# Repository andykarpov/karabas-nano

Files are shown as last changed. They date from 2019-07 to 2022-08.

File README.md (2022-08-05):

# Karabas-Nano

**Yet another ZX Spectrum clone ;)**

## Intro

ZX Spectrum compatible machine with real **Z80** CPU and all logic inside the CPLD Altera **EPM3256ATC144** (or EPM7512).

## The idea

The idea was to learn KiCAD and make a **cheapest** and **smallest** ZX Spectrum clone with minimum components and real CPU. 
Some parts of this schematics are grabbed from the **Karabas-128** and **ZX-UNO** projects (like RGB DAC, PAL coder, Tape-in logic).
The heart of this project is a real SMD Z80 CPU and ULA implementation on Altera CPLD EPM3256ATC144. 

## Firmwares

The board contains an SD card socket, so at least 2 different configurations are supported:

1) Z-Controller based configuration (Pentagon timings, GLUK reset service in the ROM bank 0, 1024kB of extended memory via port #DFFD (Profi))

2) DivMMC based configuration (Pentagon timings, ESXDOS 0.8.7 in the ROM bank 0, 128kB of memory)

## More info

**ERRATA for PCB rev.A:** [Russian](https://github.com/andykarpov/karabas-nano/blob/master/ERRATA_revA.md).

**ERRATA for PCB rev.B:** [Russian](https://github.com/andykarpov/karabas-nano/blob/master/ERRATA_revB.md).

**Latest revision:** rev.I.

License for this project is **WTFPL**. [More details here](https://github.com/andykarpov/karabas-nano/blob/master/LICENSE.md).

### Pre-production renders

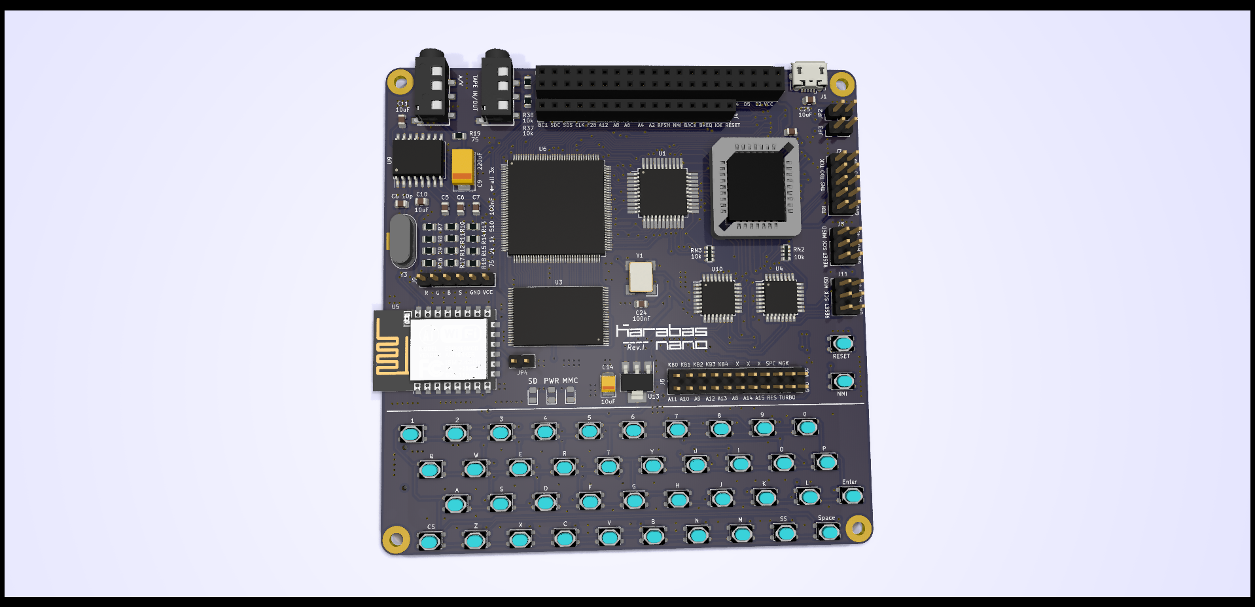
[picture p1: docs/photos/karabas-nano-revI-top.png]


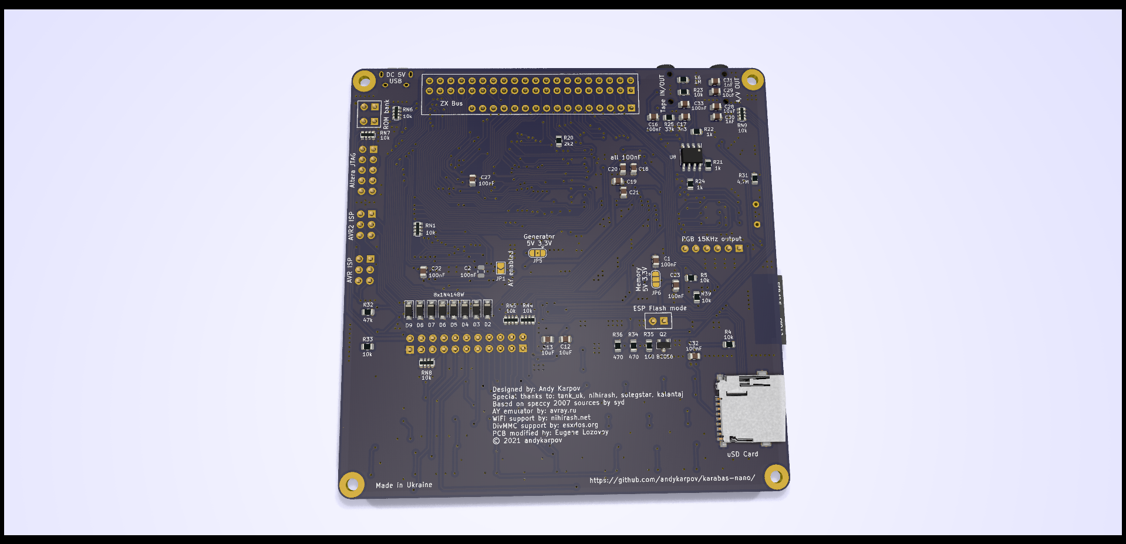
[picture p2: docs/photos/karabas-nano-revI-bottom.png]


### PCB Rev. H assembly example by [Xoomoh (Михайло Капітанов)](https://github.com/xoomoh/)

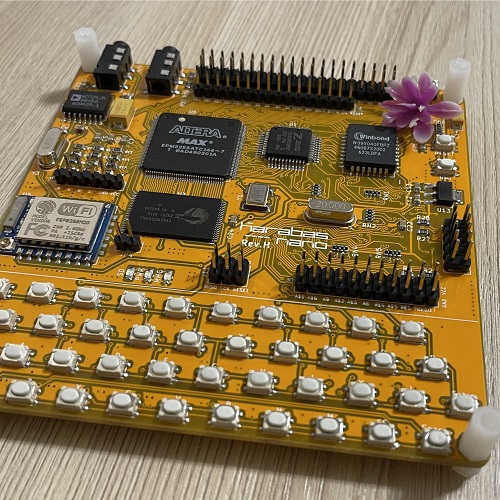
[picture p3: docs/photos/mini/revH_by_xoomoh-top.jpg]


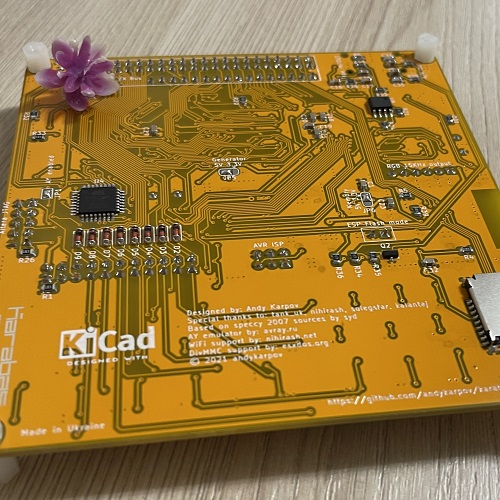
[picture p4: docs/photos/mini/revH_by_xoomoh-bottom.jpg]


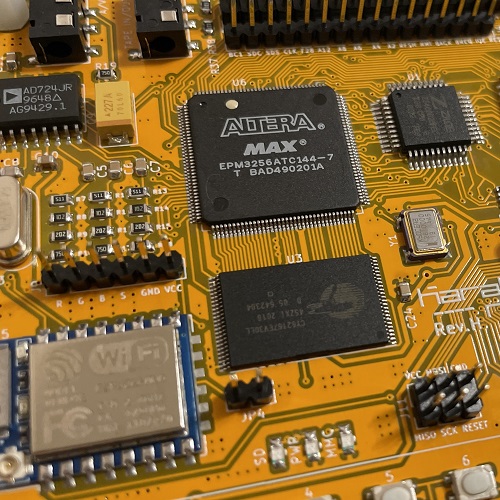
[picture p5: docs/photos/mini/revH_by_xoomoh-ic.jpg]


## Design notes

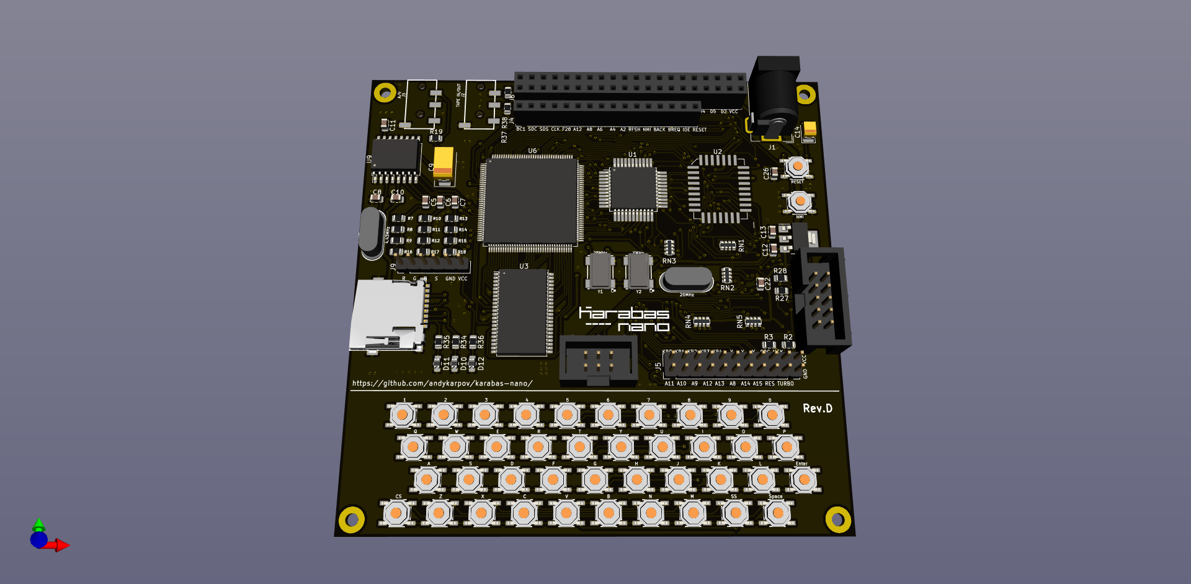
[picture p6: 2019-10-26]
docs/photos/revD-1.png

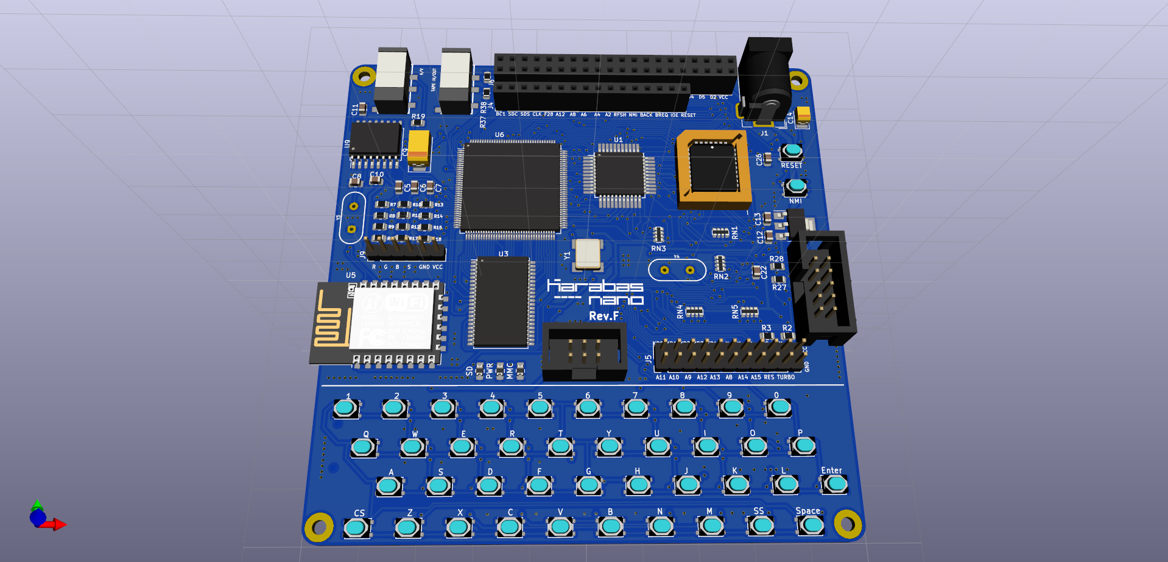
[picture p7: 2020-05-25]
docs/photos/revF-top.png

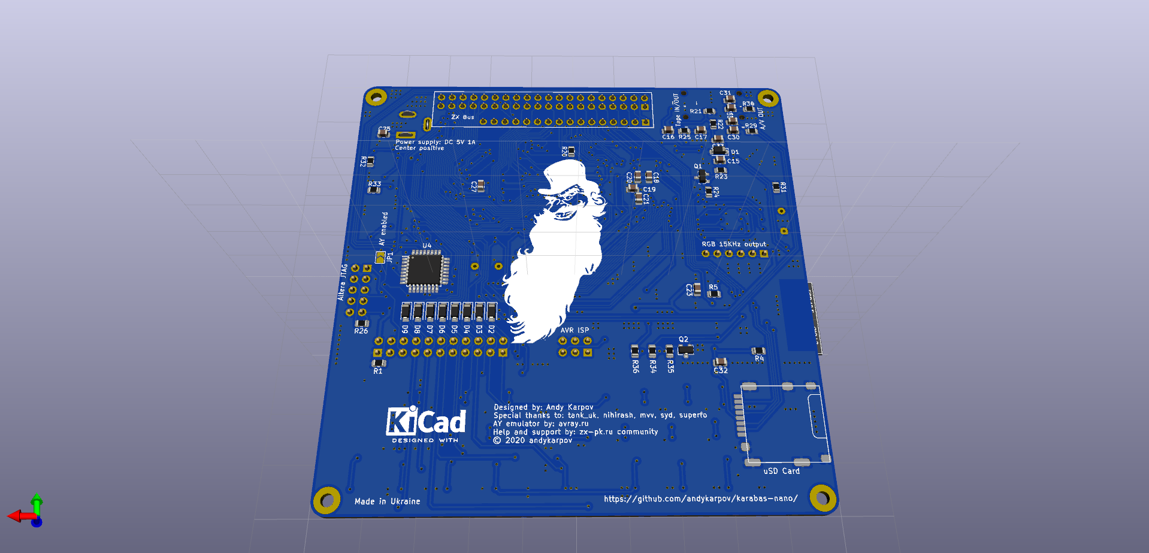
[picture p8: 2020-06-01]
docs/photos/karabas-nano-revG-bottom.png

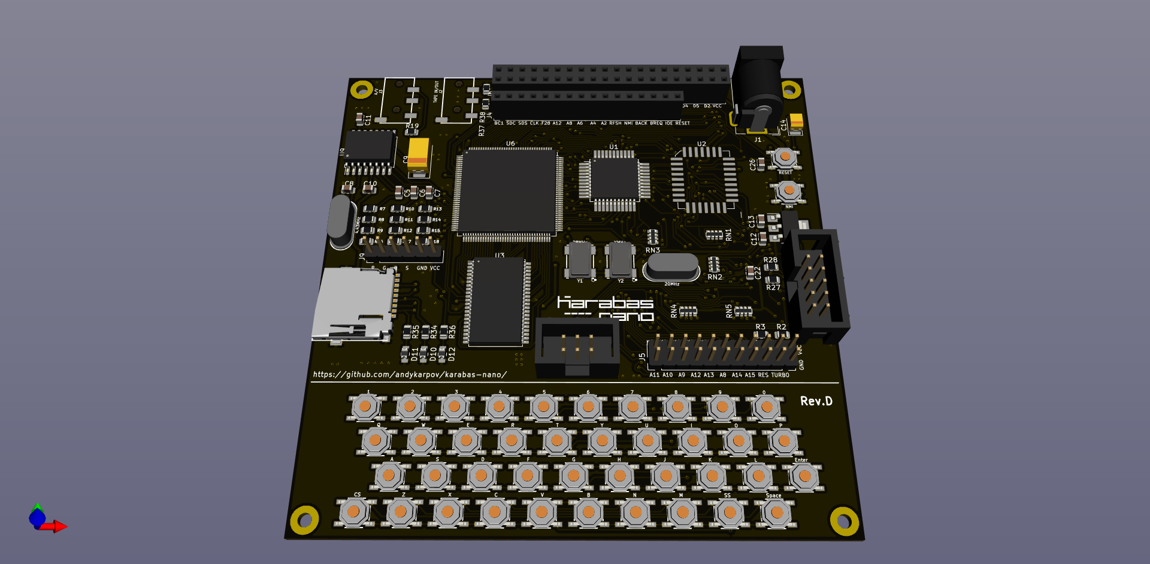
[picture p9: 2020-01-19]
docs/photos/revD.png

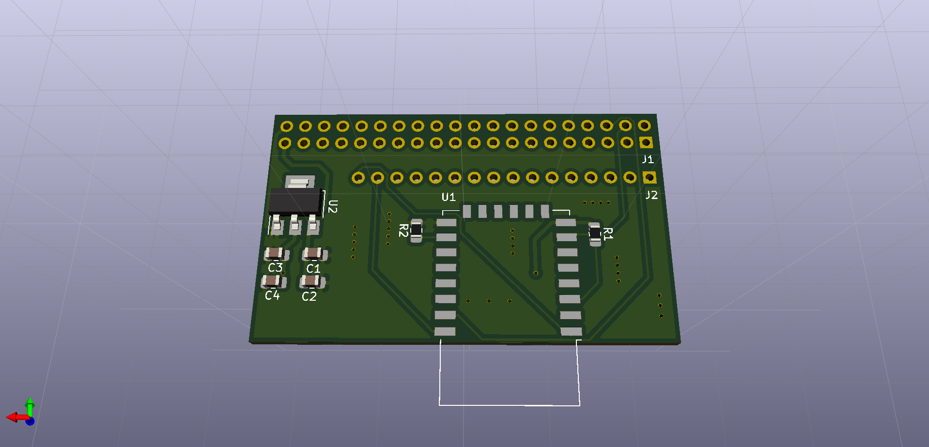
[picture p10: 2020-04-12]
docs/photos/wifi_revA-bottom.png

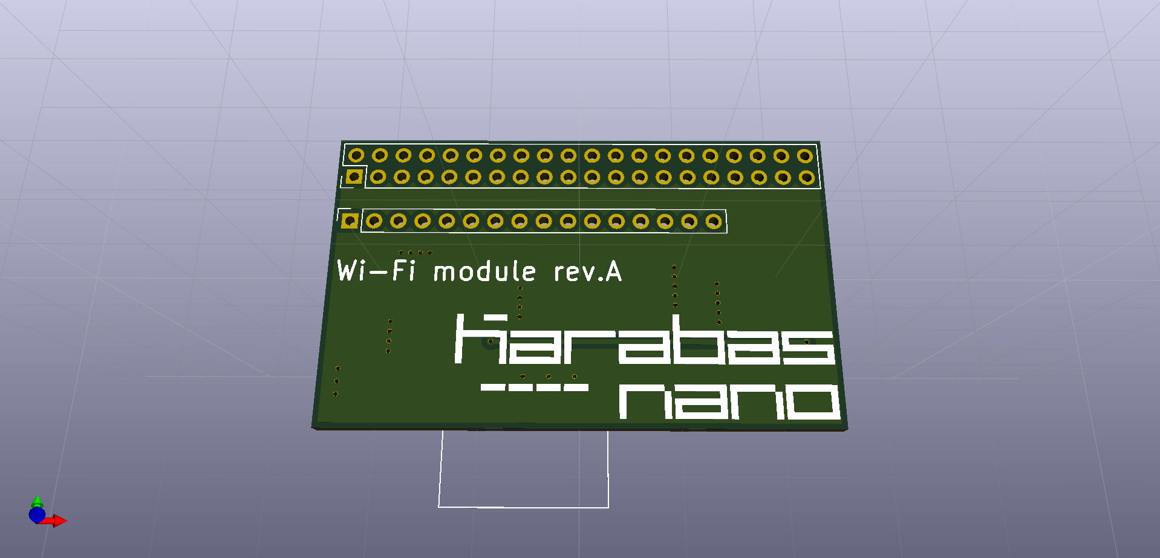
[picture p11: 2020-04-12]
docs/photos/wifi_revA.png

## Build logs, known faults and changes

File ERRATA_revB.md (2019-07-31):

1) BUS_N_ROMCS - нет pull-down 10к резистора в схеме и на плате
2) BUS_N_IORQGE - нет pull-down 10k резистора в схеме и на плате
3) TAPE_IN - нет конденсатона 10нФ последовательно с R22 в схеме и на плате
4) Footprint под Z80 имеет некоррентный размер QFP-10x10mm, а нужен QFP-12x12mm, приходится гнуть ноги у процессора
5) Разъем JTAG - если ставить shrouder header, налазит на рядом стоящие резисторы (подвинуть или одно, или другое)
6) SRAM - отсутствует подача питания на пины 11 - VCC, 12 - GND (как оказалось - не критично).
7) LED - необходим светодиод для индикации подачи питания на плату (предусмотреть)
8) Нет возможности зашить Atmega8 на плате, нужно вывести JTAG пины и возможность не питать всю схему при программировании AVR (solder jumper?)
9) Нет джампера для (возможного) одключения DivMMC в режиме DivMMC.
10) У разъема клавиатуры нет выхода +5,GND для питания внешнего контроллера, предусмотреть, согласовать с разводкой ps2_avr_cpld
11) Нет pull-up резистора на линии SD_NCS, не критично, но нужно предусмотреть
12) Генератор: на 28МГц на 74HTC04 заводится с трудом, выкинуть C1 и заменить перемычкой, заменить в схеме 74HC04 на ACT или F серию, пересчитать номиналы
13) Footprint у 27C512 имеет достаточно короткие пятаки, паять панель руками очень неудобно. Предусмотреть либо длинные PADы, либо другую панель (THT).
14) Кварц на 4.43 МГц нужно заземлить, как и остальные кварцы по возможности
15) Параллельно кварцу на 4.43 МГц предусмотреть резистор на 4.7 МОм
16) Держатель карты SD нужно заземлить
17) Для того, чтобы конденсатор C14 полностью разряжался, для нормального старта конфы DivMMC, необходимо параллельно ему предусмотреть резистор на 47к.
18) Кнопку NMI лучше заводить не на процессор N_MNI, а через модуль DivMMC, который устранит дребезг и включит NMI только при всех условиях, разрешающих его
19) Предусмотреть светодиоды активности DivMMC (mapcond, cs)
20) Добавить подписи контактов на ZX-BUS, KBD хедерах

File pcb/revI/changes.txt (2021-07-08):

Изменения относительно ревизии H:
1. Добавлена вторая ATmega для TurboSound;
2. ATmega тактируется от 28МГц вместо 20МГц. В связи с этим вместо ATmega8 рекомендуется ATmega88;
3. Изменена распиновка AV-выхода для совместимости с кабелями от Raspberry Pi;
4. Перемещены разъёмы программирования CPLD и AVR, а так же кнопки Reset и NMI;
5. Диаметр отверстий в углах платы изменён с 2.5 до 2.7мм.

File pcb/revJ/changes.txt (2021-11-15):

Изменения относительно ревизии I:
1. Изменен футпринт TRRS разъемов, можно ставить выводные вместо SMD
2. Добавлены джамперы переключения типа AV кабеля

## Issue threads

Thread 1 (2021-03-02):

Перепутаны левый и правый каналы аудио

UzixLS, 2021-03-02:
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
Вроде как должно быть наоборот. Но со стороны AVR-AY тоже может быть неправильный порядок, в их референсной схеме есть оба варианта :)

Cтандартная распиновка:
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

andykarpov, 2021-07-08:
хммм... спасибо за инфу, теперь даже хз, как проще сделать.

есть 3 варианта:
- забить и оставить как есть :)
- переделать схему и выпустить новую ревизию платы
- переключить программно в прошивке меги

склоняюсь больше к первому варианту :)))

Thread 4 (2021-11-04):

Revision I

awesome1possum, 2021-11-04:
Ревизия I в ручном режиме открывается в DipTrace.
Но не могу импортировать в онлайн PCB-делалку, только ревизия H (и более ранние). Скрипт пишет что не может определить границы платы, а так же пишет что почему-то нестандартное название файлов.

andykarpov, 2022-02-02:
начина с ревизии I проект делался в KiCAD 6.0, отсюда могут быть вопросы.
сервис pcbway.com нормально кушает эти герберы, у jlc были какие-то вопросы :)

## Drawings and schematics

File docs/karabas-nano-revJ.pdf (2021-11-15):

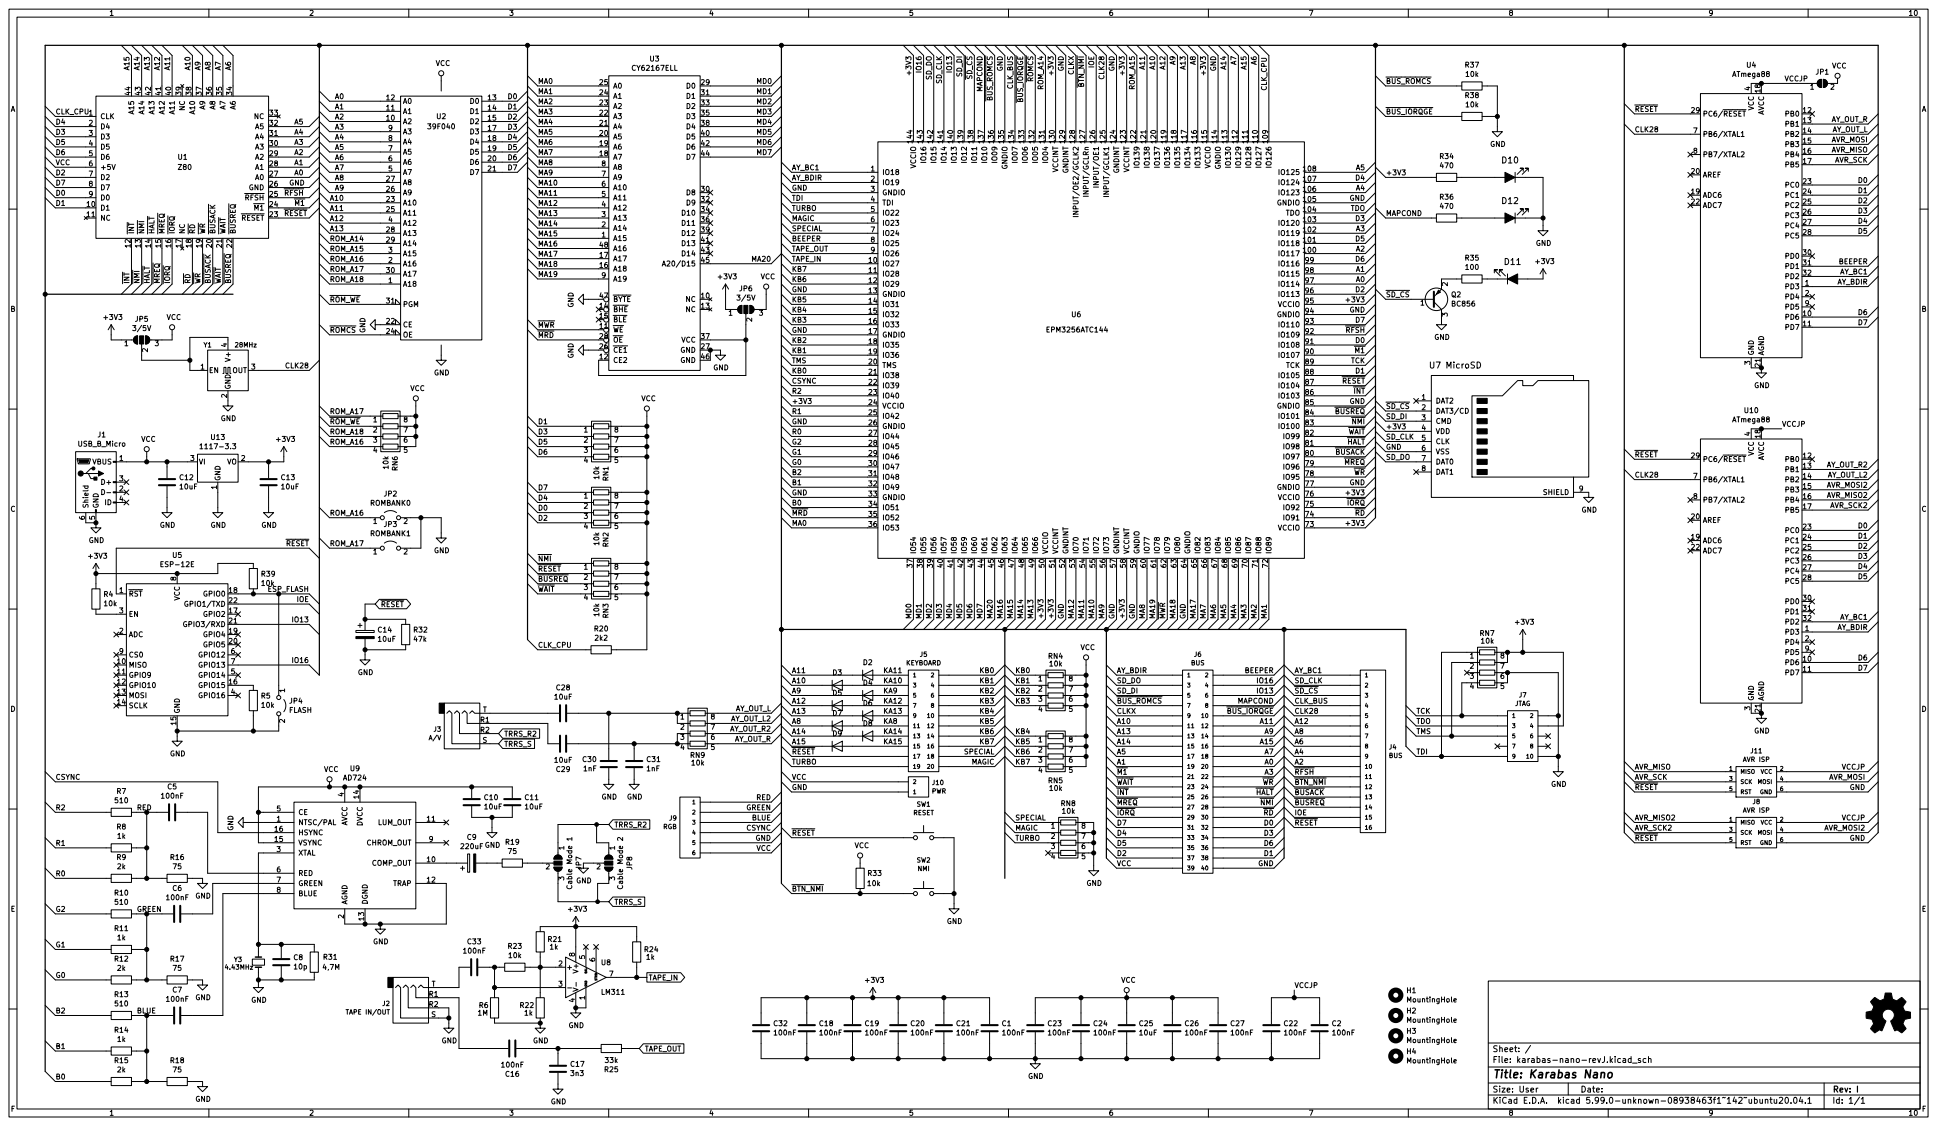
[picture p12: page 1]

4 CE 5 RED 6 GREEN 7 BLUE 8 CHROM_OUT 9 U9 AD724 GND
GND

J2 TAPE IN/OUT GND

File: karabas-nano-revJ.kicad_sch Sheet: /
Id: 1/1 Title: Karabas Nano

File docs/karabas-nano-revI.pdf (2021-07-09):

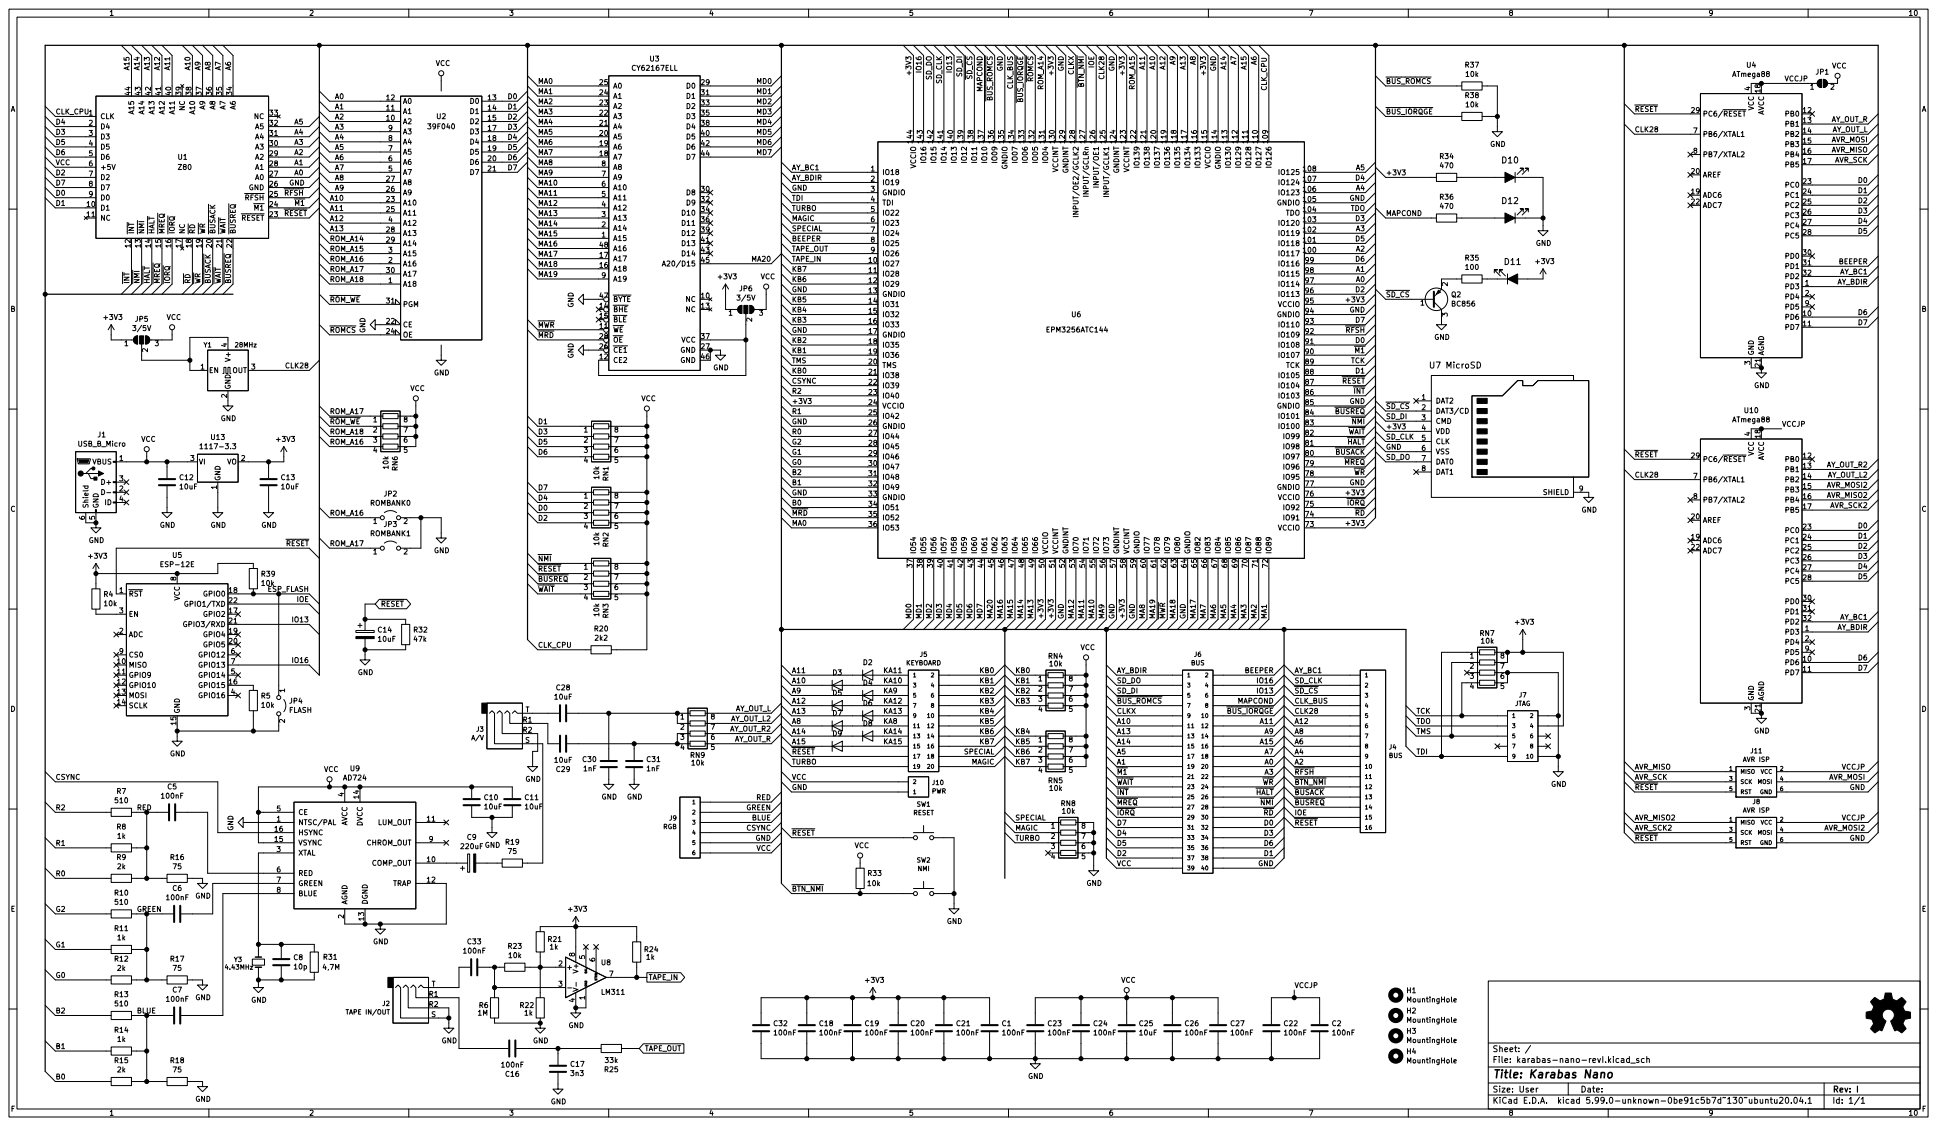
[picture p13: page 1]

4 CE 5 RED 6 GREEN 7 BLUE 8 CHROM_OUT 9 U9 AD724 GND

File: karabas-nano-revI.kicad_sch Sheet: / S

Id: 1/1 Title: Karabas Nano

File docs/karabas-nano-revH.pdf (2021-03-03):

10k R38

470R35

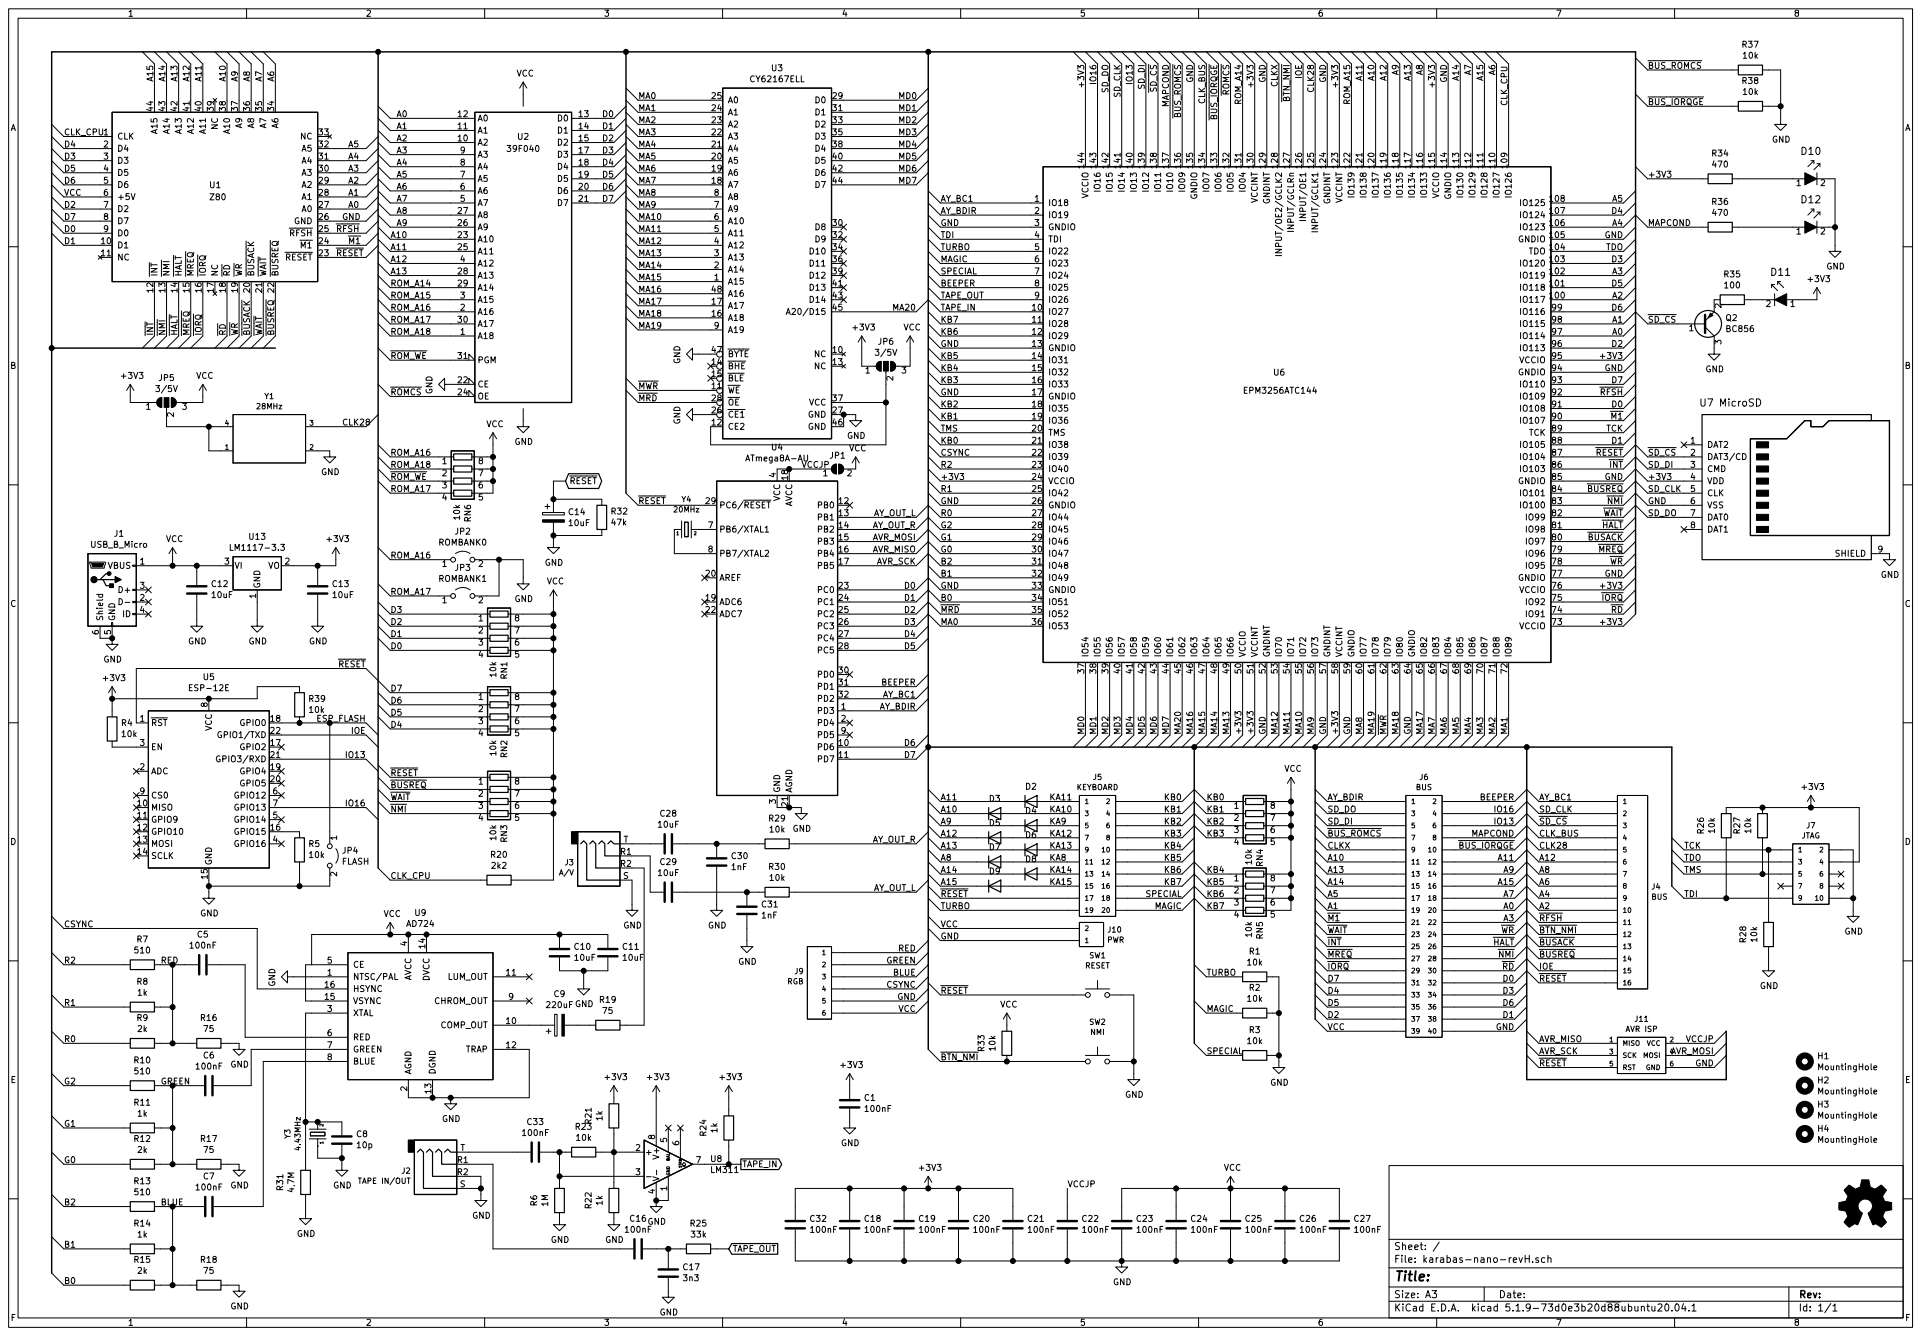
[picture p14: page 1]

4 CE 5 RED 6 GREEN 7 BLUE 8 CHROM_OUT 9 U9 AD724 GND

NMI WAIT HALT BUSACK

Id: 1/1 Title: File: karabas-nano-revH.sch Sheet: / R12

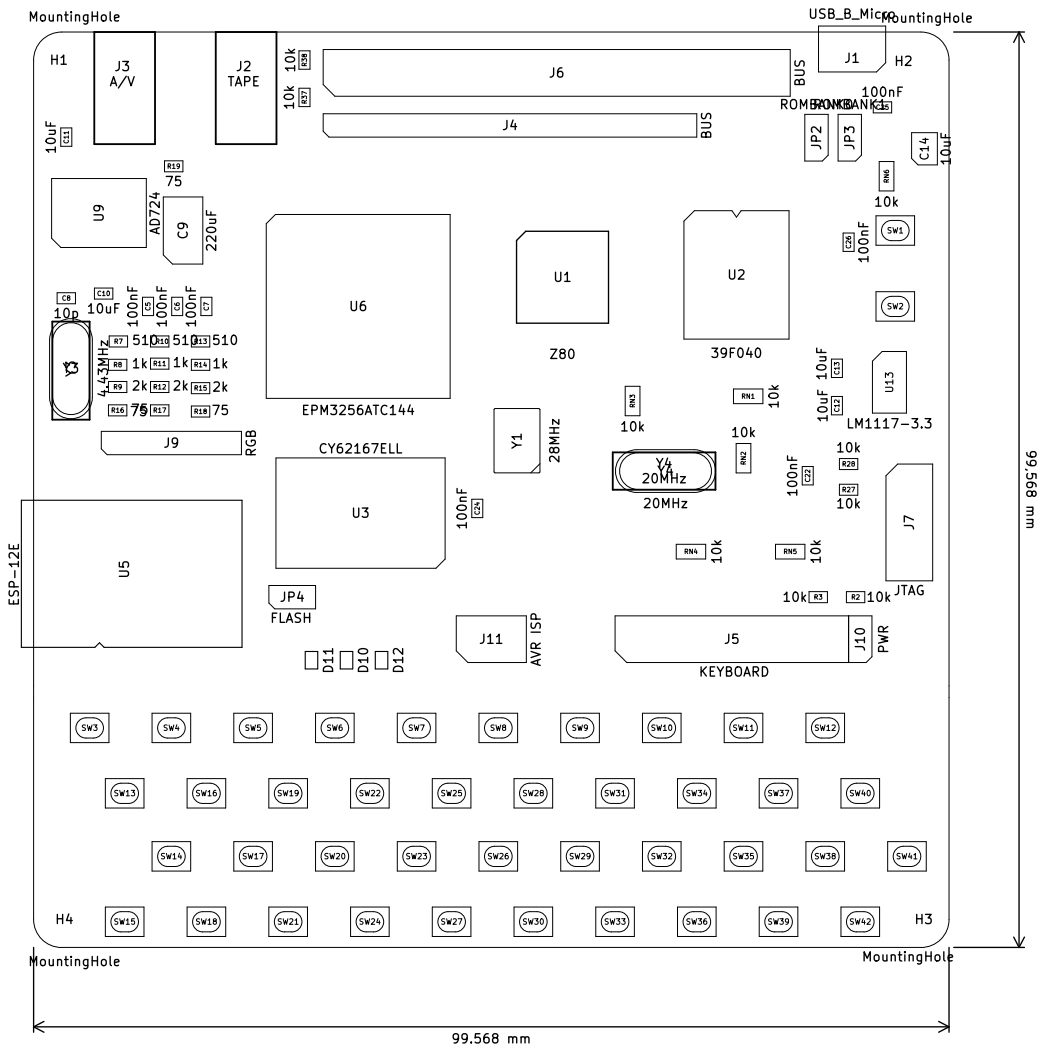
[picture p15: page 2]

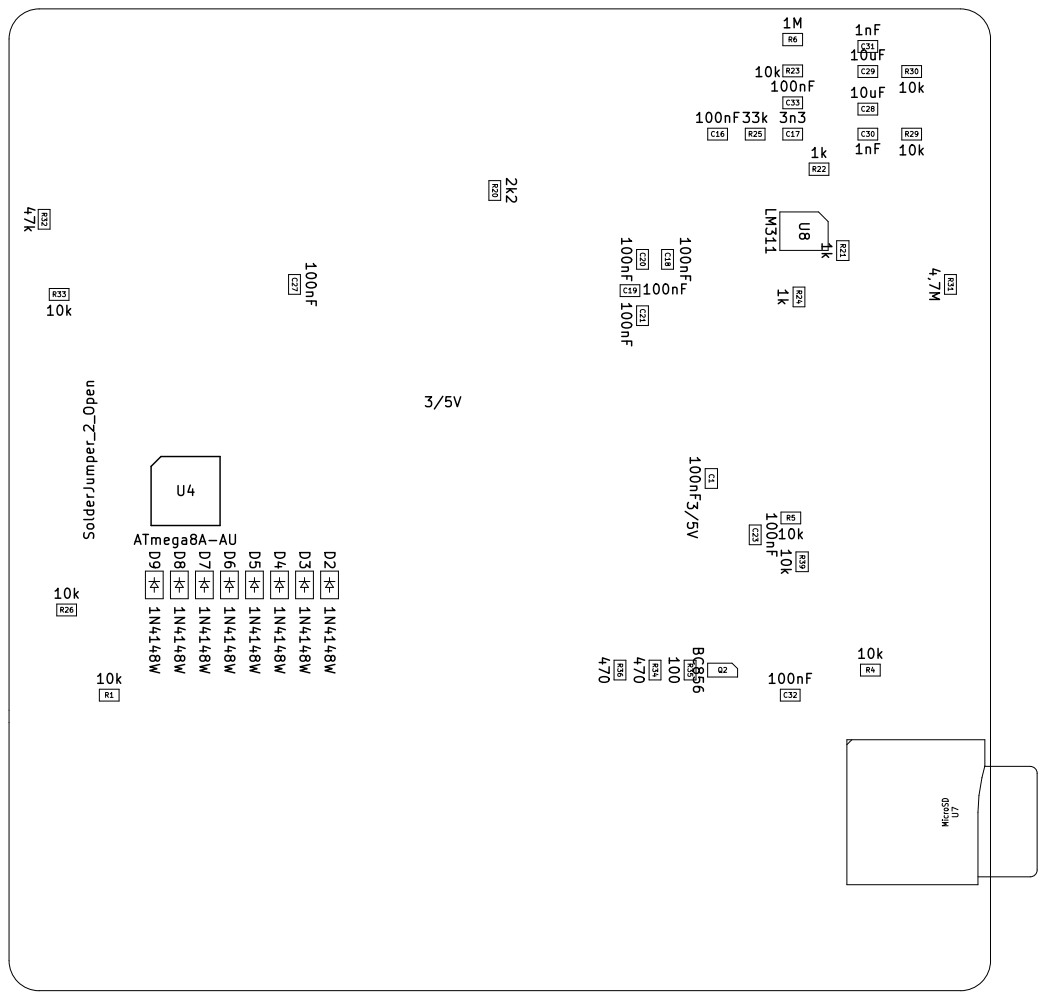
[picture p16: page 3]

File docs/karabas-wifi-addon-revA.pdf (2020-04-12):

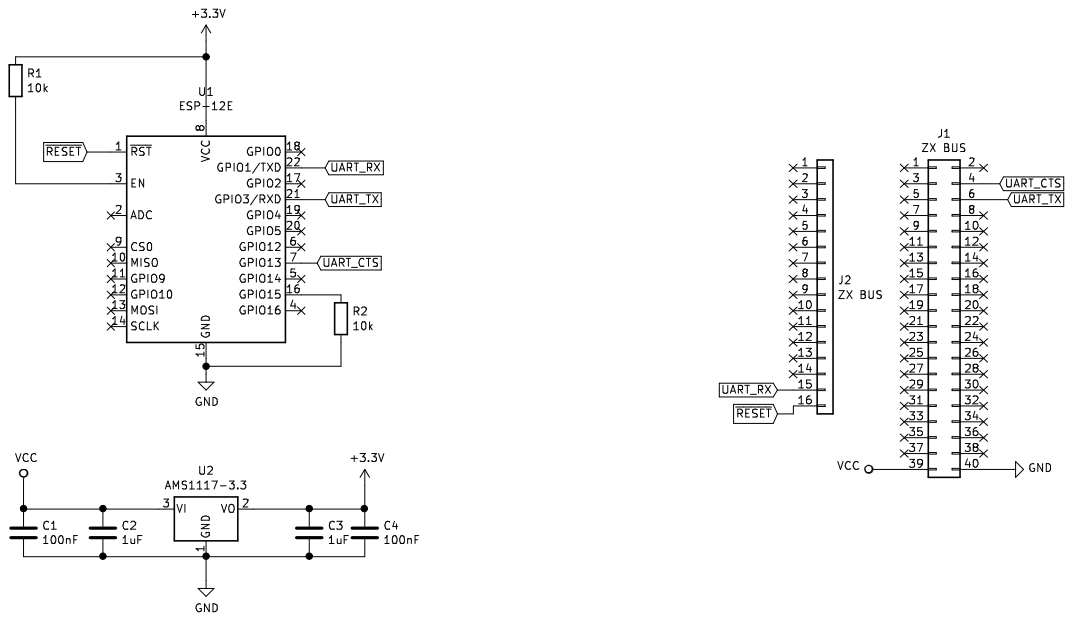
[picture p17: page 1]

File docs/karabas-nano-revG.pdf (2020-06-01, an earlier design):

# IO19 2 TMS 20

# IO46 29 GNDIO 3

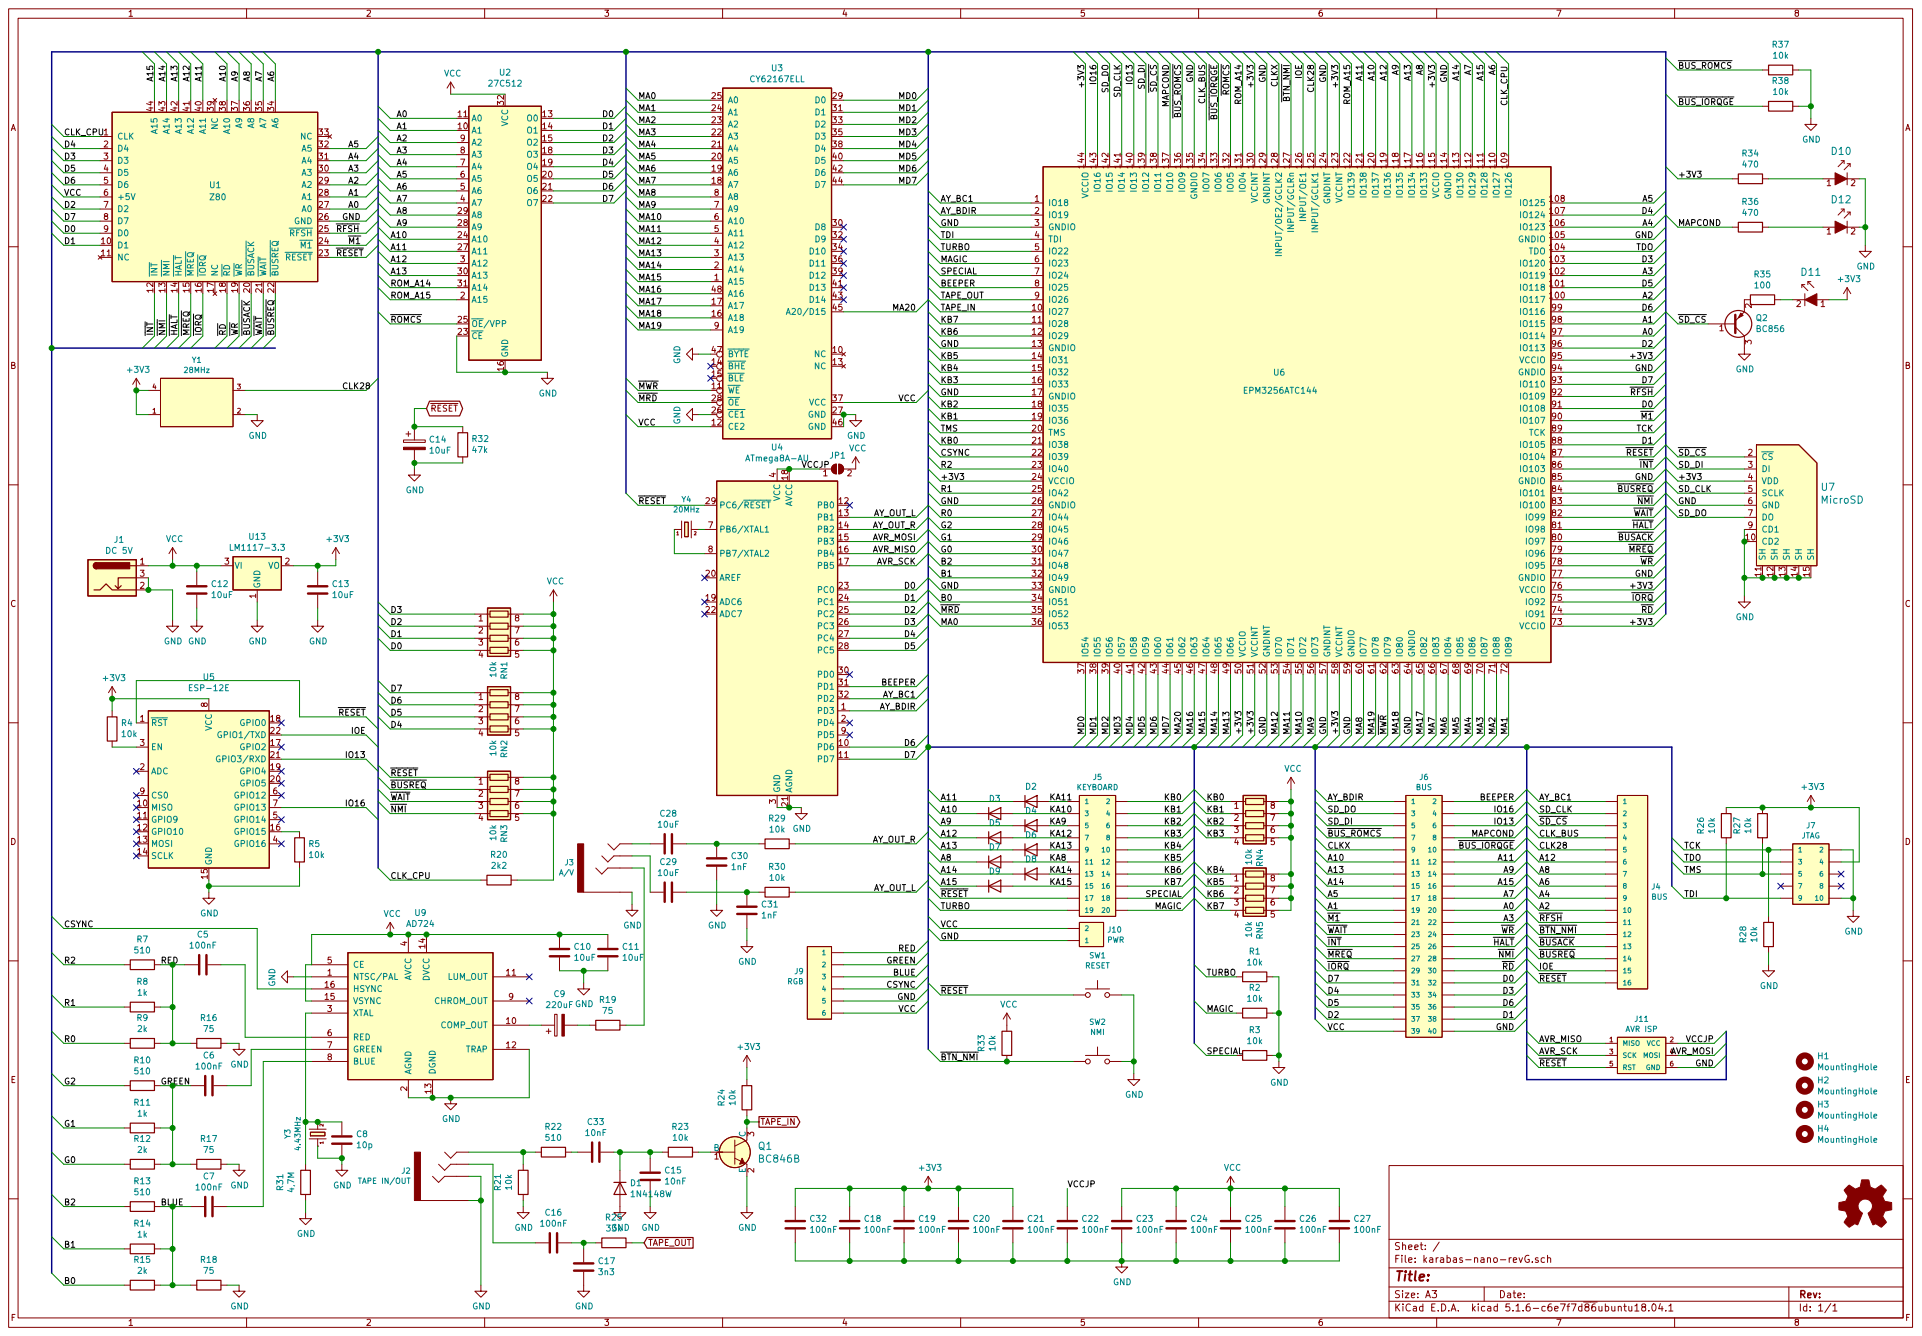
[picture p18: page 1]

RESET BUSREQ WAIT NMI

4 CE 5 RED 6 GREEN 7 BLUE 8 CHROM_OUT 9 U9 AD724

Id: 1/1 Title: File: karabas-nano-revG.sch Sheet: / GND

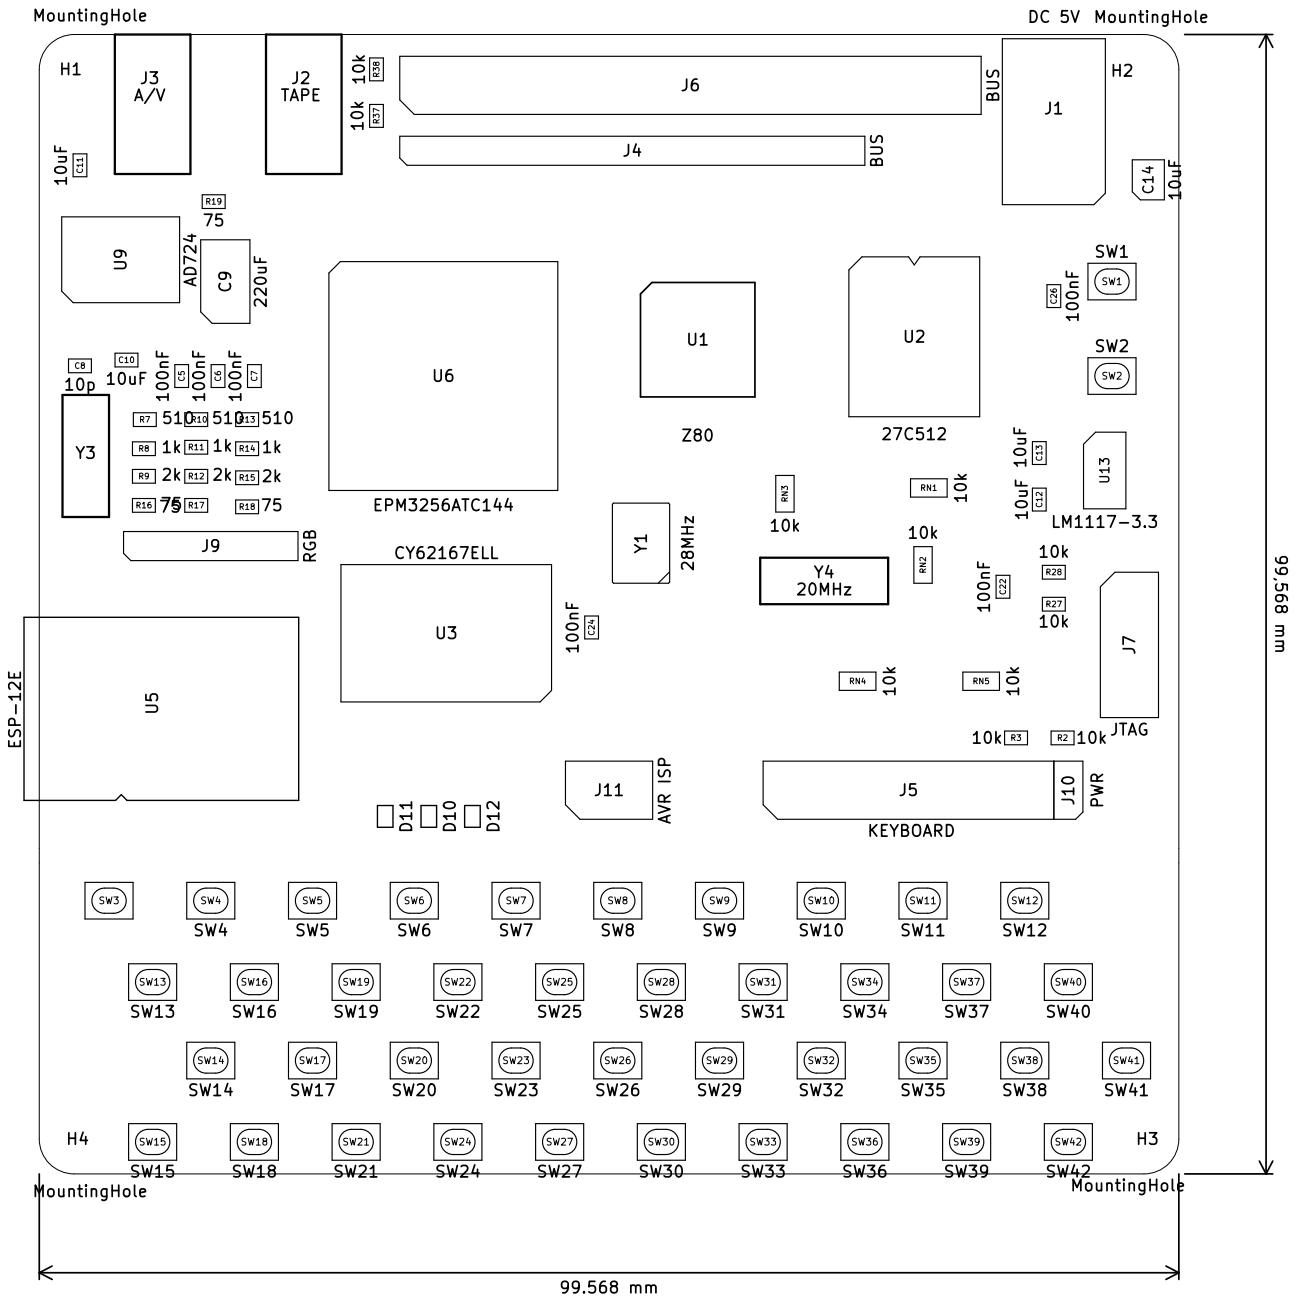
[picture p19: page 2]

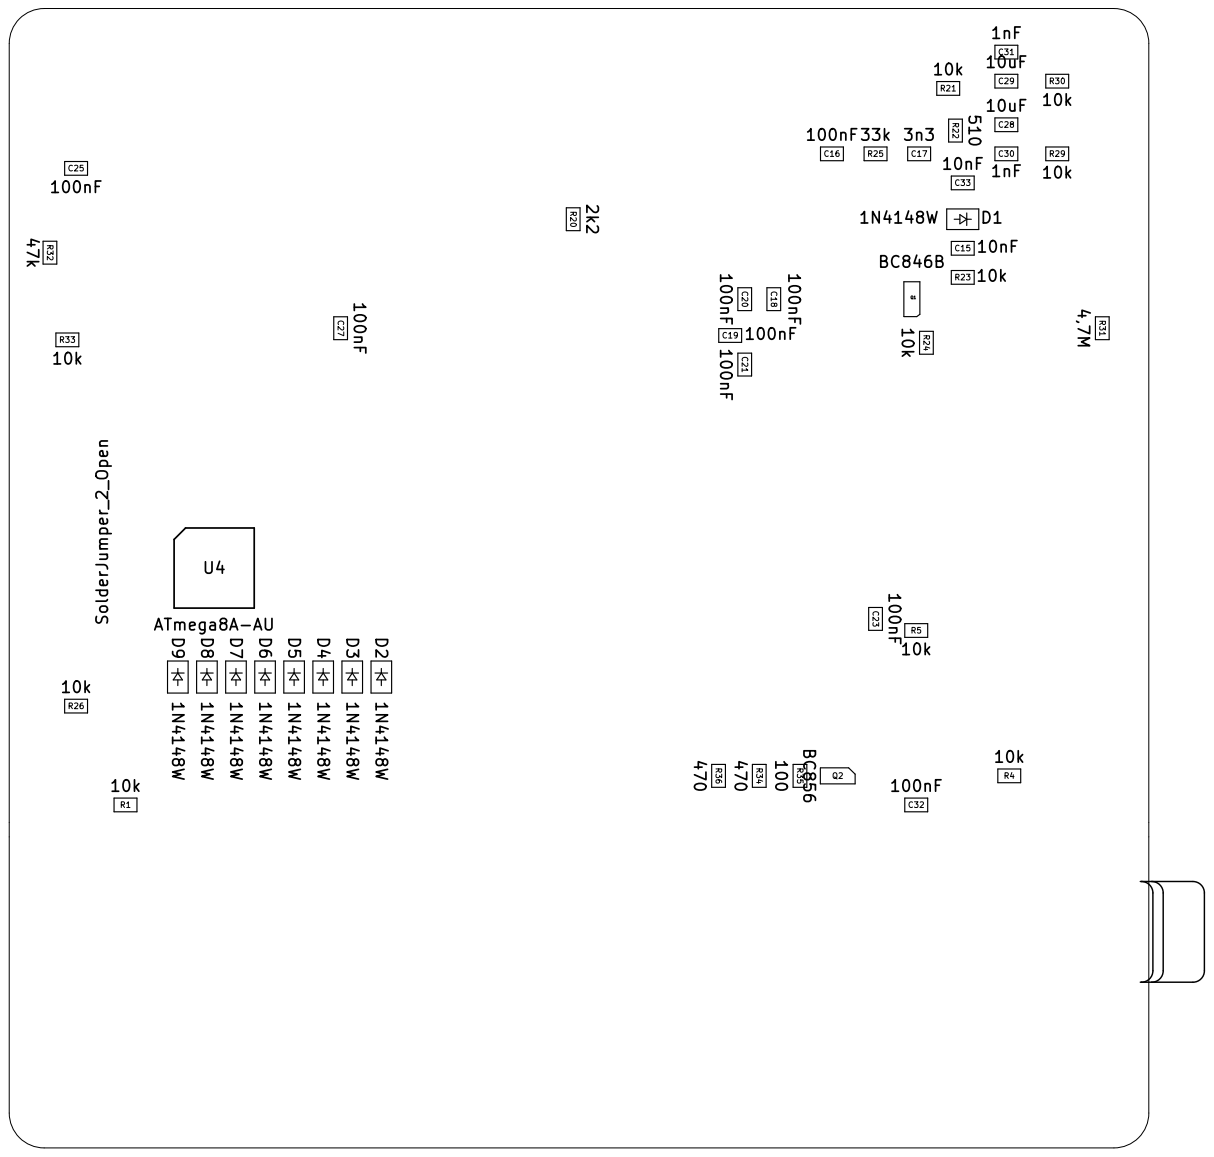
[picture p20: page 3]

# karabas-nano-revG

# Страница 1

Reference | Q-ty | Value | Footprint
C10 C11 C12 C13 C28 C29 | 6 | 10uF | 0805
C14 | 1 | 10uF | Tantalum B
C15 C33 | 2 | 10nF | 0805
C17 | 1 | 3n3 | 0805
C30 C31 | 2 | 1nF | 0805
C16 C18 C19 C20 C21 C22 C23 C24 C25 C26 C27 C32 C5 C6 C7 | 15 | 100nF | 0805
C8 | 1 | 10p | 0805
C9 | 1 | 220uF | Tantalum D
D1 D2 D3 D4 D5 D6 D7 D8 D9 | 9 | 1N4148W | SOD-123
D10 D11 D12 | 3 | RED/GREEN/YELLOW | 0805
J1 | 1 | DC 5V | 5x2.1mm jack
J10 | 1 | PWR | 1x02
J11 | 1 | AVR ISP | 2x03
J2 | 1 | TAPE IN/OUT | TRRS SMD
J3 | 1 | A/V | TRRS SMD
J4 | 1 | BUS | 1x16
J5 | 1 | KEYBOARD | 2x10
J6 | 1 | BUS | 2x20
J7 | 1 | JTAG | 2x05
J8 | 1 | KEYBOARD | 2x08
J9 | 1 | RGB | 1x06
Q1 | 1 | BC846B | SOT-23-3
Q2 | 1 | BC856 | SOT-23-3
R10 R13 R22 R7 | 4 | 510 | 0805
R16 R17 R18 R19 | 4 | 75 | 0805
R20 | 1 | 2k2 | 0805
R1 R2 R3 R4 R5 R21 R23 R24 R26 R27 R28 R29 R30 R33 R37 R38 | 16 | 10k | 0805
R25 | 1 | 33k | 0805
R31 | 1 | 4,7M | 0805
R32 | 1 | 47k | 0805
R34 R35 R36 | 3 | 470 | 0805
R11 R14 R8 | 3 | 1k | 0805
R12 R15 R9 | 3 | 2k | 0805
RN1 RN2 RN3 RN4 RN5 | 5 | 10k | 4x0612
SW1 — SW42 | 42 | SPST PTS810 | SPST PTS810
U1 | 1 | Z84C0010AEG | QFP-44
U13 | 1 | LM1117-3.3 | SOT-223
U2 | 1 | 27C512 | PLCC-32 SMD
U3 | 1 | CY62167ELL | TSOP-I-48
U4 | 1 | ATmega8A-AU | TQFP-32
U5 | 1 | ESP8266 | ESP-12F
U6 | 1 | EPM3256ATC144 | LQFP-144
U7 | 1 | MicroSD | Molex 49225-0821
U9 | 1 | AD724 | SOIC-16W
Y1 | 1 | 28MHz | 0705
Y3 | 1 | 4.43MHz | HC49US
Y4 | 1 | 20MHz or 24MHz | HC49US

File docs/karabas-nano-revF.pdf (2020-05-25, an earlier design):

A4 1 | D1 10 VCC 11 GND 12 D2 13 D3 14 NC 15 A20 16 WE 17 A19 18 A18 19 A3 2 A17 20 A16 21 A15 22 A14 23 A13 24 A12 25 A11 26 A10 27 A9 28 | NC 29 A2 3 | NC 30 D4 31 D5 32 VCC 33 GND 34 D6 35 D7 36 NC 37 NC 38 A8 39 A1 4 CE2 40 OE 41 A7 42 A6 43 A5 44 A0 5 CE1 6 | NC 7 NC 8 D0 9 U3 BS62LV1600

# IO19 2 TMS 20

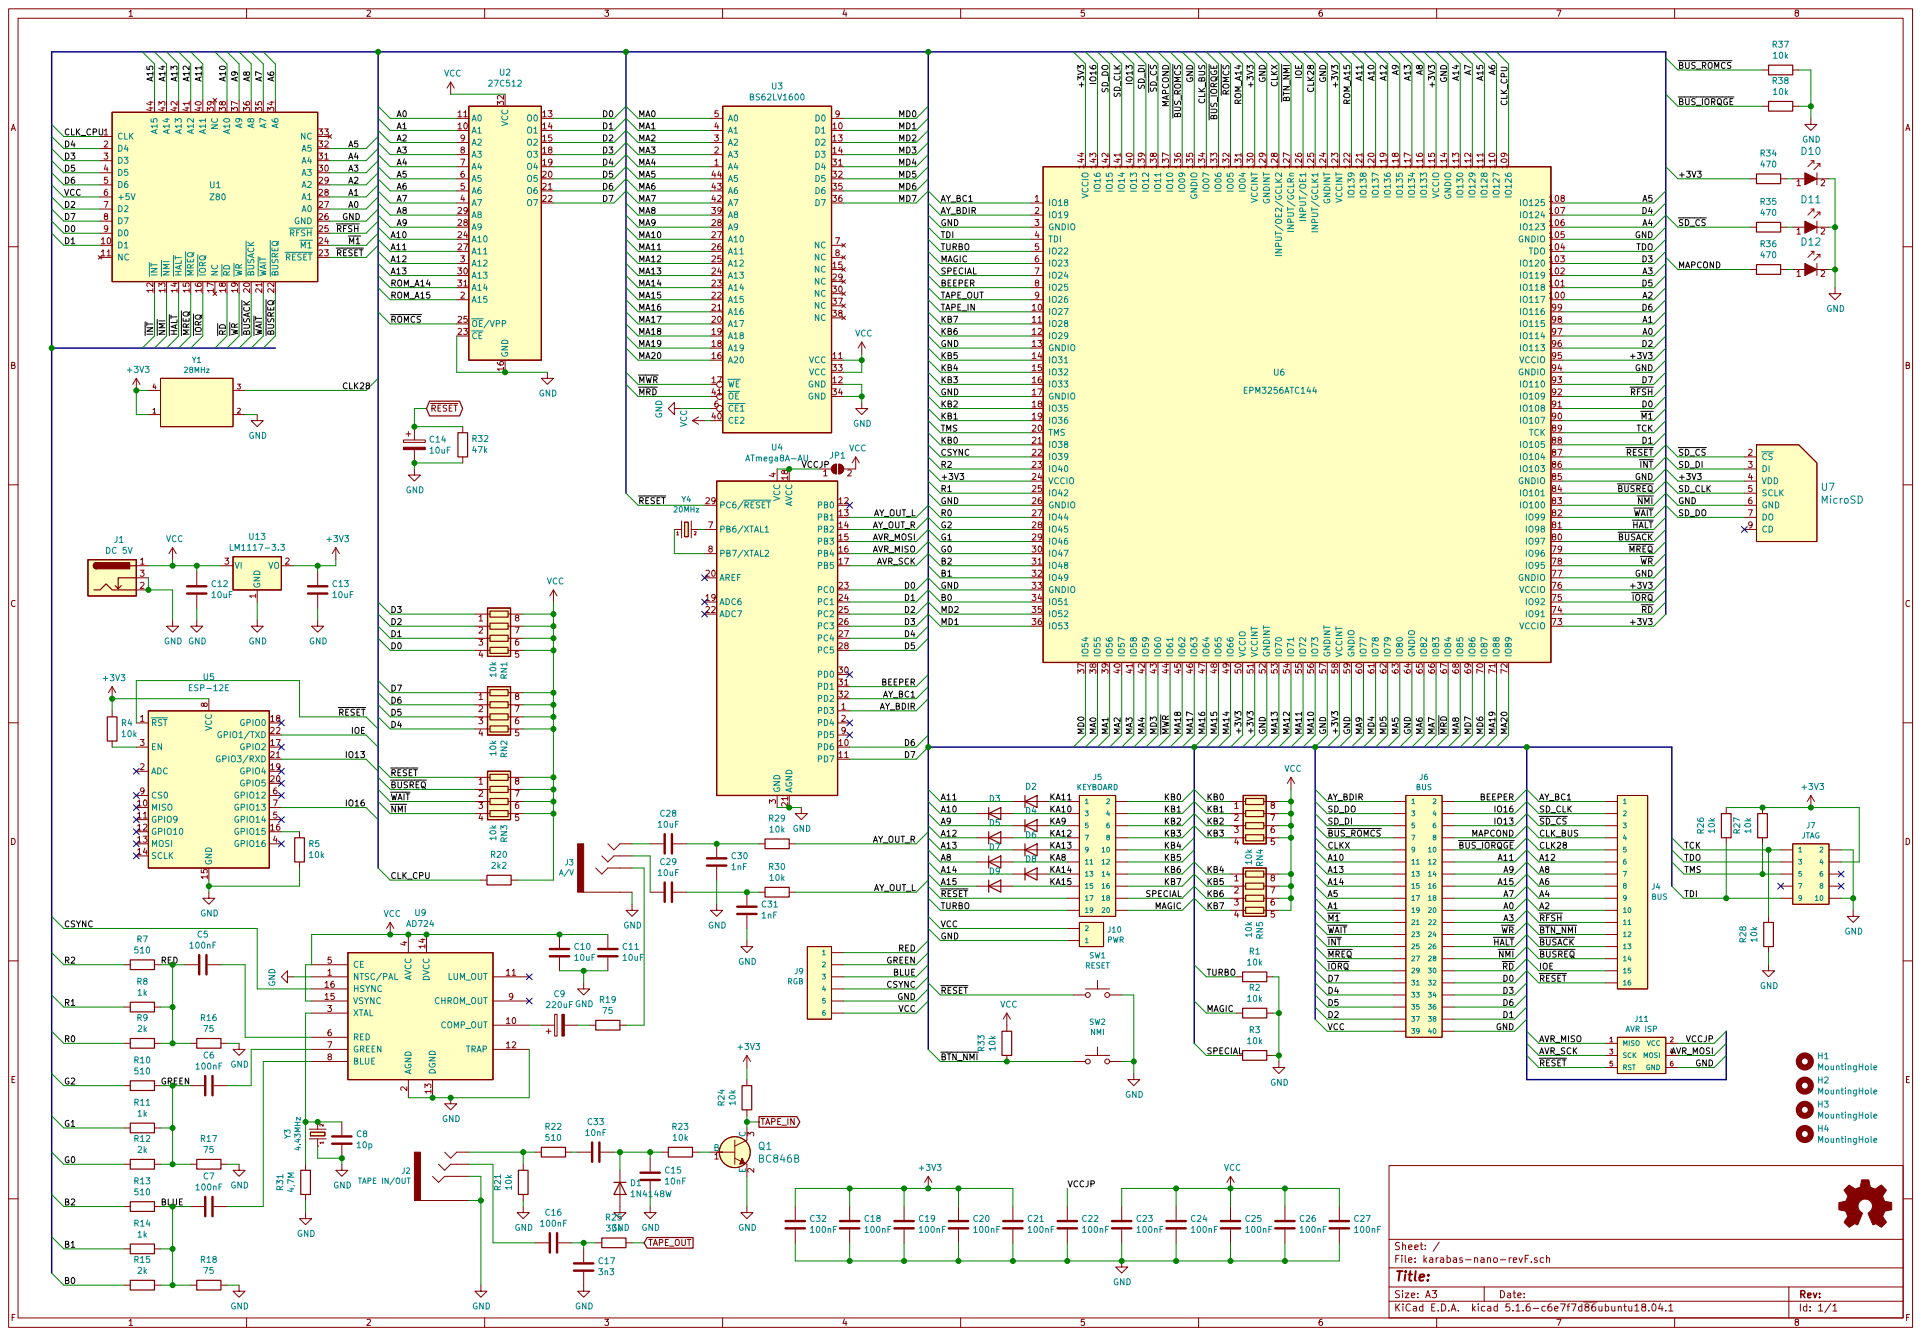
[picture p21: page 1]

NMI WAIT HALT BUSACK MREQWR

4 CE 5 RED 6 GREEN 7 BLUE 8 CHROM_OUT 9 U9 AD724

Id: 1/1 Title: File: karabas-nano-revF.sch Sheet: / R23

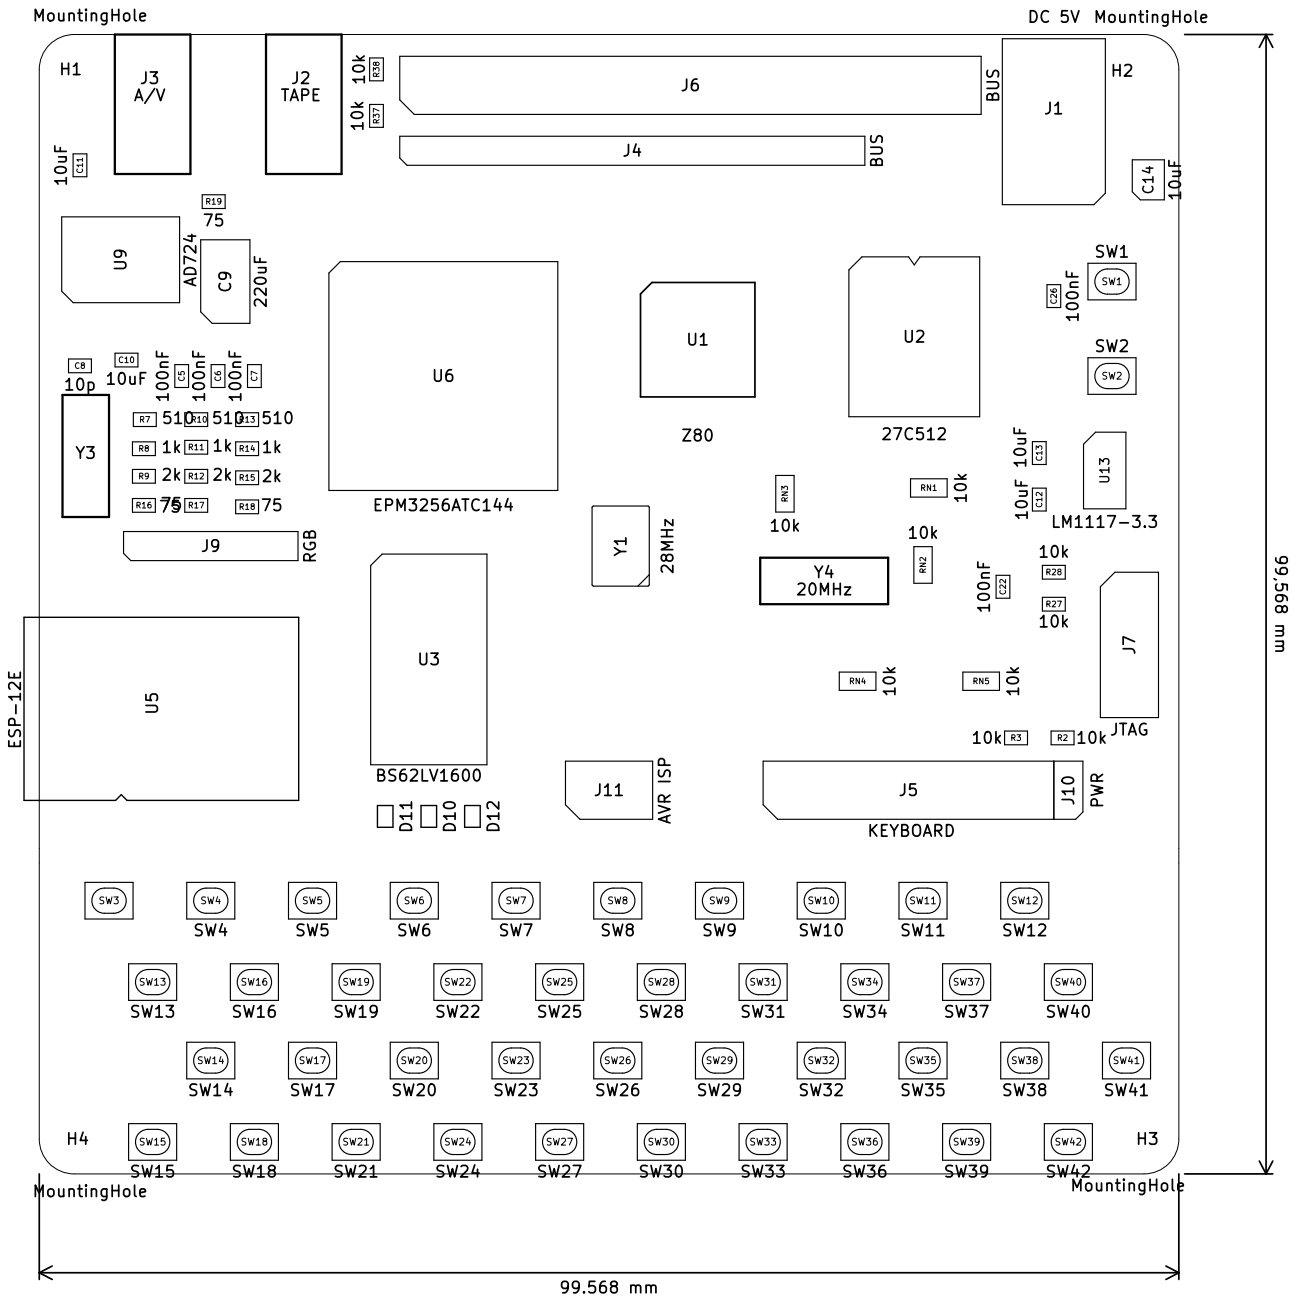
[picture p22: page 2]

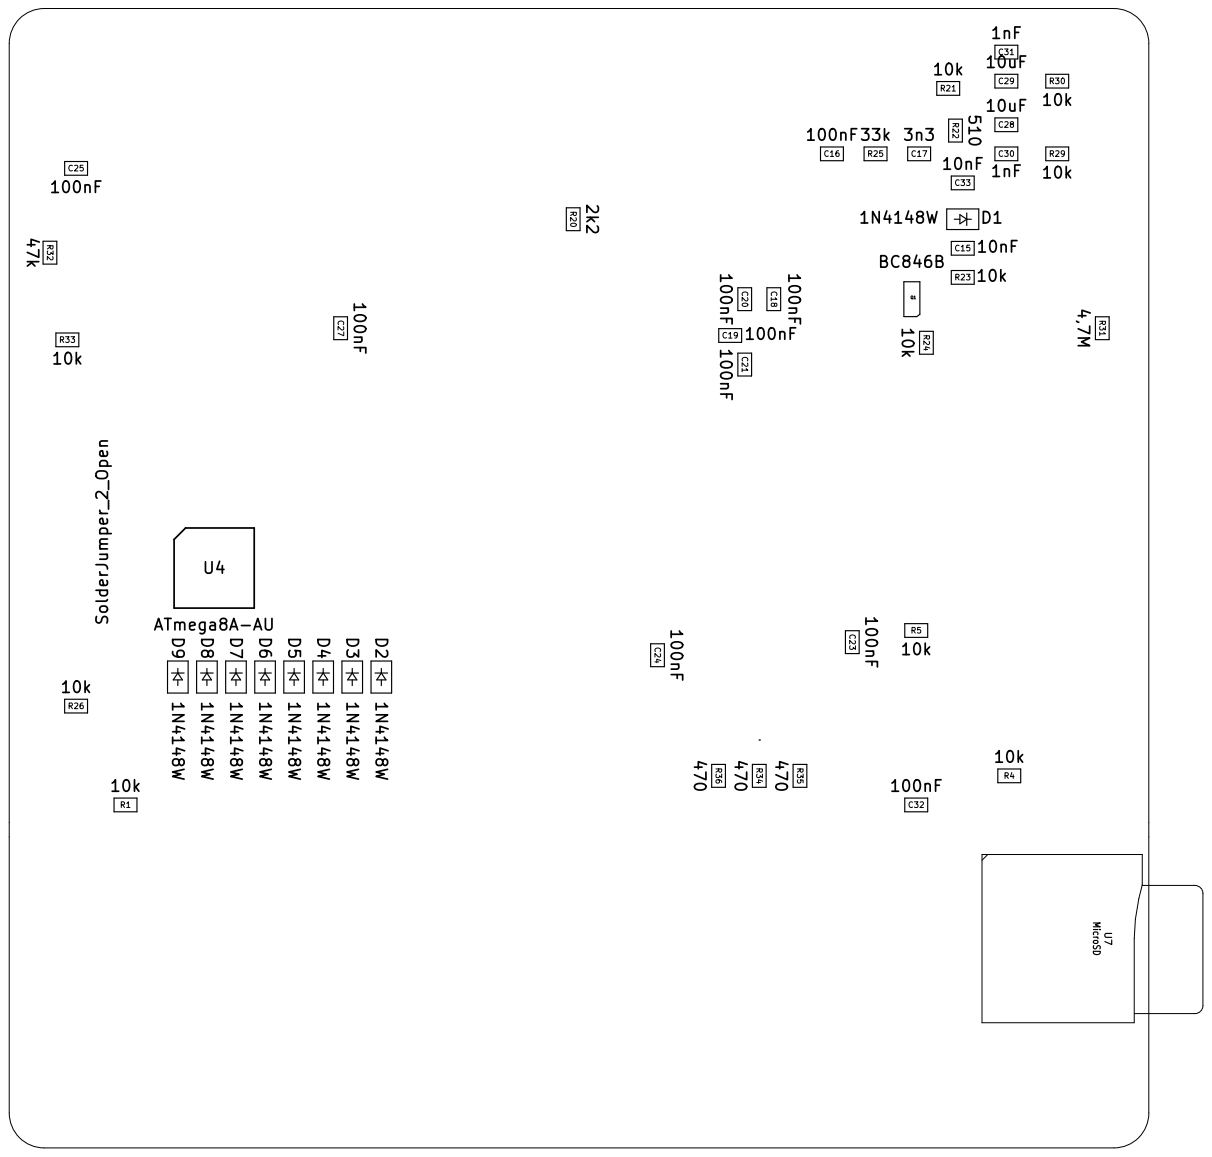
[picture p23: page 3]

# karabas-nano-revE

# Страница 1

Reference | Q-ty | Value | Footprint
C10 C11 C12 C13 C28 C29 | 6 | 10uF | 0805
C14 | 1 | 10uF | Tantalum B
C15 C33 | 2 | 10nF | 0805
C17 | 1 | 3n3 | 0805
C30 C31 | 2 | 1nF | 0805
C16 C18 C19 C20 C21 C22 C23 C24 C25 C26 C27 C32 C5 C6 C7 | 15 | 100nF | 0805
C8 | 1 | 10p | 0805
C9 | 1 | 220uF | Tantalum D
D1 D2 D3 D4 D5 D6 D7 D8 D9 | 9 | 1N4148W | SOD-123
D10 D11 D12 | 3 | RED/GREEN/YELLOW | 0805
J1 | 1 | DC 5V | 5x2.1mm jack
J10 | 1 | PWR | 1x02
J11 | 1 | AVR ISP | 2x03
J2 | 1 | TAPE IN/OUT | TRRS SMD
J3 | 1 | A/V | TRRS SMD
J4 | 1 | BUS | 1x16
J5 | 1 | KEYBOARD | 2x10
J6 | 1 | BUS | 2x20
J7 | 1 | JTAG | 2x05
J8 | 1 | KEYBOARD | 2x08
J9 | 1 | RGB | 1x06
Q1 | 1 | BC846B | SOT-23-3
R10 R13 R22 R7 | 4 | 510 | 0805
R16 R17 R18 R19 | 4 | 75 | 0805
R20 | 1 | 2k2 | 0805
R1 R2 R3 R4 R5 R21 R23 R24 R26 R27 R28 R29 R30 R33 R37 R38 | 16 | 10k | 0805
R25 | 1 | 33k | 0805
R31 | 1 | 4,7M | 0805
R32 | 1 | 47k | 0805
R34 R35 R36 | 3 | 470 | 0805
R11 R14 R8 | 3 | 1k | 0805
R12 R15 R9 | 3 | 2k | 0805
RN1 RN2 RN3 RN4 RN5 | 5 | 10k | 4x0612
SW1 — SW42 | 42 | SPST PTS810 | SPST PTS810
U1 | 1 | Z84C0010AEG | QFP-44
U13 | 1 | LM1117-3.3 | SOT-223
U2 | 1 | 27C512 | PLCC-32 SMD
U3 | 1 | BS62LV1600 | TSOP-II-44
U4 | 1 | ATmega8A-AU | TQFP-32
U5 | 1 | ESP8266 | ESP-12F
U6 | 1 | EPM3256ATC144 | LQFP-144
U7 | 1 | MicroSD | GCT-MEM2055-00-190-01-A
U9 | 1 | AD724 | SOIC-16W
Y1 | 1 | 28MHz | 0705
Y3 | 1 | 4.43MHz | HC49US
Y4 | 1 | 20MHz or 24MHz | HC49US

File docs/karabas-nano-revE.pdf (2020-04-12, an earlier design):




karabas-nano-revE

Страница 1

Reference | Q-ty | Value | Footprint
C10 C11 C12 C13 C28 C29 | 6 | 10uF | 0805
C14 | 1 | 10uF | Tantalum B
C15 C33 | 2 | 10nF | 0805
C17 | 1 | 3n3 | 0805
C30 C31 | 2 | 1nF | 0805
C16 C18 C19 C20 C21 C22 C23 C24 C25 C26 C27 C32 C5 C6 C7 | 15 | 100nF | 0805
C8 | 1 | 10p | 0805
C9 | 1 | 220uF | Tantalum D
D1 D2 D3 D4 D5 D6 D7 D8 D9 | 9 | 1N4148W | SOD-123
D10 D11 D12 | 3 | RED/GREEN/YELLOW | 0805
J1 | 1 | DC 5V | 5x2.1mm jack
J10 | 1 | PWR | 1x02
J11 | 1 | AVR ISP | 2x03
J2 | 1 | TAPE IN/OUT | TRRS SMD
J3 | 1 | A/V | TRRS SMD
J4 | 1 | BUS | 1x16
J5 | 1 | KEYBOARD | 2x10
J6 | 1 | BUS | 2x20
J7 | 1 | JTAG | 2x05
J8 | 1 | KEYBOARD | 2x08
J9 | 1 | RGB | 1x06
Q1 | 1 | BC846B | SOT-23-3
R10 R13 R22 R7 | 4 | 510 | 0805
R16 R17 R18 R19 | 4 | 75 | 0805
R20 | 1 | 2k2 | 0805
R1 R2 R3 R4 R5 R21 R23 R24 R26 R27 R28 R29 R30 R33 R37 R38 | 16 | 10k | 0805
R25 | 1 | 33k | 0805
R31 | 1 | 4,7M | 0805
R32 | 1 | 47k | 0805
R34 R35 R36 | 3 | 470 | 0805
R11 R14 R8 | 3 | 1k | 0805
R12 R15 R9 | 3 | 2k | 0805
RN1 RN2 RN3 RN4 RN5 | 5 | 10k | 4x0612
SW1 — SW42 | 42 | 5.2mm switch | SMD 5.2MM
U1 | 1 | Z84C0010AEG | QFP-44
U13 | 1 | LM1117-3.3 | SOT-223
U2 | 1 | 27C512 | PLCC-32 SMD
U3 | 1 | BS62LV1600 | TSOP-II-44
U4 | 1 | ATmega8A-AU | TQFP-32
U5 | 1 | ESP8266 | ESP-12F
U6 | 1 | EPM3256ATC144 | LQFP-144
U7 | 1 | MicroSD | GCT-MEM2055-00-190-01-A
U9 | 1 | AD724 | SOIC-16W
Y1 | 1 | 28MHz | 0705
Y3 | 1 | 4.43MHz | HC49US
Y4 | 1 | 20MHz or 24MHz | HC49US

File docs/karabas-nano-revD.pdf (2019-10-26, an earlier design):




karabas-nano-revC
Reference | Q-ty | Value | Footprint
C10 C11 C12 C13 C28 C29 | 6 | 10uF | 0805
C14 | 1 | 10uF | Tantalum B
C15 C33 | 2 | 10nF | 0805
C17 | 1 | 3n3 | 0805
C30 C31 | 2 | 1nF | 0805
C16 C18 C19 C20 C21 C22 C23 C24 C25 C26 C27 C32 C5 C6 C7 | 15 | 100nF | 0805
C8 | 1 | 10p | 0805
C9 | 1 | 220uF | Tantalum D
D1 D2 D3 D4 D5 D6 D7 D8 D9 | 9 | 1N4148W | SOD-123
D10 D11 D12 | 3 | RED/GREEN/YELLOW0805
J1 | 1 | DC 5V | 5x2.1mm jack
J10 | 1 | PWR | 1x02
J11 | 1 | AVR ISP | 2x03
J2 | 1 | TAPE IN/OUT | TRRS SMD
J3 | 1 | A/V | TRRS SMD
J4 | 1 | BUS | 1x16
J5 | 1 | KEYBOARD | 2x10
J6 | 1 | BUS | 2x20
J7 | 1 | JTAG | 2x05
J8 | 1 | KEYBOARD | 2x08
J9 | 1 | RGB | 1x06
Q1 | 1 | BC846B | SOT-23-3
R10 R13 R22 R7 | 4 | 510 | 0805
R16 R17 R18 R19 | 4 | 75 | 0805
R20 | 1 | 2k2 | 0805
R1 R2 R3 R21 R23 R24 R26 R27 R28 R29 R30 R33 R37 R38 | 14 | 10k | 0805
R25 | 1 | 33k | 0805
R31 | 1 | 4,7M | 0805
R32 | 1 | 47k | 0805
R34 R35 R36 | 3 | 470 | 0805
R11 R14 R8 | 3 | 1k | 0805
R12 R15 R9 | 3 | 2k | 0805
RN1 RN2 RN3 RN4 RN5 | 5 | 10k | 4x0612
SW1 — SW42 | 42 | 5.2mm switch | SMD 5.2MM
U1 | 1 | Z84C0010AEG | QFP-44
U13 | 1 | LM1117-3.3 | SOT-223
U2 | 1 | 27C512 | PLCC-32 SMD
U3 | 1 | BS62LV1600 | TSOP-II-44
U4 | 1 | ATmega8A-AU | TQFP-32
U6 | 1 | EPM3256ATC144 | LQFP-144
U7 | 1 | MicroSD | GCT-MEM2055-00-190-01-A
U9 | 1 | AD724 | SOIC-16W
Y1 | 1 | 28MHz | 0705
Y2 | 1 | XMHz | 0705
Y3 | 1 | 4.43MHz | HC49US
Y4 | 1 | 20MHz | HC49US

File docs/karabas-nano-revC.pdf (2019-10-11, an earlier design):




karabas-nano-revC

Страница 1

Reference | Q-ty | Value | Footprint
C10 C11 C12 C13 C28 C29 | 6 | 10uF | 0805
C14 | 1 | 10uF | Tantalum B
C15 C33 | 2 | 10nF | 0805
C17 | 1 | 3n3 | 0805
C30 C31 | 2 | 1nF | 0805
C16 C18 C19 C20 C21 C22 C23 C24 C25 C26 C27 C32 C5 | 15 | 100nF | 0805
C8 | 1 | 10p | 0805
C9 | 1 | 220uF | Tantalum D
D1 D2 D3 D4 D5 D6 D7 D8 D9 | 9 | 1N4148W | SOD-123
D10 D11 D12 | 3 | RED/GREEN/YELLOW0805
J1 | 1 | DC 5V | 5x2.1mm jack
J10 | 1 | PWR | 1x02
J11 | 1 | AVR ISP | 2x03
J2 | 1 | TAPE IN/OUT | TRRS SMD
J3 | 1 | A/V | TRRS SMD
J4 | 1 | BUS | 1x16
J5 | 1 | KEYBOARD | 2x10
J6 | 1 | BUS | 2x20
J7 | 1 | JTAG | 2x05
J8 | 1 | KEYBOARD | 2x08
J9 | 1 | RGB | 1x06
Q1 | 1 | BC846B | SOT-23-3
R10 R13 R22 R7 | 4 | 510 | 0805
R16 R17 R18 R19 | 4 | 75 | 0805
R20 | 1 | 2k2 | 0805
R1 R2 R3 R21 R23 R24 R26 R27 R28 R29 R30 R33 R37 R38 | 14 | 10k | 0805
R25 | 1 | 33k | 0805
R31 | 1 | 4,7M | 0805
R32 | 1 | 47k | 0805
R34 R35 R36 | 3 | 470 | 0805
R11 R14 R8 | 3 | 1k | 0805
R12 R15 R9 | 3 | 2k | 0805
RN1 RN2 RN3 RN4 RN5 | 5 | 10k | 4x0612
SW1 — SW42 | 42 | 5.2mm switch | SMD 5.2MM
U1 | 1 | Z84C0010AEG | QFP-44
U13 | 1 | LM1117-3.3 | SOT-223
U2 | 1 | 27C512 | PLCC-32 SMD
U3 | 1 | BS62LV1600 | TSOP-II-44
U4 | 1 | ATmega8A-AU | TQFP-32
U6 | 1 | EPM3256ATC144 | LQFP-144
U7 | 1 | MicroSD | GCT-MEM2055-00-190-01-A
U9 | 1 | AD724 | SOIC-16W
Y1 | 1 | 28MHz | 0705
Y2 | 1 | XMHz | 0705
Y3 | 1 | 4.43MHz | HC49US
Y4 | 1 | 20MHz | HC49US

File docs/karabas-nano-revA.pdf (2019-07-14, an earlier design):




karabas-nano

Страница 1

Reference | Q-ty | Value | Package
C1, C3, | 2 | 100p | 0805
C2, C4, | 2 | 22p | 0805
C5, C6, C7, C16, C19, C20, C21, C22, C23, C24, C25, C26, C27, C18, | 14 | 100nF | 0805
C8, | 1 | 10p | 0805
C9, | 1 | 220uF
C10, C11, C12, C13, | 4 | 10uF | 0805
C14, | 1 | 10uF
C15, | 1 | 10nF | 0805
C17, | 1 | 3n3 | 0805
D1, D9, D8, D7, D6, D5, D4, D3, D2, | 9 | 1N4148W
J1, | 1 | DC 5V
J2, | 1 | TAPE IN/OUT
J3, | 1 | RCA
J4, | 1 | BUS
J5, | 1 | KEYBOARD
J6, | 1 | BUS
J7, | 1 | JTAG
J8, | 1 | KEYBOARD
K1-Kspace,SW1,SW2 | 42 | Switch buttons | 5,2mm
Q1, | 1 | BC846B
R1, R2, R4, R5, | 4 | 470 | 0805
R3, R6, | 2 | 4k7 | 0805
R8, R11, R14, | 3 | 1k | 0805
R9, R12, R15, | 3 | 2k | 0805
R10, R13, R7, R22, | 4 | 510 | 0805
R16, R17, R18, R19, | 4 | 75 | 0805
R20, | 1 | 2k2 | 0805
R21, R23, R24, R26, R27, R28, | 6 | 10k | 0805
R25, | 1 | 33k | 0805
RN1, RN2, RN3, RN4, RN5, | 5 | 10k
U1, | 1 | Z80 | QFP-44
U2, | 1 | 27C512 | PLCC32
U3, U4, | 2 | BS62LV4006
U5, | 1 | 74HC04
U6, | 1 | EPM3256ATC144 | TQFP-144
U9, | 1 | AD724
U13, | 1 | LM1117-3.3
Y1, | 1 | 28MHz
Y2, | 1 | 6MHz
Y3, | 1 | 4.43MHz


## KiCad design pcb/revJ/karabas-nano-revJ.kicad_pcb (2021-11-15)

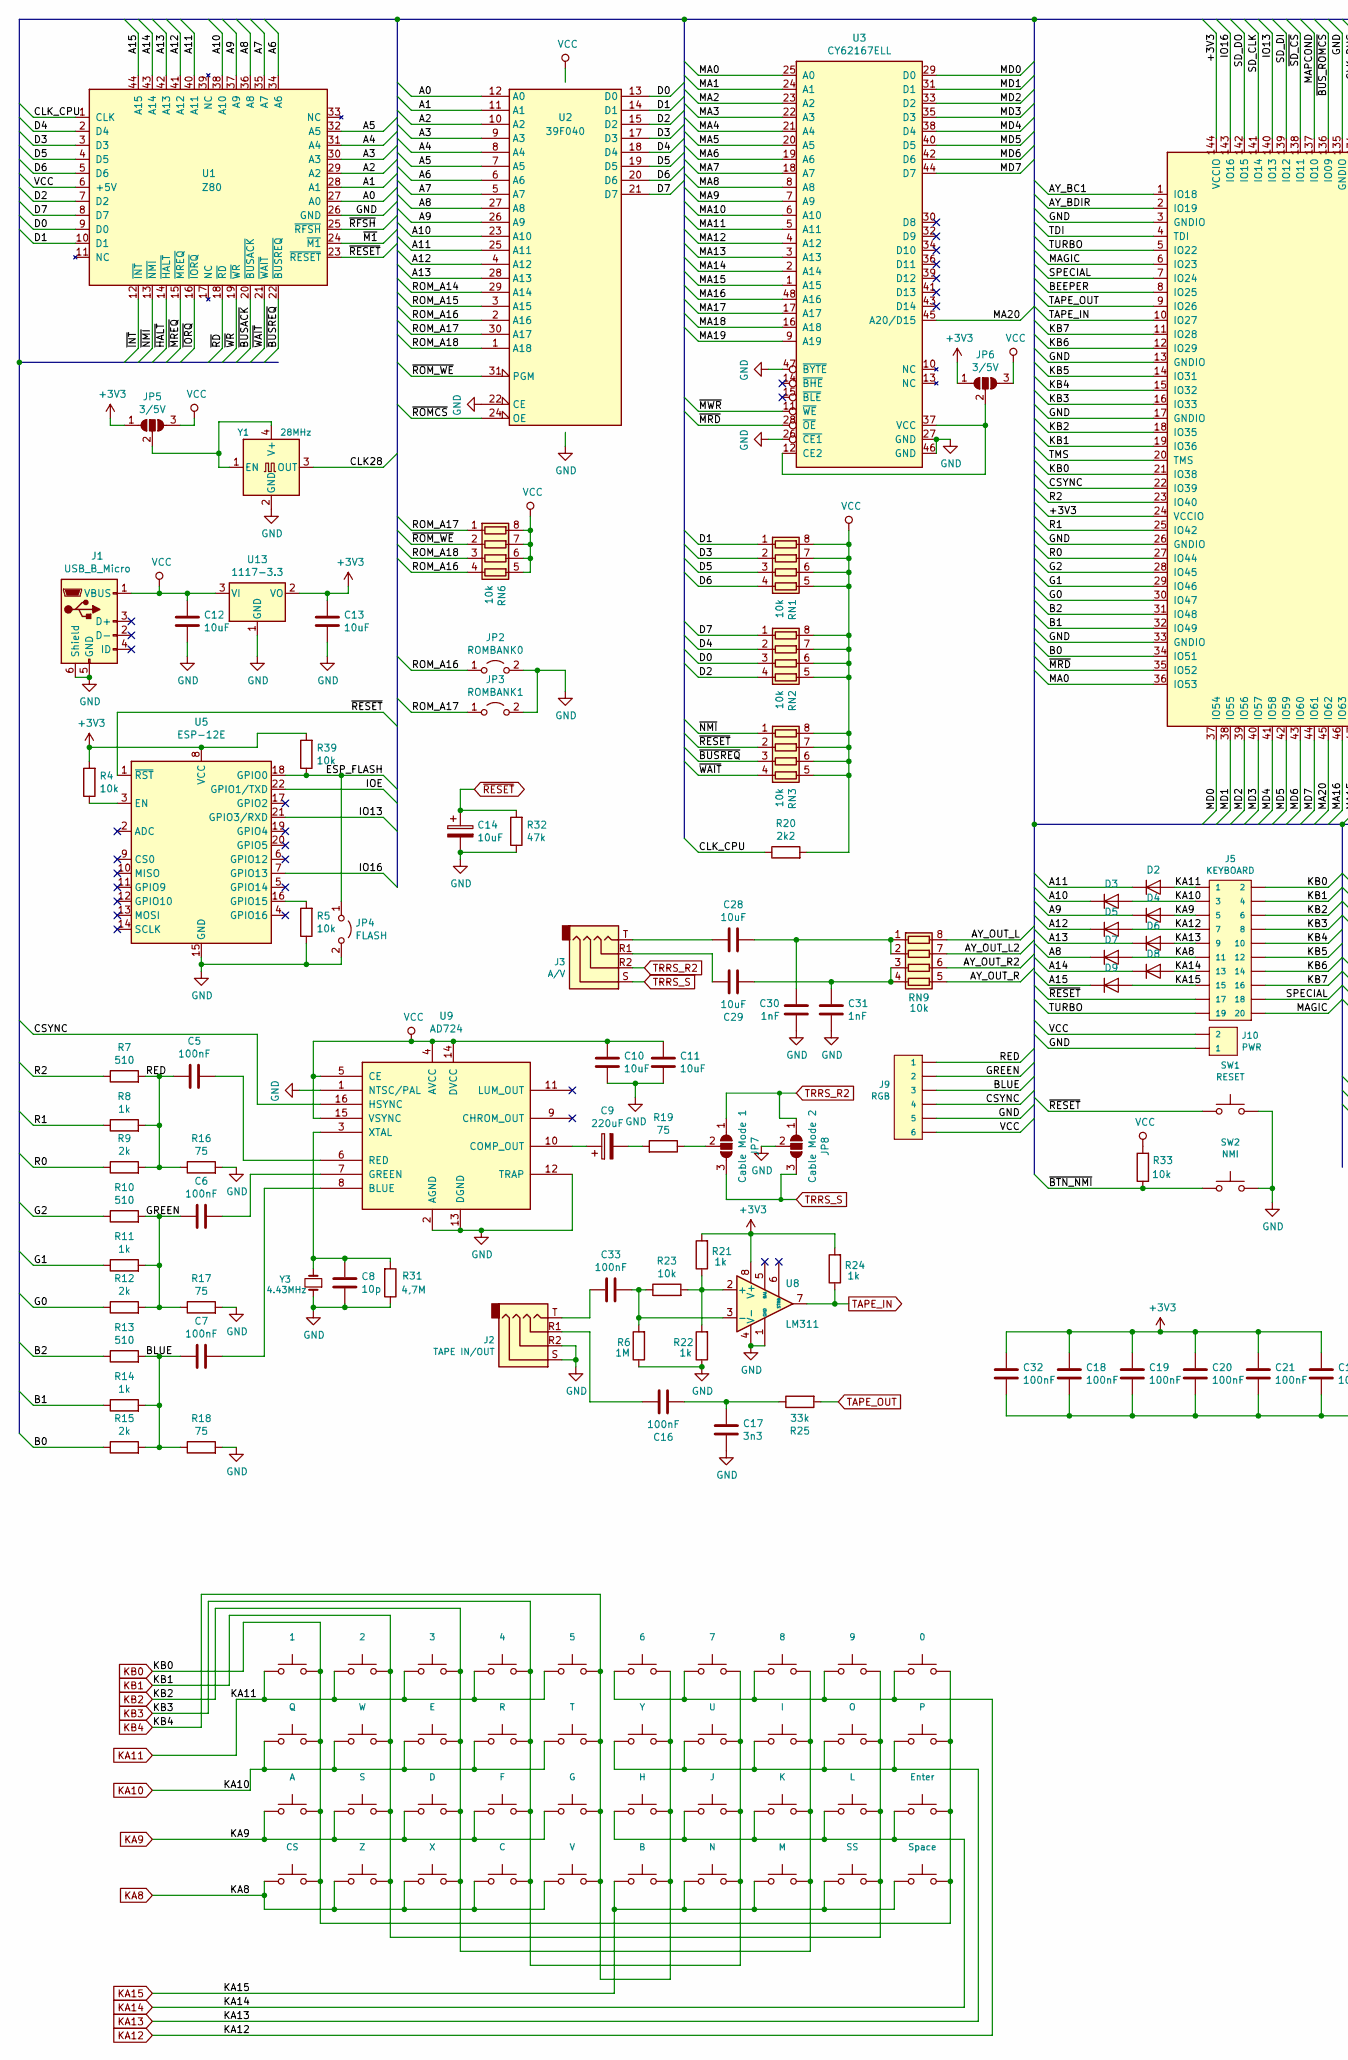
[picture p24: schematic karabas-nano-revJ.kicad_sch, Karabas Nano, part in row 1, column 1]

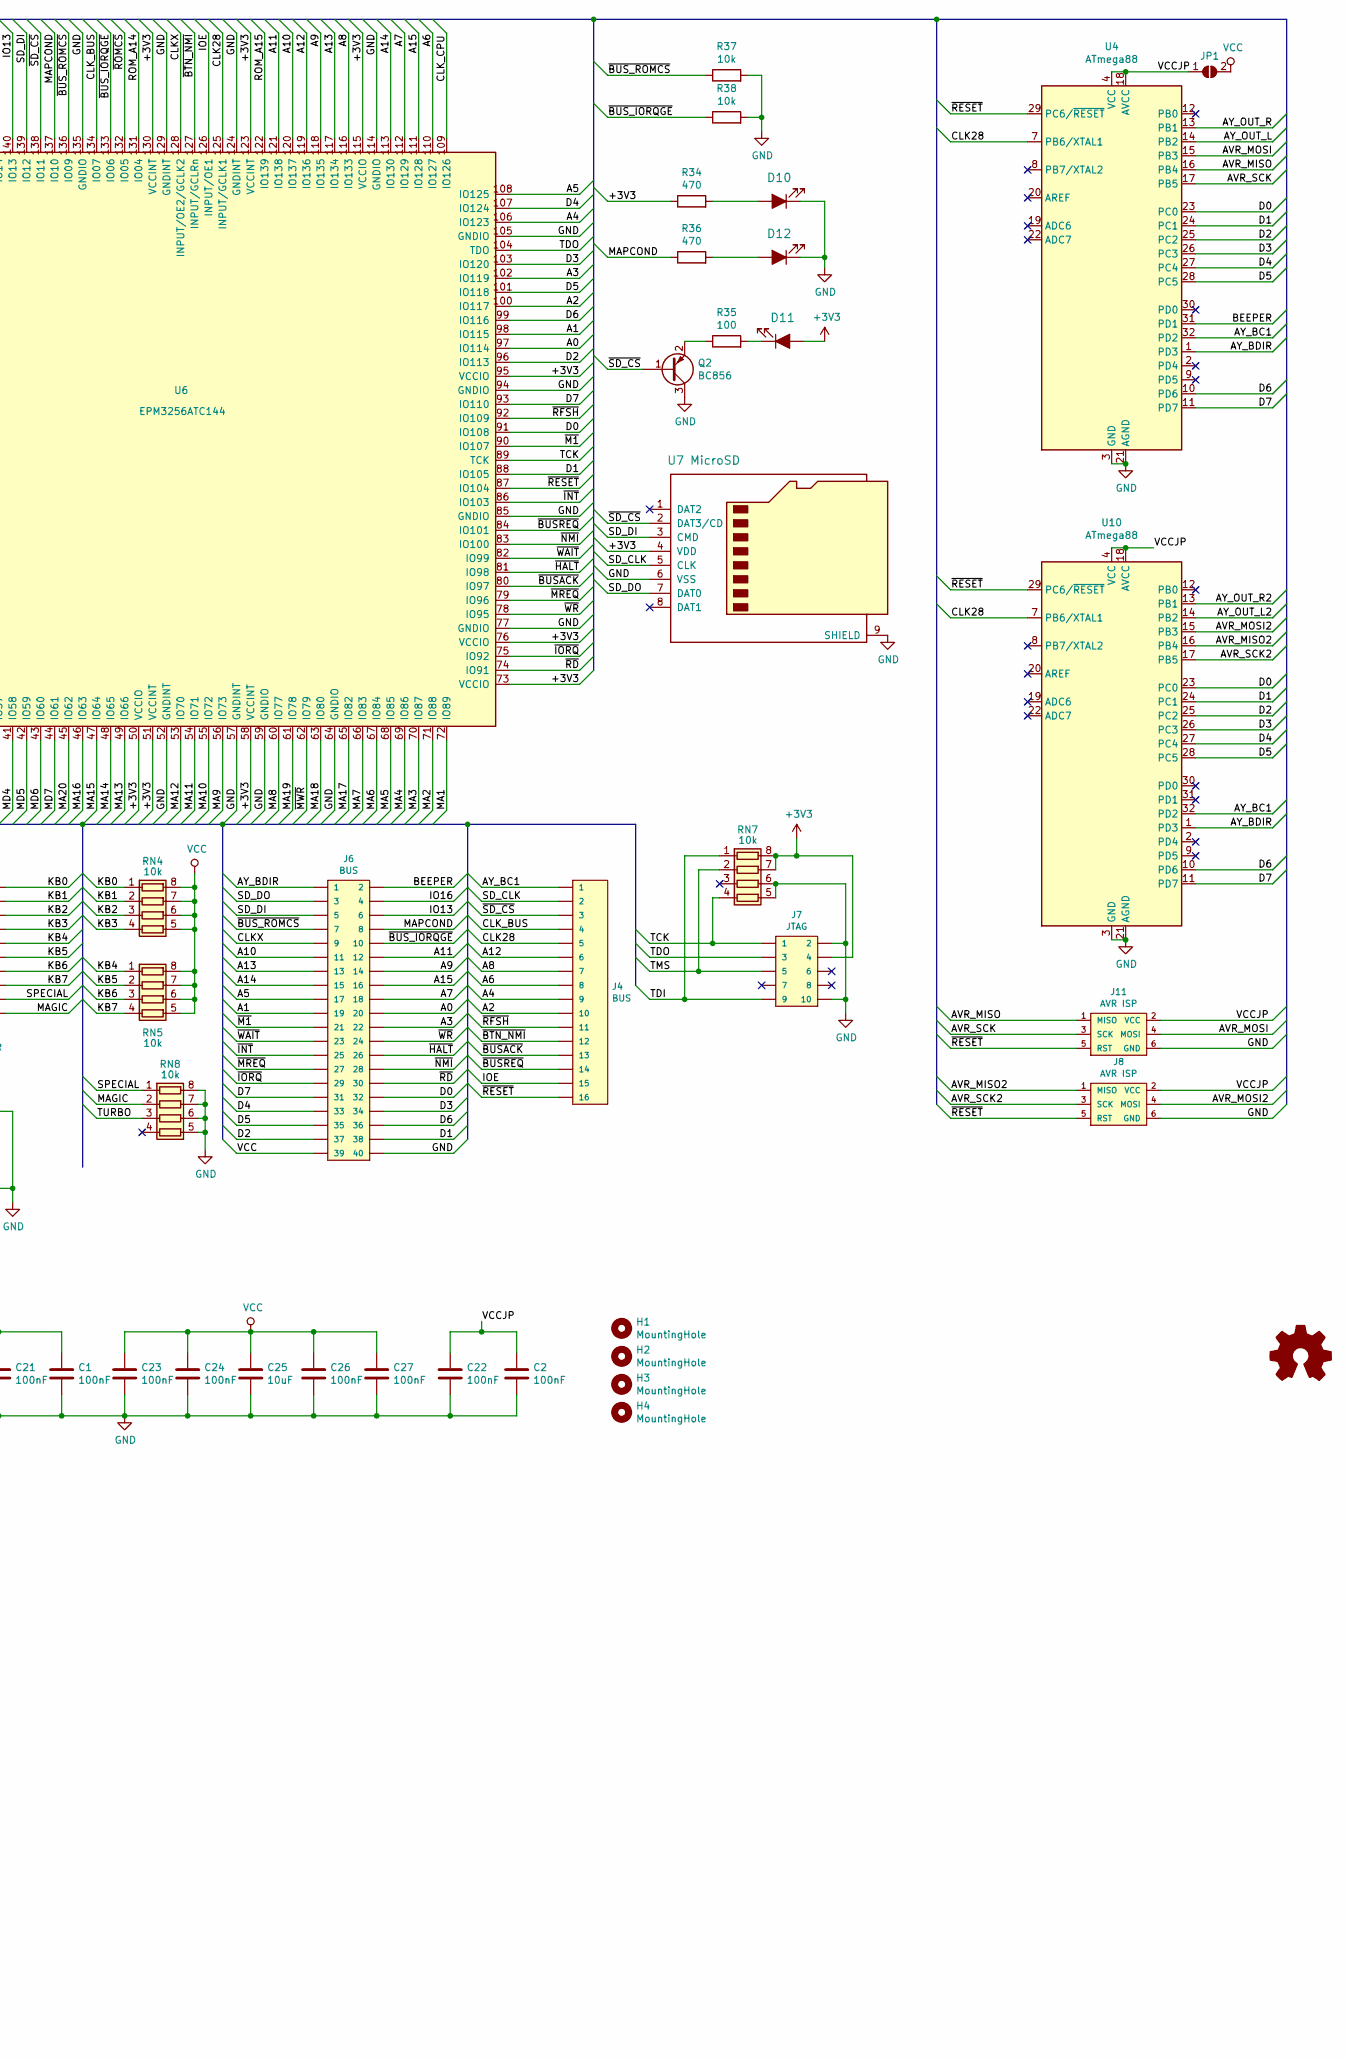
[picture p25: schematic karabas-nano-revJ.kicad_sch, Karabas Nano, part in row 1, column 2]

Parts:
C1, C2, C5, C6, C7, C16, C18, C19, C20, C21, C22, C23, C24, C26, C27, C32, C33: 100nF; C_0805_2012Metric
C8: 10p; C_0805_2012Metric
C9: 220uF; CP_EIA-7343-31_Kemet-D_Pad2.25x2.55mm_HandSolder
C10, C11, C12, C13, C25, C28, C29: 10uF; C_0805_2012Metric
C14: 10uF; CP_EIA-3528-21_Kemet-B_Pad1.50x2.35mm_HandSolder
C17: 3n3; C_0805_2012Metric
C30, C31: 1nF; C_0805_2012Metric
D2, D3, D4, D5, D6, D7, D8, D9: 1N4148W; D_SOD-123
D10: PWR; LED_0805_2012Metric_Pad1.15x1.40mm_HandSolder; MPN LG R971-KN-1; Digi-Key_PN 475-1410-1-ND
D11: SD; LED_0805_2012Metric_Pad1.15x1.40mm_HandSolder; MPN LH R974-LP-1; Digi-Key_PN 475-1415-1-ND
D12: MMC; LED_0805_2012Metric_Pad1.15x1.40mm_HandSolder; MPN LH R974-LP-1; Digi-Key_PN 475-1415-1-ND
H1, H2, H3, H4: MountingHole; MountingHole_2.7mm_M2.5_Pad
J1: USB_B_Micro; USB_Micro-B_Amphenol_10118194_Horizontal
J2: TAPE IN/OUT; AUDIO_JACK_3.5MM_SMD_TRRS_rounded_mixed
J3: A/V; AUDIO_JACK_3.5MM_SMD_TRRS_rounded_mixed
J4: BUS; PinHeader_1x16_P2.54mm_Vertical
J5: KEYBOARD; PinHeader_2x10_P2.54mm_Vertical
J6: BUS; PinHeader_2x20_P2.54mm_Vertical
J7: JTAG; PinHeader_2x05_P2.54mm_Vertical
J8, J11: AVR ISP; PinHeader_2x03_P2.54mm_Vertical
J9: RGB; PinHeader_1x06_P2.54mm_Vertical
J10: PWR; PinHeader_1x02_P2.54mm_Vertical
JP1: SolderJumper_2_Open; SolderJumper-2_P1.3mm_Open_TrianglePad1.0x1.5mm
JP2: ROMBANK0; PinHeader_1x02_P2.54mm_Vertical
JP3: ROMBANK1; PinHeader_1x02_P2.54mm_Vertical
JP4: FLASH; PinHeader_1x02_P2.54mm_Vertical
JP5, JP6: 3/5V; SolderJumper-3_P1.3mm_Open_RoundedPad1.0x1.5mm
JP7: Cable Mode 1; SolderJumper-3_P1.3mm_Open_RoundedPad1.0x1.5mm
JP8: Cable Mode 2; SolderJumper-3_P1.3mm_Open_RoundedPad1.0x1.5mm
Q2: BC856; SOT-23
R4, R5, R23, R33, R37, R38, R39: 10k; R_0805_2012Metric
R6: 1M; R_0805_2012Metric
R7, R10, R13: 510; R_0805_2012Metric
R8, R11, R14, R21, R22, R24: 1k; R_0805_2012Metric
R9, R12, R15: 2k; R_0805_2012Metric
R16, R17, R18, R19: 75; R_0805_2012Metric
R20: 2k2; R_0805_2012Metric
R25: 33k; R_0805_2012Metric
R31: 4,7M; R_0805_2012Metric
R32: 47k; R_0805_2012Metric
R34, R36: 470; R_0805_2012Metric
R35: 100; R_0805_2012Metric
RN1, RN2, RN3, RN4, RN5, RN6, RN7, RN8, RN9: 10k; R_Array_Convex_4x0612
SW1: RESET; small-btn
SW2: NMI; small-btn
SW3: 1; small-btn
SW4: 2; small-btn
SW5: 3; small-btn
SW6: 4; small-btn
SW7: 5; small-btn
SW8: 6; small-btn
SW9: 7; small-btn
SW10: 8; small-btn
SW11: 9; small-btn
SW12: 0; small-btn
SW13: Q; small-btn
SW14: A; small-btn
SW15: CS; small-btn
SW16: W; small-btn
SW17: S; small-btn
SW18: Z; small-btn
SW19: E; small-btn
SW20: D; small-btn
SW21: X; small-btn
SW22: R; small-btn
SW23: F; small-btn
SW24: C; small-btn
SW25: T; small-btn
SW26: G; small-btn
SW27: V; small-btn
SW28: Y; small-btn
SW29: H; small-btn
SW30: B; small-btn
SW31: U; small-btn
SW32: J; small-btn
SW33: N; small-btn
SW34: I; small-btn
SW35: K; small-btn
SW36: M; small-btn
SW37: O; small-btn
SW38: L; small-btn
SW39: SS; small-btn
SW40: P; small-btn
SW41: Enter; small-btn
SW42: Space; small-btn
U1: Z80; TQFP-44_14x14mm_P0.8mm
U2: 39F040; PLCC-32_11.4x14.0mm_P1.27mm-bigpads
U3: CY62167ELL; TSOP-I-48_18.4x12mm_P0.5mm
U4, U10: ATmega88; TQFP-32_7x7mm_P0.8mm
U5: ESP-12E
U6: EPM3256ATC144; LQFP-144_20x20mm_P0.5mm
U7: MicroSD; Conn_uSDcard
U8: LM311; SO-8_3.9x4.9mm_P1.27mm
U9: AD724; SOIC-16W_7.5x10.3mm_P1.27mm
U13: 1117-3.3; SOT-223-3_TabPin2
Y1: 28MHz; Oscillator_SMD_EuroQuartz_XO91-4Pin_7.0x5.0mm
Y3: 4.43MHz; Crystal_HC49-U_Vertical

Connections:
+3V3: C1.2, C13.2, C18.2, C19.2, C20.2, C21.2, C32.2, D11.2 (A), J7.4, JP5.1 (A), JP6.1 (A), R4.2, R21.2, R24.2, R34.1, R39.2, RN7.7 (R2.2), RN7.8 (R1.2), U5.8 (VCC), U6.24 (VCCIO), U6.50 (VCCIO), U6.51 (VCCINT), U6.58 (VCCINT), U6.73 (VCCIO), U6.76 (VCCIO), U6.95 (VCCIO), U6.115 (VCCIO), U6.123 (VCCINT), U6.130 (VCCINT), U6.144 (VCCIO), U7.4 (VDD), U8.8 (V+), U13.2 (VO)
/A0: J6.20, U1.27 (A0), U2.12 (A0), U6.97 (IO114)
/A1: J6.19, U1.28 (A1), U2.11 (A1), U6.98 (IO115)
/A2: J4.10, U1.29 (A2), U2.10 (A2), U6.100 (IO117)
/A3: J6.22, U1.30 (A3), U2.9 (A3), U6.102 (IO119)
/A4: J4.9, U1.31 (A4), U2.8 (A4), U6.106 (IO123)
/A5: J6.17, U1.32 (A5), U2.7 (A5), U6.108 (IO125)
/A6: J4.8, U1.34 (A6), U2.6 (A6), U6.110 (IO127)
/A7: J6.18, U1.35 (A7), U2.5 (A7), U6.112 (IO129)
/A8: D7.1 (K), J4.7, U1.36 (A8), U2.27 (A8), U6.116 (IO133)
/A9: D4.1 (K), J6.14, U1.37 (A9), U2.26 (A9), U6.118 (IO135)
/A10: D3.1 (K), J6.11, U1.38 (A10), U2.23 (A10), U6.120 (IO137)
/A11: D2.1 (K), J6.12, U1.40 (A11), U2.25 (A11), U6.121 (IO138)
/A12: D5.1 (K), J4.6, U1.41 (A12), U2.4 (A12), U6.119 (IO136)
/A13: D6.1 (K), J6.13, U1.42 (A13), U2.28 (A13), U6.117 (IO134)
/A14: D8.1 (K), J6.15, U1.43 (A14), U6.113 (IO130)
/A15: D9.1 (K), J6.16, U1.44 (A15), U6.111 (IO128)
/AVR_MISO: J11.1 (MISO), U4.16 (PB4)
/AVR_MISO2: J8.1 (MISO), U10.16 (PB4)
/AVR_MOSI: J11.4 (MOSI), U4.15 (PB3)
/AVR_MOSI2: J8.4 (MOSI), U10.15 (PB3)
/AVR_SCK: J11.3 (SCK), U4.17 (PB5)
/AVR_SCK2: J8.3 (SCK), U10.17 (PB5)
/AY_BC1: J4.1, U4.32 (PD2), U6.1 (IO18), U10.32 (PD2)
/AY_BDIR: J6.1, U4.1 (PD3), U6.2 (IO19), U10.1 (PD3)
/AY_OUT_L: RN9.8 (R1.2), U4.14 (PB2)
/AY_OUT_L2: RN9.7 (R2.2), U10.14 (PB2)
/AY_OUT_R: RN9.5 (R4.2), U4.13 (PB1)
/AY_OUT_R2: RN9.6 (R3.2), U10.13 (PB1)
/B0: R15.1, U6.34 (IO51)
/B1: R14.1, U6.32 (IO49)
/B2: R13.1, U6.31 (IO48)
/BEEPER: J6.2, U4.31 (PD1), U6.8 (IO25)
/BLUE: C7.2, J9.3, R13.2, R14.2, R15.2, R18.1
/CLK28: J4.5, U4.7 (PB6/XTAL1), U6.125 (INPUT/GCLK1), U10.7 (PB6/XTAL1), Y1.3 (OUT)
/CLKX: J6.9, U6.128 (INPUT/OE2/GCLK2)
/CLK_BUS: J4.4, U6.134 (IO07)
/CLK_CPU: R20.1, U1.1 (CLK), U6.109 (IO126)
/CSYNC: J9.4, U6.22 (IO39), U9.16 (HSYNC)
/D0: J6.32, RN2.3 (R3.1), U1.9 (D0), U2.13 (D0), U4.23 (PC0), U6.91 (IO108), U10.23 (PC0)
/D1: J6.38, RN1.1 (R1.1), U1.10 (D1), U2.14 (D1), U4.24 (PC1), U6.88 (IO105), U10.24 (PC1)
/D2: J6.37, RN2.4 (R4.1), U1.7 (D2), U2.15 (D2), U4.25 (PC2), U6.96 (IO113), U10.25 (PC2)
/D3: J6.34, RN1.2 (R2.1), U1.3 (D3), U2.17 (D3), U4.26 (PC3), U6.103 (IO120), U10.26 (PC3)
/D4: J6.33, RN2.2 (R2.1), U1.2 (D4), U2.18 (D4), U4.27 (PC4), U6.107 (IO124), U10.27 (PC4)
/D5: J6.35, RN1.3 (R3.1), U1.4 (D5), U2.19 (D5), U4.28 (PC5), U6.101 (IO118), U10.28 (PC5)
/D6: J6.36, RN1.4 (R4.1), U1.5 (D6), U2.20 (D6), U4.10 (PD6), U6.99 (IO116), U10.10 (PD6)
/D7: J6.31, RN2.1 (R1.1), U1.8 (D7), U2.21 (D7), U4.11 (PD7), U6.93 (IO110), U10.11 (PD7)
/ESP_FLASH: JP4.1 (A), R39.1, U5.18 (GPIO0)
/G0: R12.1, U6.30 (IO47)
/G1: R11.1, U6.29 (IO46)
/G2: R10.1, U6.28 (IO45)
/GREEN: C6.2, J9.2, R10.2, R11.2, R12.2, R17.1
/IO13: J6.6, U5.21 (GPIO3/RXD), U6.140 (IO13)
/IO16: J6.4, U5.7 (GPIO13), U6.143 (IO16)
/IOE: J4.15, U5.22 (GPIO1/TXD), U6.126 (INPUT/OE1)
/KB5: J5.12, RN5.2 (R2.1), U6.14 (IO31)
/KB6: J5.14, RN5.3 (R3.1), U6.12 (IO29)
/KB7: J5.16, RN5.4 (R4.1), U6.11 (IO28)
/MA0: U3.25 (A0), U6.36 (IO53)
/MA1: U3.24 (A1), U6.72 (IO89)
/MA2: U3.23 (A2), U6.71 (IO88)
/MA3: U3.22 (A3), U6.70 (IO87)
/MA4: U3.21 (A4), U6.69 (IO86)
/MA5: U3.20 (A5), U6.68 (IO85)
/MA6: U3.19 (A6), U6.67 (IO84)
/MA7: U3.18 (A7), U6.66 (IO83)
/MA8: U3.8 (A8), U6.60 (IO77)
/MA9: U3.7 (A9), U6.56 (IO73)
/MA10: U3.6 (A10), U6.55 (IO72)
/MA11: U3.5 (A11), U6.54 (IO71)
/MA12: U3.4 (A12), U6.53 (IO70)
/MA13: U3.3 (A13), U6.49 (IO66)
/MA14: U3.2 (A14), U6.48 (IO65)
/MA15: U3.1 (A15), U6.47 (IO64)
/MA16: U3.48 (A16), U6.46 (IO63)
/MA17: U3.17 (A17), U6.65 (IO82)
/MA18: U3.16 (A18), U6.63 (IO80)
/MA19: U3.9 (A19), U6.61 (IO78)
/MA20: U3.45 (A20/D15), U6.45 (IO62)
/MAGIC: J5.20, RN8.2 (R2.1), U6.6 (IO23)
/MAPCOND: J6.8, R36.1, U6.137 (IO10)
/MD0: U3.29 (D0), U6.37 (IO54)
/MD1: U3.31 (D1), U6.38 (IO55)
/MD2: U3.33 (D2), U6.39 (IO56)
/MD3: U3.35 (D3), U6.40 (IO57)
/MD4: U3.38 (D4), U6.41 (IO58)
/MD5: U3.40 (D5), U6.42 (IO59)
/MD6: U3.42 (D6), U6.43 (IO60)
/MD7: U3.44 (D7), U6.44 (IO61)
/R0: R9.1, U6.27 (IO44)
/R1: R8.1, U6.25 (IO42)
/R2: R7.1, U6.23 (IO40)
/RED: C5.2, J9.1, R7.2, R8.2, R9.2, R16.1
/ROM_A14: U2.29 (A14), U6.131 (IO04)
/ROM_A15: U2.3 (A15), U6.122 (IO139)
/ROM_A16: JP2.1 (A), RN6.4 (R4.1), U2.2 (A16)
/ROM_A17: JP3.1 (A), RN6.1 (R1.1), U2.30 (A17)
/ROM_A18: RN6.3 (R3.1), U2.1 (A18)
/SD_CLK: J4.2, U6.141 (IO14), U7.5 (CLK)
/SD_DI: J6.5, U6.139 (IO12), U7.3 (CMD)
/SD_DO: J6.3, U6.142 (IO15), U7.7 (DAT0)
/SPECIAL: J5.18, RN8.1 (R1.1), U6.7 (IO24)
/TCK: J7.1, RN7.4 (R4.1), U6.89 (TCK)
/TDI: J7.9, RN7.1 (R1.1), U6.4 (TDI)
/TDO: J7.3, U6.104 (TDO)
/TMS: J7.5, RN7.2 (R2.1), U6.20 (TMS)
/TURBO: J5.19, RN8.3 (R3.1), U6.5 (IO22)
/VCCJP: C2.2, C22.2, J8.2 (VCC), J11.2 (VCC), JP1.1 (A), U4.4 (VCC), U4.6 (VCC), U4.18 (AVCC), U10.4 (VCC), U10.6 (VCC), U10.18 (AVCC)
/~BTN_NMI: J4.12, R33.1, SW2.1, U6.127 (INPUT/GCLRn)
/~BUSACK: J4.13, U1.20 (~BUSACK), U6.80 (IO97)
/~BUSREQ: J4.14, RN3.3 (R3.1), U1.22 (~BUSREQ), U6.84 (IO101)
/~BUS_IORQGE: J6.10, R38.1, U6.133 (IO06)
/~BUS_ROMCS: J6.7, R37.1, U6.136 (IO09)
/~HALT: J6.26, U1.14 (~HALT), U6.81 (IO98)
/~INT: J6.25, U1.12 (~INT), U6.86 (IO103)
/~IORQ: J6.29, U1.16 (~IORQ), U6.75 (IO92)
/~M1: J6.21, U1.24 (~M1), U6.90 (IO107)
/~MRD: U3.28 (~OE), U6.35 (IO52)
/~MREQ: J6.27, U1.15 (~MREQ), U6.79 (IO96)
/~MWR: U3.11 (~WE), U6.62 (IO79)
/~NMI: J6.28, RN3.1 (R1.1), U1.13 (~NMI), U6.83 (IO100)
/~RD: J6.30, U1.18 (~RD), U6.74 (IO91)
/~RFSH: J4.11, U1.25 (~RFSH), U6.92 (IO109)
/~ROMCS: U2.24 (OE), U6.132 (IO05)
/~ROM_WE: RN6.2 (R2.1), U2.31 (PGM)
/~SD_CS: J4.3, Q2.1 (B), U6.138 (IO11), U7.2 (DAT3/CD)
/~WAIT: J6.23, RN3.4 (R4.1), U1.21 (~WAIT), U6.82 (IO99)
/~WR: J6.24, U1.19 (~WR), U6.78 (IO95)
GND: C1.1, C2.1, C8.1, C10.1, C11.1, C12.1, C13.1, C14.2, C17.1, C18.1, C19.1, C20.1, C21.1, C22.1, C23.1, C24.1, C25.1, C26.1, C27.1, C30.1, C31.1, C32.1, D10.1 (K), D12.1 (K), J1.5 (GND), J1.6 (Shield), J2.R2, J2.S, J6.40, J7.2, J7.10, J8.6 (GND), J9.5, J10.1, J11.6 (GND), JP2.2 (B), JP3.2 (B), JP4.2 (B), JP8.2 (C), Q2.3 (C), R5.1, R6.1, R16.2, R17.2, R18.2, R22.1, R31.1, R32.1, R37.2, R38.2, RN7.5 (R4.2), RN7.6 (R3.2), RN8.5 (R4.2), RN8.6 (R3.2), RN8.7 (R2.2), RN8.8 (R1.2), SW1.2, SW2.2, U1.26 (GND), U2.16 (GND), U2.22 (CE), U3.26 (~CE1), U3.27 (GND), U3.46 (GND), U3.47 (~BYTE), U4.3 (GND), U4.5 (GND), U4.21 (AGND), U5.15 (GND), U6.3 (GNDIO), U6.13 (GNDIO), U6.17 (GNDIO), U6.26 (GNDIO), U6.33 (GNDIO), U6.52 (GNDINT), U6.57 (GNDINT), U6.59 (GNDIO), U6.64 (GNDIO), U6.77 (GNDIO), U6.85 (GNDIO), U6.94 (GNDIO), U6.105 (GNDIO), U6.114 (GNDIO), U6.124 (GNDINT), U6.129 (GNDINT), U6.135 (GNDIO), U7.6 (VSS), U7.9 (SHIELD), U8.1 (GND), U8.4 (V-), U9.1 (NTSC/PAL), U9.2 (AGND), U9.12 (TRAP), U9.13 (DGND), U10.3 (GND), U10.5 (GND), U10.21 (AGND), U13.1 (GND), Y1.2 (GND), Y3.1
KA8: D7.2 (A), J5.11, SW15.1, SW18.1, SW21.1, SW24.1, SW27.1
KA9: D4.2 (A), J5.5, SW14.1, SW17.1, SW20.1, SW23.1, SW26.1
KA10: D3.2 (A), J5.3, SW13.1, SW16.1, SW19.1, SW22.1, SW25.1
KA11: D2.2 (A), J5.1, SW3.1, SW4.1, SW5.1, SW6.1, SW7.1
KA12: D5.2 (A), J5.7, SW8.1, SW9.1, SW10.1, SW11.1, SW12.1
KA13: D6.2 (A), J5.9, SW28.1, SW31.1, SW34.1, SW37.1, SW40.1
KA14: D8.2 (A), J5.13, SW29.1, SW32.1, SW35.1, SW38.1, SW41.1
KA15: D9.2 (A), J5.15, SW30.1, SW33.1, SW36.1, SW39.1, SW42.1
KB0: J5.2, RN4.1 (R1.1), SW3.2, SW12.2, SW13.2, SW14.2, SW15.2, SW40.2, SW41.2, SW42.2, U6.21 (IO38)
KB1: J5.4, RN4.2 (R2.1), SW4.2, SW11.2, SW16.2, SW17.2, SW18.2, SW37.2, SW38.2, SW39.2, U6.19 (IO36)
KB2: J5.6, RN4.3 (R3.1), SW5.2, SW10.2, SW19.2, SW20.2, SW21.2, SW34.2, SW35.2, SW36.2, U6.18 (IO35)
KB3: J5.8, RN4.4 (R4.1), SW6.2, SW9.2, SW22.2, SW23.2, SW24.2, SW31.2, SW32.2, SW33.2, U6.16 (IO33)
KB4: J5.10, RN5.1 (R1.1), SW7.2, SW8.2, SW25.2, SW26.2, SW27.2, SW28.2, SW29.2, SW30.2, U6.15 (IO32)
unnamed: C5.1, U9.6 (RED)
unnamed: C6.1, U9.7 (GREEN)
unnamed: C7.1, U9.8 (BLUE)
unnamed: C8.2, R31.2, U9.3 (XTAL), Y3.2
unnamed: C9.1, U9.10 (COMP_OUT)
unnamed: C9.2, R19.2
unnamed: C16.1, C17.2, R25.1
unnamed: C16.2, J2.R1
unnamed: C28.1, C30.2, RN9.1 (R1.1), RN9.2 (R2.1)
unnamed: C28.2, J3.T
unnamed: C29.1, C31.2, RN9.3 (R3.1), RN9.4 (R4.1)
unnamed: C29.2, J3.R1
unnamed: C33.1, R6.2, R23.1, U8.3 (-)
unnamed: C33.2, J2.T
unnamed: D10.2 (A), R34.2
unnamed: D11.1 (K), R35.2
unnamed: D12.2 (A), R36.2
unnamed: JP5.2 (C), Y1.1 (EN), Y1.4 (V+)
unnamed: JP6.2 (C), U3.12 (CE2), U3.37 (VCC)
unnamed: Q2.2 (E), R35.1
unnamed: R4.1, U5.3 (EN)
unnamed: R5.2, U5.16 (GPIO15)
unnamed: JP7.2 (C), R19.1
unnamed: R21.1, R22.2, R23.2, U8.2 (+)
TAPE_IN: R24.1, U6.10 (IO27), U8.7
TAPE_OUT: R25.2, U6.9 (IO26)
TRRS_R2: J3.R2, JP7.1 (A), JP8.1 (A)
TRRS_S: J3.S, JP7.3 (B), JP8.3 (B)
VCC: C10.2, C11.2, C12.2, C23.2, C24.2, C25.2, C26.2, C27.2, J1.1 (VBUS), J6.39, J9.6, J10.2, JP1.2 (B), JP5.3 (B), JP6.3 (B), R20.2, R33.2, RN1.5 (R4.2), RN1.6 (R3.2), RN1.7 (R2.2), RN1.8 (R1.2), RN2.5 (R4.2), RN2.6 (R3.2), RN2.7 (R2.2), RN2.8 (R1.2), RN3.5 (R4.2), RN3.6 (R3.2), RN3.7 (R2.2), RN3.8 (R1.2), RN4.5 (R4.2), RN4.6 (R3.2), RN4.7 (R2.2), RN4.8 (R1.2), RN5.5 (R4.2), RN5.6 (R3.2), RN5.7 (R2.2), RN5.8 (R1.2), RN6.5 (R4.2), RN6.6 (R3.2), RN6.7 (R2.2), RN6.8 (R1.2), U1.6 (+5V), U2.32 (VCC), U9.4 (AVCC), U9.5 (CE), U9.14 (DVCC), U9.15 (VSYNC), U13.3 (VI)
~RESET: C14.1, J4.16, J5.17, J8.5 (RST), J11.5 (RST), R32.2, RN3.2 (R2.1), SW1.1, U1.23 (~RESET), U4.29 (PC6/~RESET), U5.1 (~RST), U6.87 (IO104), U10.29 (PC6/~RESET)

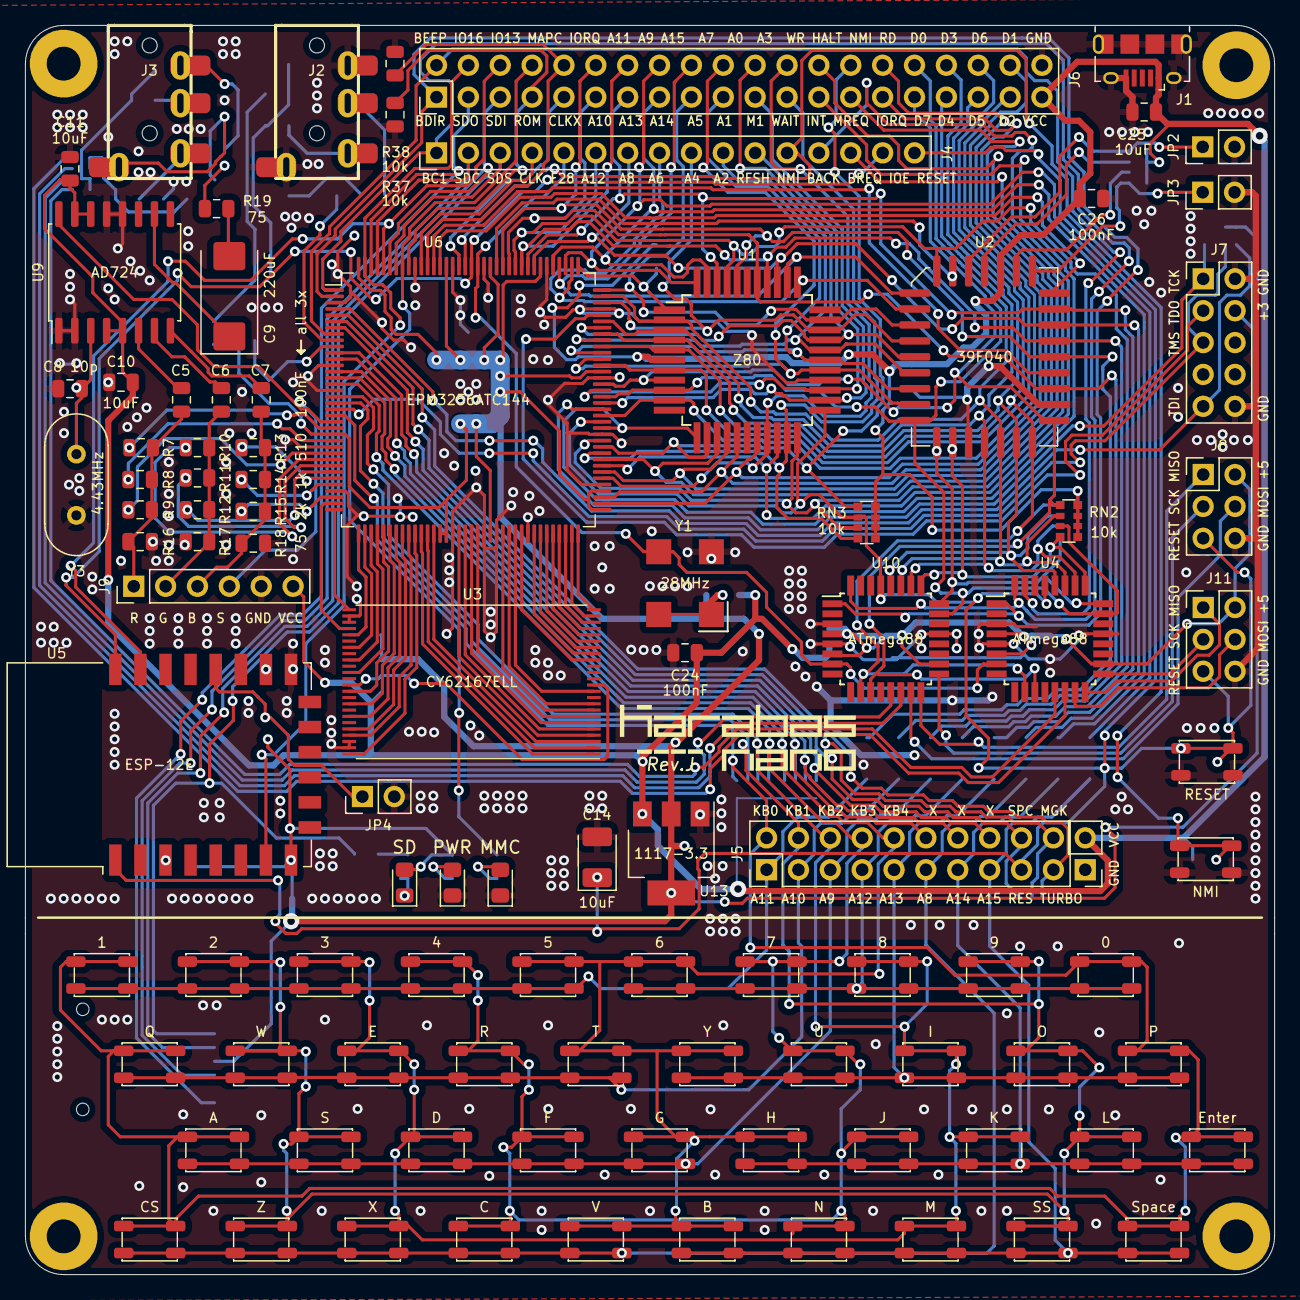
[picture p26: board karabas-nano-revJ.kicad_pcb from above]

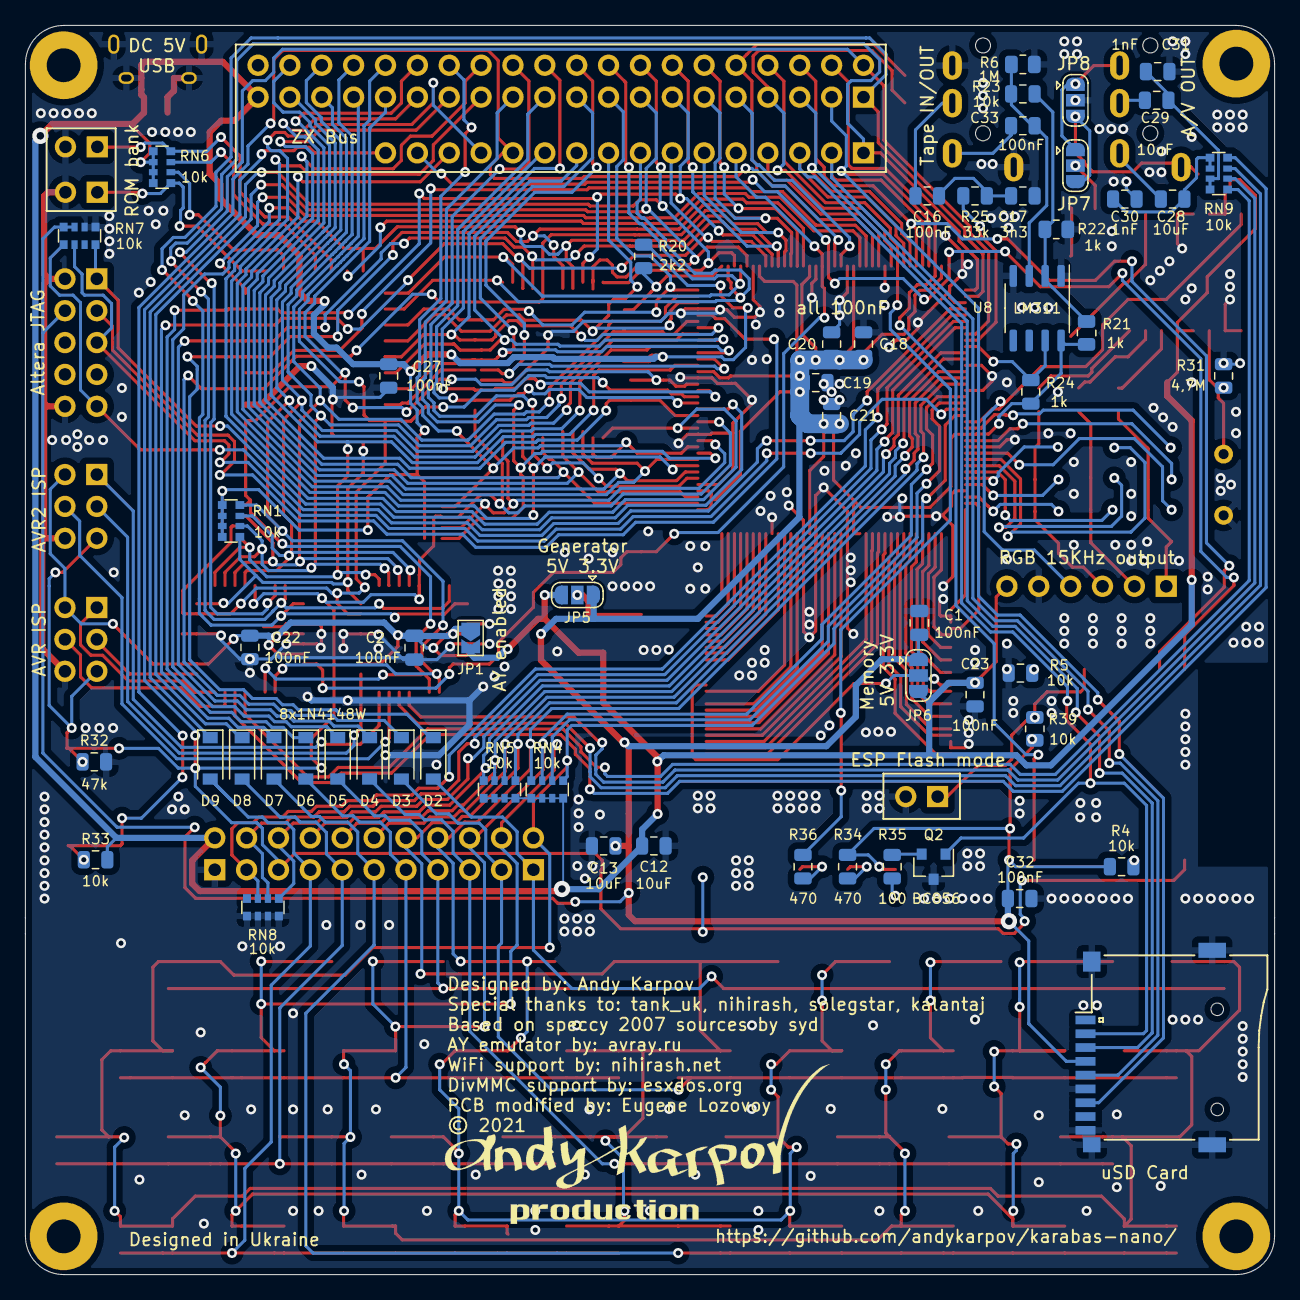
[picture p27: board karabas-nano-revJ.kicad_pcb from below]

Board: 2 copper layers, 99.6 x 99.6 mm, 160 parts (58 on the bottom side), 172 nets.

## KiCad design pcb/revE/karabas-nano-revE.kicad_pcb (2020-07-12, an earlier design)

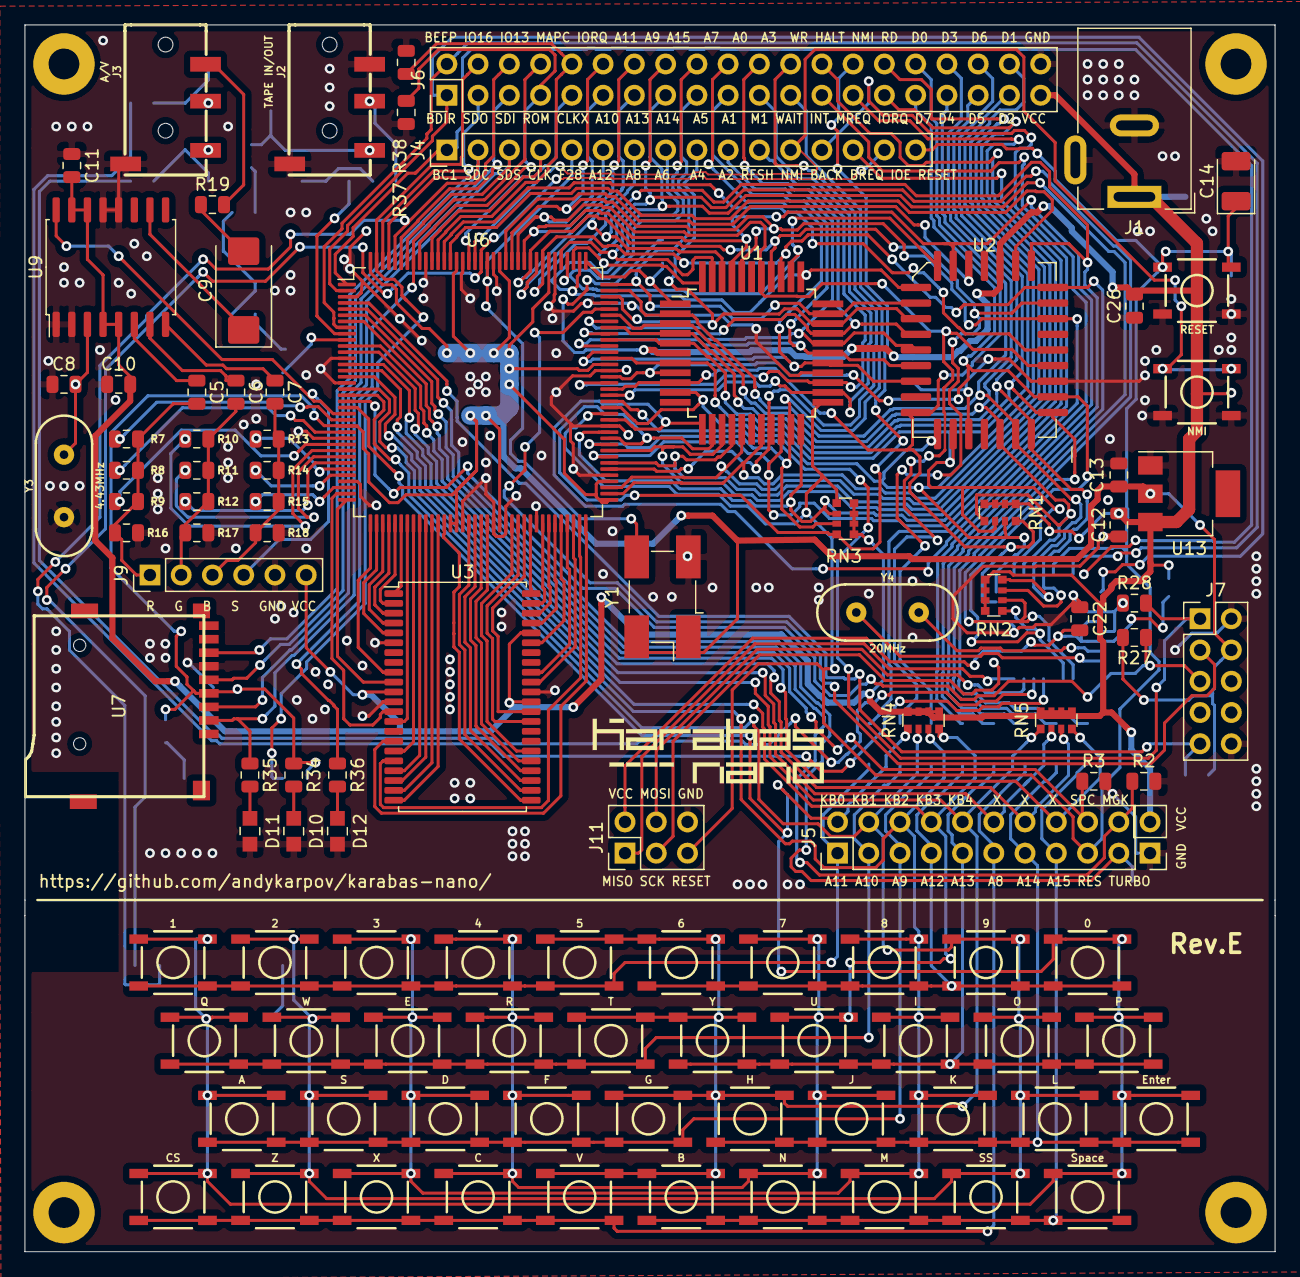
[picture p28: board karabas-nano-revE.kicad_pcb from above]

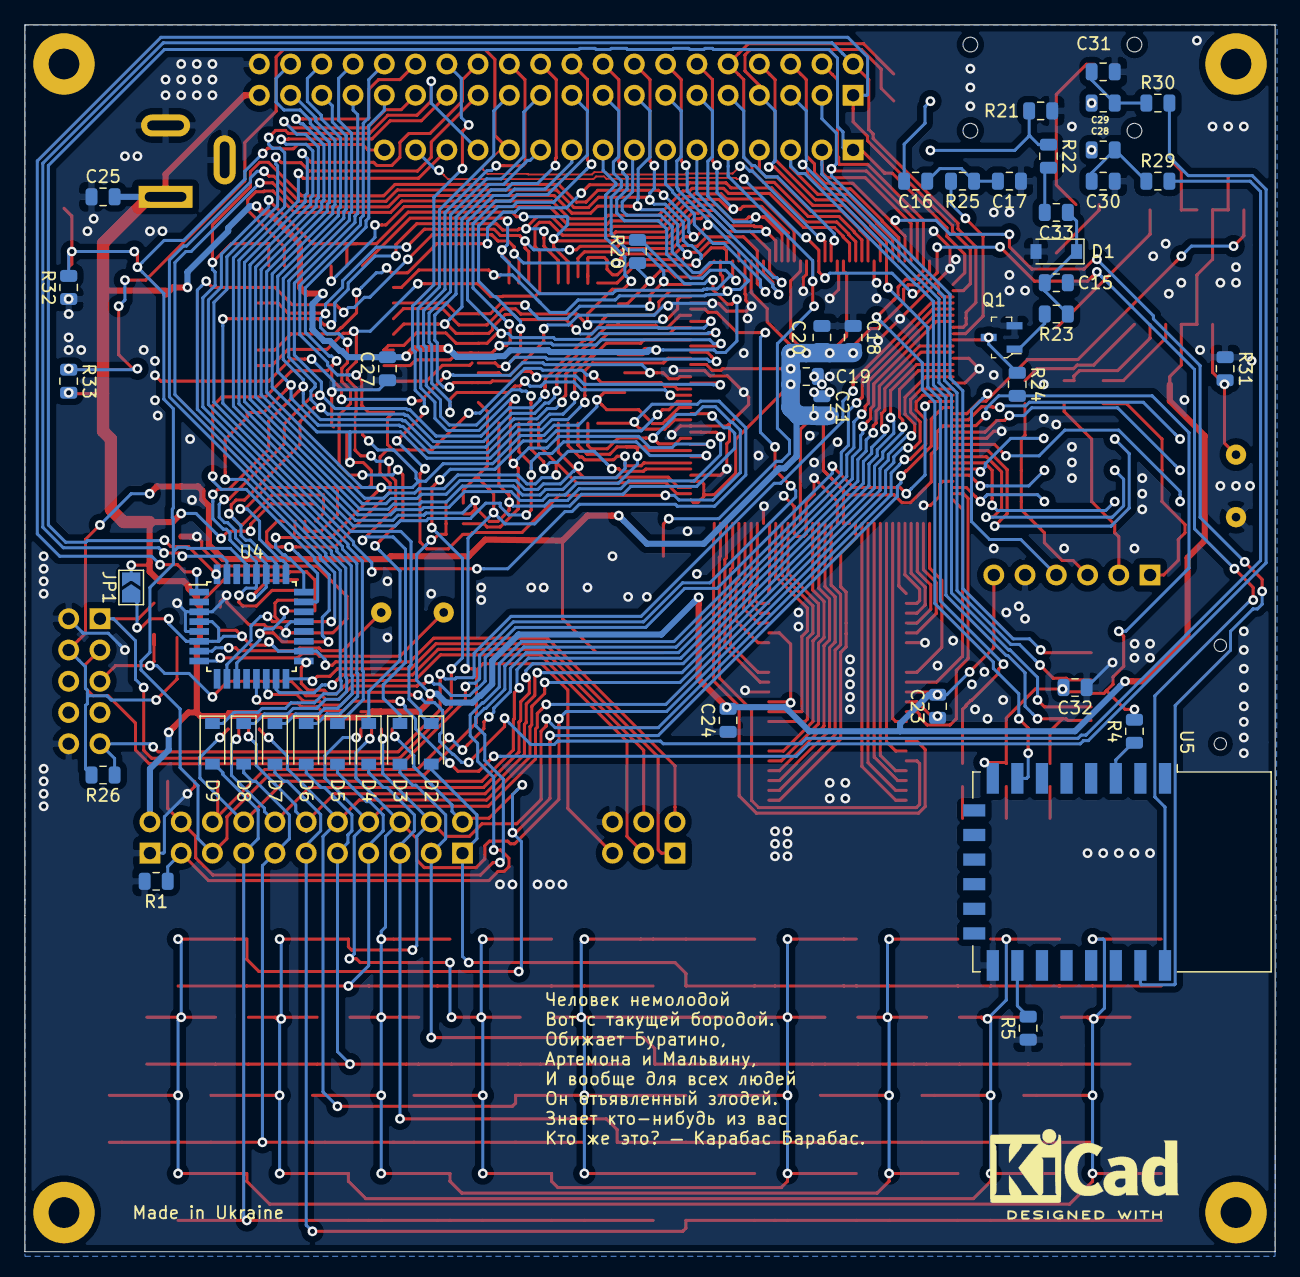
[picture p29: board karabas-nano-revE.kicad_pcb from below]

Board: 2 copper layers, 101.6 x 99.7 mm, 153 parts (45 on the bottom side), 160 nets.

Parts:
C5, C6, C7, C16, C18, C19, C20, C21, C22, C23, C24, C25, C26, C27, C32: 100nF; C_0805_2012Metric
C8: 10p; C_0805_2012Metric
C9: 220uF; CP_EIA-7343-31_Kemet-D_Pad2.25x2.55mm_HandSolder
C10, C11, C12, C13, C28, C29: 10uF; C_0805_2012Metric
C14: 10uF; CP_EIA-3528-21_Kemet-B_Pad1.50x2.35mm_HandSolder
C15, C33: 10nF; C_0805_2012Metric
C17: 3n3; C_0805_2012Metric
C30, C31: 1nF; C_0805_2012Metric
D1, D2, D3, D4, D5, D6, D7, D8, D9: 1N4148W; D_SOD-123
D10: PWR; 0805
D11: SD; 0805
D12: MMC; 0805
H1, H2, H3, H4: MountingHole; MountingHole_2.5mm_Pad
J1: DC 5V; BarrelJack_Wuerth_6941xx301002
J2: TAPE IN/OUT; AUDIO_JACK_3.5MM_SMD
J3: A/V; AUDIO_JACK_3.5MM_SMD
J4: BUS; PinHeader_1x16_P2.54mm_Vertical
J5: KEYBOARD; PinHeader_2x10_P2.54mm_Vertical
J6: BUS; PinHeader_2x20_P2.54mm_Vertical
J7: JTAG; PinHeader_2x05_P2.54mm_Vertical
J9: RGB; PinHeader_1x06_P2.54mm_Vertical
J10: PWR; PinHeader_1x02_P2.54mm_Vertical
J11: AVR ISP; PinHeader_2x03_P2.54mm_Vertical
JP1: SolderJumper_2_Open; SolderJumper-2_P1.3mm_Open_TrianglePad1.0x1.5mm
Q1: BC846B; SOT-23-3
R1, R2, R3, R4, R5, R21, R23, R24, R26, R27, R28, R29, R30, R33, R37, R38: 10k; R_0805_2012Metric
R7, R10, R13, R22: 510; R_0805_2012Metric
R8, R11, R14: 1k; R_0805_2012Metric
R9, R12, R15: 2k; R_0805_2012Metric
R16, R17, R18, R19: 75; R_0805_2012Metric
R20: 2k2; R_0805_2012Metric
R25: 33k; R_0805_2012Metric
R31: 4,7M; R_0805_2012Metric
R32: 47k; R_0805_2012Metric
R34, R35, R36: 470; R_0805_2012Metric
RN1, RN2, RN3, RN4, RN5: 10k; R_Array_Convex_4x0612
SW1: RESET; TACTILE_SWITCH_SMD_5.2MM
SW2: NMI; TACTILE_SWITCH_SMD_5.2MM
SW3: 1; TACTILE_SWITCH_SMD_5.2MM
SW4: 2; TACTILE_SWITCH_SMD_5.2MM
SW5: 3; TACTILE_SWITCH_SMD_5.2MM
SW6: 4; TACTILE_SWITCH_SMD_5.2MM
SW7: 5; TACTILE_SWITCH_SMD_5.2MM
SW8: 6; TACTILE_SWITCH_SMD_5.2MM
SW9: 7; TACTILE_SWITCH_SMD_5.2MM
SW10: 8; TACTILE_SWITCH_SMD_5.2MM
SW11: 9; TACTILE_SWITCH_SMD_5.2MM
SW12: 0; TACTILE_SWITCH_SMD_5.2MM
SW13: Q; TACTILE_SWITCH_SMD_5.2MM
SW14: A; TACTILE_SWITCH_SMD_5.2MM
SW15: CS; TACTILE_SWITCH_SMD_5.2MM
SW16: W; TACTILE_SWITCH_SMD_5.2MM
SW17: S; TACTILE_SWITCH_SMD_5.2MM
SW18: Z; TACTILE_SWITCH_SMD_5.2MM
SW19: E; TACTILE_SWITCH_SMD_5.2MM
SW20: D; TACTILE_SWITCH_SMD_5.2MM
SW21: X; TACTILE_SWITCH_SMD_5.2MM
SW22: R; TACTILE_SWITCH_SMD_5.2MM
SW23: F; TACTILE_SWITCH_SMD_5.2MM
SW24: C; TACTILE_SWITCH_SMD_5.2MM
SW25: T; TACTILE_SWITCH_SMD_5.2MM
SW26: G; TACTILE_SWITCH_SMD_5.2MM
SW27: V; TACTILE_SWITCH_SMD_5.2MM
SW28: Y; TACTILE_SWITCH_SMD_5.2MM
SW29: H; TACTILE_SWITCH_SMD_5.2MM
SW30: B; TACTILE_SWITCH_SMD_5.2MM
SW31: U; TACTILE_SWITCH_SMD_5.2MM
SW32: J; TACTILE_SWITCH_SMD_5.2MM
SW33: N; TACTILE_SWITCH_SMD_5.2MM
SW34: I; TACTILE_SWITCH_SMD_5.2MM
SW35: K; TACTILE_SWITCH_SMD_5.2MM
SW36: M; TACTILE_SWITCH_SMD_5.2MM
SW37: O; TACTILE_SWITCH_SMD_5.2MM
SW38: L; TACTILE_SWITCH_SMD_5.2MM
SW39: SS; TACTILE_SWITCH_SMD_5.2MM
SW40: P; TACTILE_SWITCH_SMD_5.2MM
SW41: Enter; TACTILE_SWITCH_SMD_5.2MM
SW42: Space; TACTILE_SWITCH_SMD_5.2MM
U1: Z80; TQFP-44_14x14mm_P0.8mm
U2: 27C512; PLCC-32_11.4x14.0mm_P1.27mm-bigpads
U3: BS62LV1600; TSOP-II-44_10.16x18.41mm_P0.8mm
U4: ATmega8A-AU; TQFP-32_7x7mm_P0.8mm
U5: ESP-12E
U6: EPM3256ATC144; LQFP-144_20x20mm_P0.5mm
U7: MicroSD; GCT-MEM2055-00-190-01-A
U9: AD724; SOIC-16W_7.5x10.3mm_P1.27mm
U13: LM1117-3.3; SOT-223
Y1: 28MHz; Oscillator_SMD_EuroQuartz_XO91-4Pin_7.0x5.0mm_HandSoldering
Y3: 4.43MHz; HC49US
Y4: 20MHz; HC49US

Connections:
+3V3: C13.2, C18.2, C19.2, C20.2, C21.2, C32.2, J7.4, R4.2, R24.2, R26.2, R27.2, R34.1, U5.8, U6.24, U6.50, U6.51, U6.58, U6.73, U6.76, U6.95, U6.115, U6.123, U6.130, U6.144, U7.4, U13.2, Y1.1, Y1.4
/A0: J6.20, U1.27, U2.11, U6.97
/A1: J6.19, U1.28, U2.10, U6.98
/A2: J4.10, U1.29, U2.9, U6.100
/A3: J6.22, U1.30, U2.8, U6.102
/A4: J4.9, U1.31, U2.7, U6.106
/A5: J6.17, U1.32, U2.6, U6.108
/A6: J4.8, U1.34, U2.5, U6.110
/A7: J6.18, U1.35, U2.4, U6.112
/A8: D7.1, J4.7, U1.36, U2.29, U6.116
/A9: D4.1, J6.14, U1.37, U2.28, U6.118
/A10: D3.1, J6.11, U1.38, U2.24, U6.120
/A11: D2.1, J6.12, U1.40, U2.27, U6.121
/A12: D5.1, J4.6, U1.41, U2.3, U6.119
/A13: D6.1, J6.13, U1.42, U2.30, U6.117
/A14: D8.1, J6.15, U1.43, U6.113
/A15: D9.1, J6.16, U1.44, U6.111
/AVR_MISO: J11.1, U4.16
/AVR_MOSI: J11.4, U4.15
/AVR_SCK: J11.3, U4.17
/AY_BC1: J4.1, U4.32, U6.1
/AY_BDIR: J6.1, U4.1, U6.2
/AY_OUT_L: R30.2, U4.13
/AY_OUT_R: R29.2, U4.14
/B0: R15.1, U6.34
/B1: R14.1, U6.32
/B2: R13.1, U6.31
/BEEPER: J6.2, U4.31, U6.8
/BLUE: C7.2, J9.3, R13.2, R14.2, R15.2, R18.1
/CLK28: J4.5, U6.125, Y1.3
/CLKX: J6.9, U6.128
/CLK_BUS: J4.4, U6.134
/CLK_CPU: R20.1, U1.1, U6.109
/CSYNC: J9.4, U6.22, U9.16
/D0: J6.32, RN1.4, U1.9, U2.13, U4.23, U6.91
/D1: J6.38, RN1.3, U1.10, U2.14, U4.24, U6.88
/D2: J6.37, RN1.2, U1.7, U2.15, U4.25, U6.96
/D3: J6.34, RN1.1, U1.3, U2.18, U4.26, U6.103
/D4: J6.33, RN2.4, U1.2, U2.19, U4.27, U6.107
/D5: J6.35, RN2.3, U1.4, U2.20, U4.28, U6.101
/D6: J6.36, RN2.2, U1.5, U2.21, U4.10, U6.99
/D7: J6.31, RN2.1, U1.8, U2.22, U4.11, U6.93
/G0: R12.1, U6.30
/G1: R11.1, U6.29
/G2: R10.1, U6.28
/GREEN: C6.2, J9.2, R10.2, R11.2, R12.2, R17.1
/IO13: J6.6, U5.21, U6.140
/IO16: J6.4, U5.7, U6.143
/IOE: J4.15, U5.22, U6.126
/KA8: D7.2, J5.11, SW15.1, SW15.2, SW18.1, SW18.2, SW21.1, SW21.2, SW24.1, SW24.2, SW27.1, SW27.2
/KA9: D4.2, J5.5, SW14.1, SW14.2, SW17.1, SW17.2, SW20.1, SW20.2, SW23.1, SW23.2, SW26.1, SW26.2
/KA10: D3.2, J5.3, SW13.1, SW13.2, SW16.1, SW16.2, SW19.1, SW19.2, SW22.1, SW22.2, SW25.1, SW25.2
/KA11: D2.2, J5.1, SW3.1, SW3.2, SW4.1, SW4.2, SW5.1, SW5.2, SW6.1, SW6.2, SW7.1, SW7.2
/KA12: D5.2, J5.7, SW8.1, SW8.2, SW9.1, SW9.2, SW10.1, SW10.2, SW11.1, SW11.2, SW12.1, SW12.2
/KA13: D6.2, J5.9, SW28.1, SW28.2, SW31.1, SW31.2, SW34.1, SW34.2, SW37.1, SW37.2, SW40.1, SW40.2
/KA14: D8.2, J5.13, SW29.1, SW29.2, SW32.1, SW32.2, SW35.1, SW35.2, SW38.1, SW38.2, SW41.1, SW41.2
/KA15: D9.2, J5.15, SW30.1, SW30.2, SW33.1, SW33.2, SW36.1, SW36.2, SW39.1, SW39.2, SW42.1, SW42.2
/KB0: J5.2, RN4.1, SW3.3, SW3.4, SW12.3, SW12.4, SW13.3, SW13.4, SW14.3, SW14.4, SW15.3, SW15.4, SW40.3, SW40.4, SW41.3, SW41.4, SW42.3, SW42.4, U6.21
/KB1: J5.4, RN4.2, SW4.3, SW4.4, SW11.3, SW11.4, SW16.3, SW16.4, SW17.3, SW17.4, SW18.3, SW18.4, SW37.3, SW37.4, SW38.3, SW38.4, SW39.3, SW39.4, U6.19
/KB2: J5.6, RN4.3, SW5.3, SW5.4, SW10.3, SW10.4, SW19.3, SW19.4, SW20.3, SW20.4, SW21.3, SW21.4, SW34.3, SW34.4, SW35.3, SW35.4, SW36.3, SW36.4, U6.18
/KB3: J5.8, RN4.4, SW6.3, SW6.4, SW9.3, SW9.4, SW22.3, SW22.4, SW23.3, SW23.4, SW24.3, SW24.4, SW31.3, SW31.4, SW32.3, SW32.4, SW33.3, SW33.4, U6.16
/KB4: J5.10, RN5.1, SW7.3, SW7.4, SW8.3, SW8.4, SW25.3, SW25.4, SW26.3, SW26.4, SW27.3, SW27.4, SW28.3, SW28.4, SW29.3, SW29.4, SW30.3, SW30.4, U6.15
/KB5: J5.12, RN5.2, U6.14
/KB6: J5.14, RN5.3, U6.12
/KB7: J5.16, RN5.4, U6.11
/MA0: U3.5, U6.38
/MA1: U3.4, U6.39
/MA2: U3.3, U6.40
/MA3: U3.2, U6.41
/MA4: U3.1, U6.42
/MA5: U3.44, U6.63
/MA6: U3.43, U6.65
/MA7: U3.42, U6.66
/MA8: U3.39, U6.68
/MA9: U3.28, U6.60
/MA10: U3.27, U6.56
/MA11: U3.26, U6.55
/MA12: U3.25, U6.54
/MA13: U3.24, U6.53
/MA14: U3.23, U6.49
/MA15: U3.22, U6.48
/MA16: U3.21, U6.47
/MA17: U3.20, U6.46
/MA18: U3.19, U6.45
/MA19: U3.18, U6.71
/MA20: U3.16, U6.72
/MAGIC: J5.20, R2.1, U6.6
/MAPCOND: J6.8, R36.1, U6.137
/MD0: U3.9, U6.37
/MD1: U3.10, U6.36
/MD2: U3.13, U6.35
/MD3: U3.14, U6.43
/MD4: U3.31, U6.61
/MD5: U3.32, U6.62
/MD6: U3.35, U6.70
/MD7: U3.36, U6.69
/R0: R9.1, U6.27
/R1: R8.1, U6.25
/R2: R7.1, U6.23
/RED: C5.2, J9.1, R7.2, R8.2, R9.2, R16.1
/ROM_A14: U2.31, U6.131
/ROM_A15: U2.2, U6.122
/SD_CLK: J4.2, U6.141, U7.5
/SD_DI: J6.5, U6.139, U7.3
/SD_DO: J6.3, U6.142, U7.7
/SPECIAL: J5.18, R3.1, U6.7
/TCK: J7.1, R28.2, U6.89
/TDI: J7.9, R26.1, U6.4
/TDO: J7.3, U6.104
/TMS: J7.5, R27.1, U6.20
/TURBO: J5.19, R1.1, U6.5
/VCCJP: C22.2, J11.2, JP1.1, U4.4, U4.6, U4.18
/~BTN_NMI: J4.12, R33.1, SW2.1, SW2.2, U6.127
/~BUSACK: J4.13, U1.20, U6.80
/~BUSREQ: J4.14, RN3.2, U1.22, U6.84
/~BUS_IORQGE: J6.10, R38.1, U6.133
/~BUS_ROMCS: J6.7, R37.1, U6.136
/~HALT: J6.26, U1.14, U6.81
/~INT: J6.25, U1.12, U6.86
/~IORQ: J6.29, U1.16, U6.75
/~M1: J6.21, U1.24, U6.90
/~MRD: U3.41, U6.67
/~MREQ: J6.27, U1.15, U6.79
/~MWR: U3.17, U6.44
/~NMI: J6.28, RN3.4, U1.13, U6.83
/~RD: J6.30, U1.18, U6.74
/~RFSH: J4.11, U1.25, U6.92
/~ROMCS: U2.25, U6.132
/~SD_CS: J4.3, R35.1, U6.138, U7.2
/~WAIT: J6.23, RN3.3, U1.21, U6.82
/~WR: J6.24, U1.19, U6.78
GND: C8.1, C10.1, C11.1, C12.1, C13.1, C14.2, C15.1, C17.1, C18.1, C19.1, C20.1, C21.1, C22.1, C23.1, C24.1, C25.1, C26.1, C27.1, C30.1, C31.1, C32.1, D1.2, D10.2, D11.2, D12.2, J1.2, J1.3, J2.1, J2.2, J3.1, J6.40, J7.2, J7.10, J9.5, J10.1, J11.6, Q1.2, R1.2, R2.2, R3.2, R5.1, R16.2, R17.2, R18.2, R21.1, R28.1, R31.1, R32.1, R37.2, R38.2, SW1.3, SW1.4, SW2.3, SW2.4, U1.26, U2.16, U2.23, U3.6, U3.12, U3.34, U4.3, U4.5, U4.21, U5.15, U6.3, U6.13, U6.17, U6.26, U6.33, U6.52, U6.57, U6.59, U6.64, U6.77, U6.85, U6.94, U6.105, U6.114, U6.124, U6.129, U6.135, U7.6, U9.1, U9.2, U9.12, U9.13, U13.1, Y1.2, Y3.1
unnamed: C5.1, U9.6
unnamed: C6.1, U9.7
unnamed: C7.1, U9.8
unnamed: C8.2, R31.2, U9.3, Y3.2
unnamed: C9.1, U9.10
unnamed: C9.2, R19.1
unnamed: C15.2, C33.1, D1.1, R23.1
unnamed: C16.1, C17.2, R25.1
unnamed: C16.2, J2.3
unnamed: C28.1, C30.2, R29.1
unnamed: C28.2, J3.4
unnamed: C29.1, C31.2, R30.1
unnamed: C29.2, J3.3
unnamed: C33.2, R22.2
unnamed: D10.1, R34.2
unnamed: D11.1, R35.2
unnamed: D12.1, R36.2
unnamed: J2.4, R21.2, R22.1
unnamed: J3.2, R19.2
unnamed: Q1.1, R23.2
unnamed: R4.1, U5.3
unnamed: R5.2, U5.16
unnamed: U4.7, Y4.2
unnamed: U4.8, Y4.1
TAPE_IN: Q1.3, R24.1, U6.10
TAPE_OUT: R25.2, U6.9
VCC: C10.2, C11.2, C12.2, C23.2, C24.2, C25.2, C26.2, C27.2, J1.1, J6.39, J9.6, J10.2, JP1.2, R20.2, R33.2, RN1.5, RN1.6, RN1.7, RN1.8, RN2.5, RN2.6, RN2.7, RN2.8, RN3.5, RN3.6, RN3.7, RN3.8, RN4.5, RN4.6, RN4.7, RN4.8, RN5.5, RN5.6, RN5.7, RN5.8, U1.6, U2.32, U3.11, U3.33, U3.40, U9.4, U9.5, U9.14, U9.15, U13.3
~RESET: C14.1, J4.16, J5.17, J11.5, R32.2, RN3.1, SW1.1, SW1.2, U1.23, U4.29, U6.87

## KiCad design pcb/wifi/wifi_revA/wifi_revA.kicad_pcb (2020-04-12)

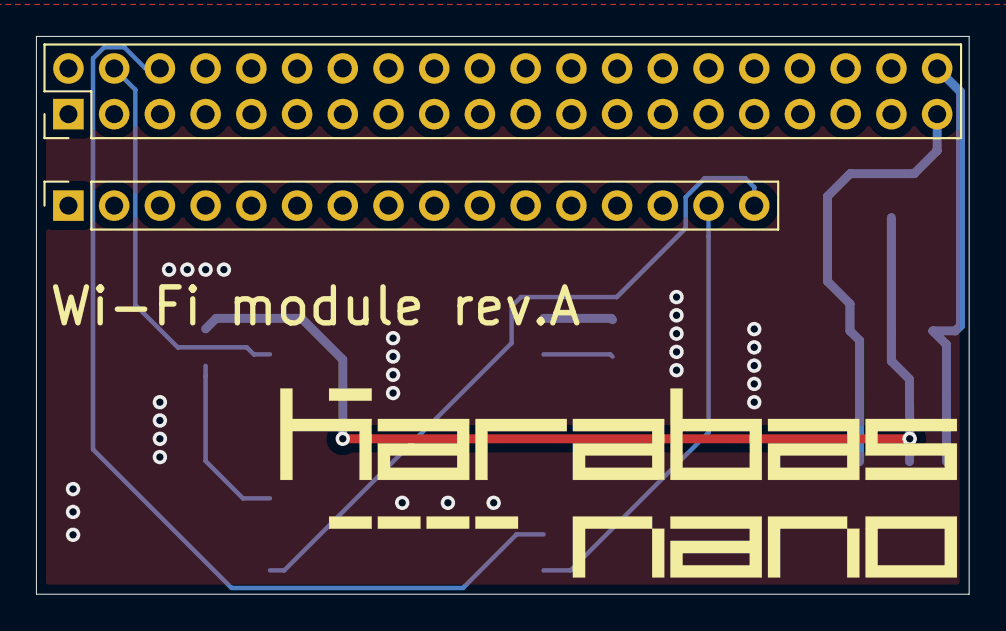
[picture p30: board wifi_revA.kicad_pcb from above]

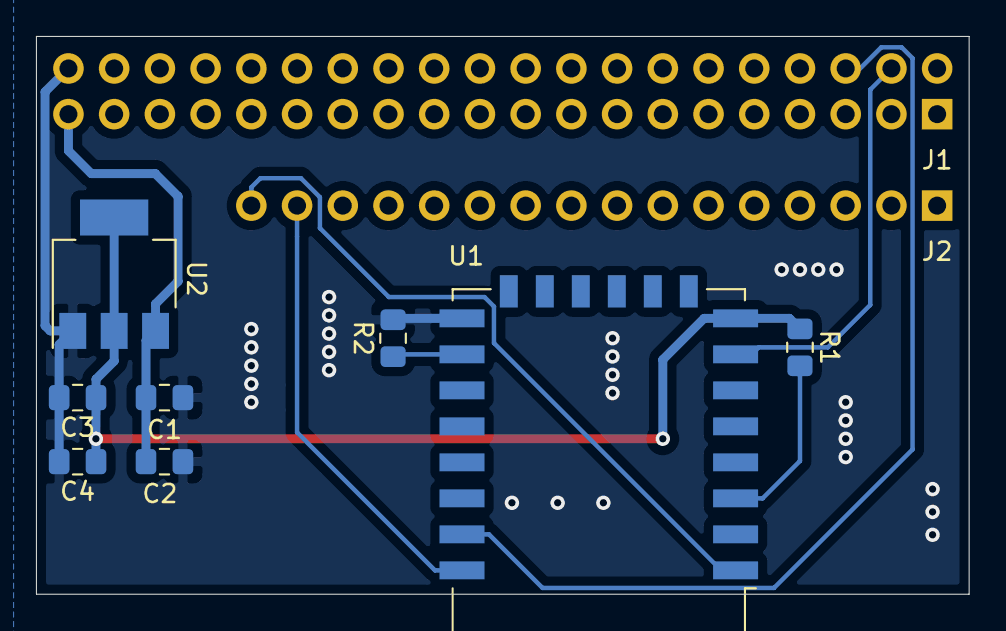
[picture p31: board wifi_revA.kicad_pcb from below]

Board: 2 copper layers, 51.8 x 31.0 mm, 10 parts (8 on the bottom side), 9 nets.

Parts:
C1, C4: 100nF; C_0805_2012Metric_Pad1.15x1.40mm_HandSolder
C2, C3: 1uF; C_0805_2012Metric_Pad1.15x1.40mm_HandSolder
J1: ZX BUS; PinHeader_2x20_P2.54mm_Vertical
J2: ZX BUS; PinSocket_1x16_P2.54mm_Vertical
R1, R2: 10k; R_0805_2012Metric_Pad1.15x1.40mm_HandSolder
U1: ESP-12E
U2: AMS1117-3.3; SOT-223-3_TabPin2

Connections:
+3V3: C3.1, C4.1, R1.1, U1.8, U2.2
GND: C1.2, C2.2, C3.2, C4.2, J1.40, R2.2, U1.15, U2.1
unnamed: R1.2, U1.3
unnamed: R2.1, U1.16
UART_CTS: J1.4, U1.7
UART_RX: J2.15, U1.22
UART_TX: J1.6, U1.21
VCC: C1.1, C2.1, J1.39, U2.3
~RESET: J2.16, U1.1

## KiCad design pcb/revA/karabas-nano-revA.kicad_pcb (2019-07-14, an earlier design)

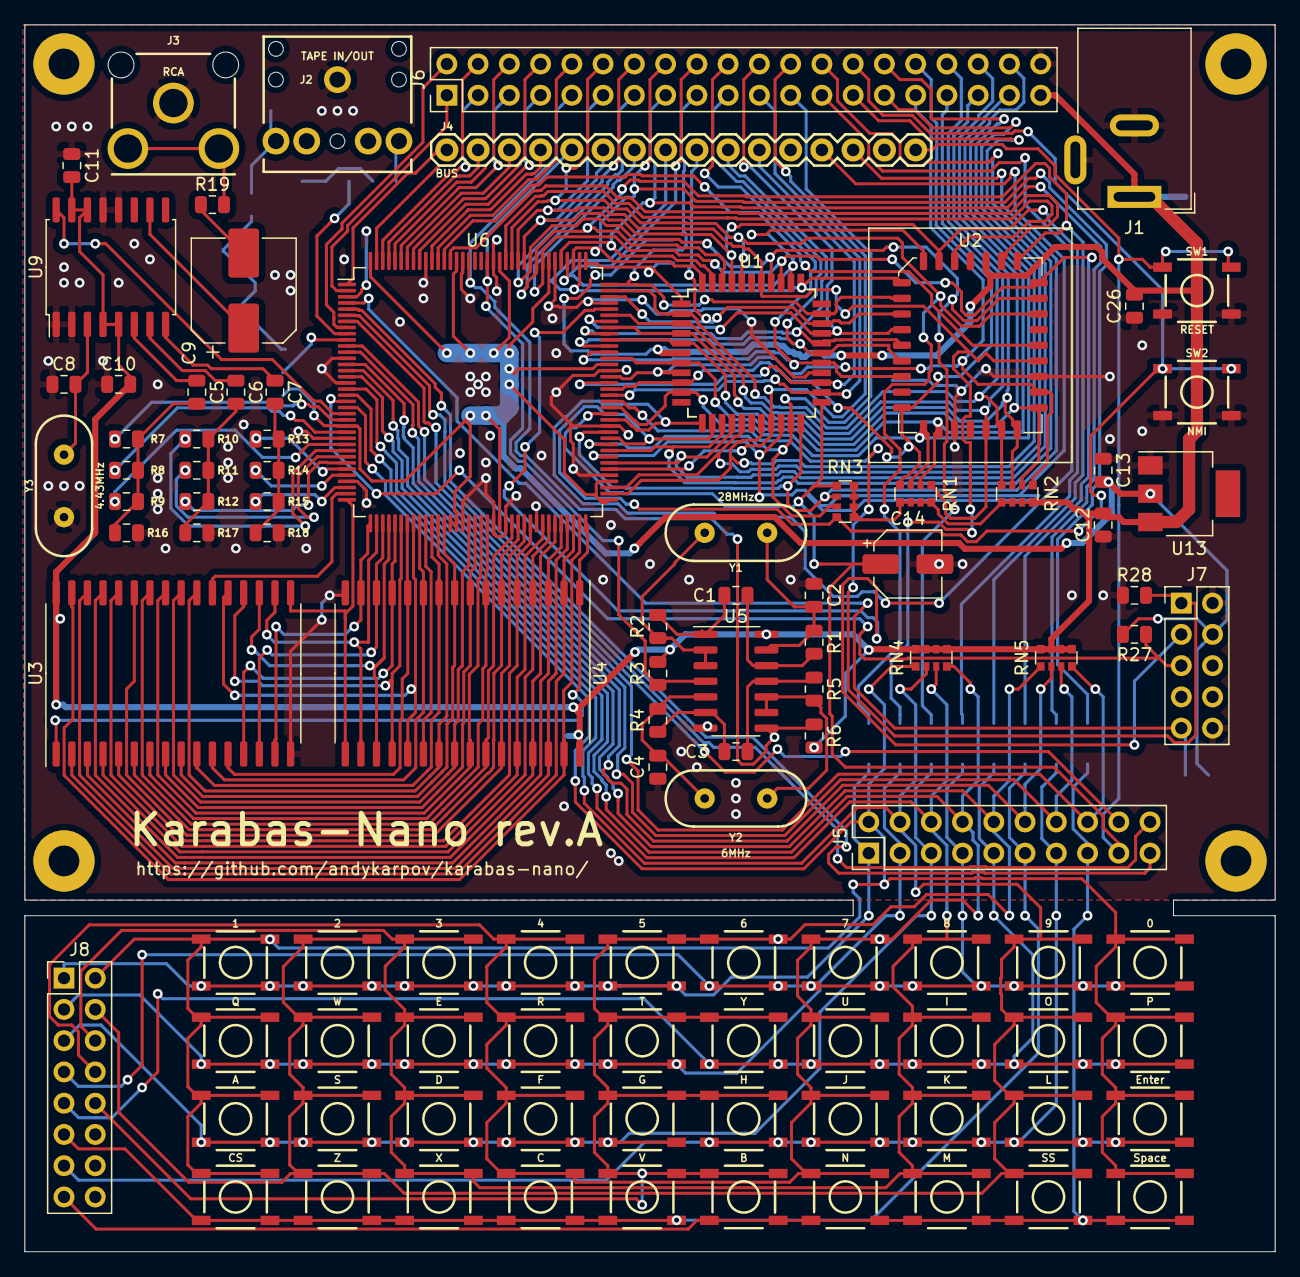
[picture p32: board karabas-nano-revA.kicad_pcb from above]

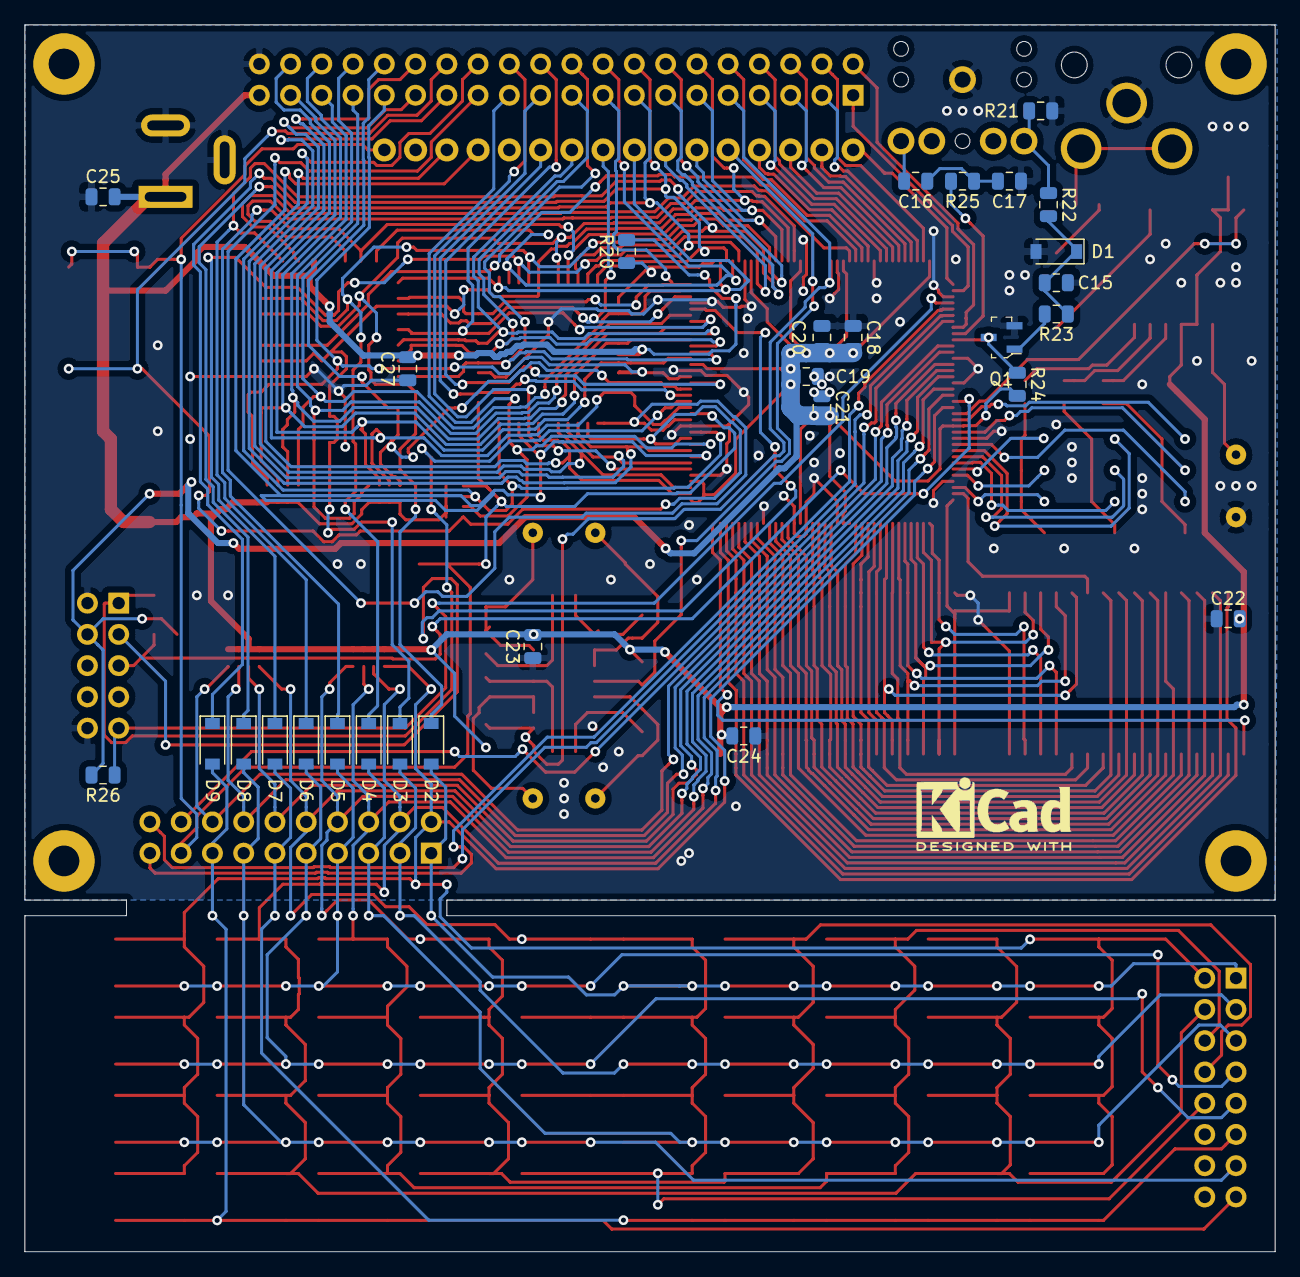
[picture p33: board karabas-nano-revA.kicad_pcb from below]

Board: 2 copper layers, 101.6 x 99.7 mm, 135 parts (29 on the bottom side), 148 nets.

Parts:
C1, C3: 100p; C_0805_2012Metric
C2, C4: 22p; C_0805_2012Metric
C5, C6, C7, C16, C18, C19, C20, C21, C22, C23, C24, C25, C26, C27: 100nF; C_0805_2012Metric
C8: 10p; C_0805_2012Metric
C9: 220uF; CP_Elec_8x6.5
C10, C11, C12, C13: 10uF; C_0805_2012Metric
C14: 10uF; CP_Elec_5x4.4
C15: 10nF; C_0805_2012Metric
C17: 3n3; C_0805_2012Metric
D1, D2, D3, D4, D5, D6, D7, D8, D9: 1N4148W; D_SOD-123
H1, H2, H3, H4: MountingHole; MountingHole_2.5mm_Pad
J1: DC 5V; BarrelJack_Wuerth_6941xx301002
J2: TAPE IN/OUT; AUDIO-JACK
J3: RCA
J4: BUS; 1X16
J5: KEYBOARD; PinHeader_2x10_P2.54mm_Vertical
J6: BUS; PinHeader_2x20_P2.54mm_Vertical
J7: JTAG; PinHeader_2x05_P2.54mm_Vertical
J8: KEYBOARD; PinHeader_2x08_P2.54mm_Vertical
K0: 0; TACTILE_SWITCH_SMD_5.2MM
K1: 1; TACTILE_SWITCH_SMD_5.2MM
K2: 2; TACTILE_SWITCH_SMD_5.2MM
K3: 3; TACTILE_SWITCH_SMD_5.2MM
K4: 4; TACTILE_SWITCH_SMD_5.2MM
K5: 5; TACTILE_SWITCH_SMD_5.2MM
K6: 6; TACTILE_SWITCH_SMD_5.2MM
K7: 7; TACTILE_SWITCH_SMD_5.2MM
K8: 8; TACTILE_SWITCH_SMD_5.2MM
K9: 9; TACTILE_SWITCH_SMD_5.2MM
KA1: A; TACTILE_SWITCH_SMD_5.2MM
KB1: B; TACTILE_SWITCH_SMD_5.2MM
KC1: C; TACTILE_SWITCH_SMD_5.2MM
KCS1: CS; TACTILE_SWITCH_SMD_5.2MM
KD1: D; TACTILE_SWITCH_SMD_5.2MM
KE1: E; TACTILE_SWITCH_SMD_5.2MM
KEnter1: Enter; TACTILE_SWITCH_SMD_5.2MM
KF1: F; TACTILE_SWITCH_SMD_5.2MM
KG1: G; TACTILE_SWITCH_SMD_5.2MM
KH1: H; TACTILE_SWITCH_SMD_5.2MM
KI1: I; TACTILE_SWITCH_SMD_5.2MM
KJ1: J; TACTILE_SWITCH_SMD_5.2MM
KK1: K; TACTILE_SWITCH_SMD_5.2MM
KL1: L; TACTILE_SWITCH_SMD_5.2MM
KM1: M; TACTILE_SWITCH_SMD_5.2MM
KN1: N; TACTILE_SWITCH_SMD_5.2MM
KO1: O; TACTILE_SWITCH_SMD_5.2MM
KP1: P; TACTILE_SWITCH_SMD_5.2MM
KQ1: Q; TACTILE_SWITCH_SMD_5.2MM
KR1: R; TACTILE_SWITCH_SMD_5.2MM
KS1: S; TACTILE_SWITCH_SMD_5.2MM
KSS1: SS; TACTILE_SWITCH_SMD_5.2MM
KSpace1: Space; TACTILE_SWITCH_SMD_5.2MM
KT1: T; TACTILE_SWITCH_SMD_5.2MM
KU1: U; TACTILE_SWITCH_SMD_5.2MM
KV1: V; TACTILE_SWITCH_SMD_5.2MM
KW1: W; TACTILE_SWITCH_SMD_5.2MM
KX1: X; TACTILE_SWITCH_SMD_5.2MM
KY1: Y; TACTILE_SWITCH_SMD_5.2MM
KZ1: Z; TACTILE_SWITCH_SMD_5.2MM
Q1: BC846B; SOT-23-3
R1, R2, R4, R5: 470; R_0805_2012Metric
R3, R6: 4k7; R_0805_2012Metric
R7, R10, R13, R22: 510; R_0805_2012Metric
R8, R11, R14: 1k; R_0805_2012Metric
R9, R12, R15: 2k; R_0805_2012Metric
R16, R17, R18, R19: 75; R_0805_2012Metric
R20: 2k2; R_0805_2012Metric
R21, R23, R24, R26, R27, R28: 10k; R_0805_2012Metric
R25: 33k; R_0805_2012Metric
RN1, RN2, RN3, RN4, RN5: 10k; R_Array_Convex_4x0612
SW1: RESET; TACTILE_SWITCH_SMD_5.2MM
SW2: NMI; TACTILE_SWITCH_SMD_5.2MM
U1: Z80; TQFP-44_10x10mm_P0.8mm
U2: 27C512; PLCC-32_11.4x14.0mm_P1.27mm
U3, U4: BS62LV4006; SSOP-32_11.305x20.495mm_P1.27mm
U5: 74HC04; SOIC-14_3.9x8.7mm_P1.27mm
U6: EPM3256ATC144; LQFP-144_20x20mm_P0.5mm
U9: AD724; SOIC-16W_7.5x10.3mm_P1.27mm
U13: LM1117-3.3; SOT-223
Y1: 28MHz; HC49US
Y2: 6MHz; HC49US
Y3: 4.43MHz; HC49US

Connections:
+3V3: C13.2, C18.2, C19.2, C20.2, C21.2, J7.4, R24.2, R26.2, R27.2, U6.24, U6.50, U6.51, U6.58, U6.73, U6.76, U6.95, U6.115, U6.123, U6.130, U6.144, U13.2
/A0: J6.20, U1.27, U2.11, U6.97
/A1: J6.19, U1.28, U2.10, U6.98
/A2: J4.10, U1.29, U2.9, U6.100
/A3: J6.22, U1.30, U2.8, U6.102
/A4: J4.9, U1.31, U2.7, U6.106
/A5: J6.17, U1.32, U2.6, U6.108
/A6: J4.8, U1.34, U2.5, U6.110
/A7: J6.18, U1.35, U2.4, U6.112
/A8: D7.1, J4.7, U1.36, U2.29, U6.116
/A9: D4.1, J6.14, U1.37, U2.28, U6.118
/A10: D3.1, J6.11, U1.38, U2.24, U6.120
/A11: D2.1, J6.12, U1.40, U2.27, U6.121
/A12: D5.1, J4.6, U1.41, U2.3, U6.119
/A13: D6.1, J6.13, U1.42, U2.30, U6.117
/A14: D8.1, J6.15, U1.43, U6.113
/A15: D9.1, J6.16, U1.44, U6.111
/B0: R15.1, U6.34
/B1: R14.1, U6.32
/B2: R13.1, U6.31
/BEEPER: J6.2, U6.8
/CLK28: J4.5, R3.1, U5.4, U6.125
/CLKX: J6.9, R6.1, U5.8, U6.128
/CLK_BUS: J4.4, U6.134
/CLK_CPU: R20.1, U1.1, U6.109
/CSYNC: U6.22, U9.16
/D0: J6.32, RN1.4, U1.9, U2.13, U6.91
/D1: J6.38, RN1.3, U1.10, U2.14, U6.88
/D2: J6.37, RN1.2, U1.7, U2.15, U6.96
/D3: J6.34, RN1.1, U1.3, U2.18, U6.103
/D4: J6.33, RN2.4, U1.2, U2.19, U6.107
/D5: J6.35, RN2.3, U1.4, U2.20, U6.101
/D6: J6.36, RN2.2, U1.5, U2.21, U6.99
/D7: J6.31, RN2.1, U1.8, U2.22, U6.93
/G0: R12.1, U6.30
/G1: R11.1, U6.29
/G2: R10.1, U6.28
/IO10: J6.8, U6.137
/IO11: J4.3, U6.138
/IO12: J6.5, U6.139
/IO13: J6.6, U6.140
/IO14: J4.2, U6.141
/IO15: J6.3, U6.142
/IO16: J6.4, U6.143
/IO18: J4.1, U6.1
/IO19: J6.1, U6.2
/KA8: D7.2, J5.11, J8.11, KC1.1, KC1.2, KCS1.1, KCS1.2, KV1.1, KV1.2, KX1.1, KX1.2, KZ1.1, KZ1.2
/KA9: D4.2, J5.5, J8.5, KA1.1, KA1.2, KD1.1, KD1.2, KF1.1, KF1.2, KG1.1, KG1.2, KS1.1, KS1.2
/KA10: D3.2, J5.3, J8.3, KE1.1, KE1.2, KQ1.1, KQ1.2, KR1.1, KR1.2, KT1.1, KT1.2, KW1.1, KW1.2
/KA11: D2.2, J5.1, J8.1, K1.1, K1.2, K2.1, K2.2, K3.1, K3.2, K4.1, K4.2, K5.1, K5.2
/KA12: D5.2, J5.7, J8.7, K0.1, K0.2, K6.1, K6.2, K7.1, K7.2, K8.1, K8.2, K9.1, K9.2
/KA13: D6.2, J5.9, J8.9, KI1.1, KI1.2, KO1.1, KO1.2, KP1.1, KP1.2, KU1.1, KU1.2, KY1.1, KY1.2
/KA14: D8.2, J5.13, J8.13, KEnter1.1, KEnter1.2, KH1.1, KH1.2, KJ1.1, KJ1.2, KK1.1, KK1.2, KL1.1, KL1.2
/KA15: D9.2, J5.15, J8.15, KB1.1, KB1.2, KM1.1, KM1.2, KN1.1, KN1.2, KSS1.1, KSS1.2, KSpace1.1, KSpace1.2
/KB0: J5.2, J8.2, K0.3, K0.4, K1.3, K1.4, KA1.3, KA1.4, KCS1.3, KCS1.4, KEnter1.3, KEnter1.4, KP1.3, KP1.4, KQ1.3, KQ1.4, KSpace1.3, KSpace1.4, RN4.1, U6.21
/KB1: J5.4, J8.4, K2.3, K2.4, K9.3, K9.4, KL1.3, KL1.4, KO1.3, KO1.4, KS1.3, KS1.4, KSS1.3, KSS1.4, KW1.3, KW1.4, KZ1.3, KZ1.4, RN4.2, U6.19
/KB2: J5.6, J8.6, K3.3, K3.4, K8.3, K8.4, KD1.3, KD1.4, KE1.3, KE1.4, KI1.3, KI1.4, KK1.3, KK1.4, KM1.3, KM1.4, KX1.3, KX1.4, RN4.3, U6.18
/KB3: J5.8, J8.8, K4.3, K4.4, K7.3, K7.4, KC1.3, KC1.4, KF1.3, KF1.4, KJ1.3, KJ1.4, KN1.3, KN1.4, KR1.3, KR1.4, KU1.3, KU1.4, RN4.4, U6.16
/KB4: J5.10, J8.10, K5.3, K5.4, K6.3, K6.4, KB1.3, KB1.4, KG1.3, KG1.4, KH1.3, KH1.4, KT1.3, KT1.4, KV1.3, KV1.4, KY1.3, KY1.4, RN5.1, U6.15
/KB5: J5.12, RN5.2, U6.14
/KB6: J5.14, RN5.3, U6.12
/KB7: J5.16, RN5.4, U6.11
/MA0: U3.12, U4.12, U6.43
/MA1: U3.11, U4.11, U6.45
/MA2: U3.10, U4.10, U6.47
/MA3: U3.9, U4.9, U6.49
/MA4: U3.8, U4.8, U6.54
/MA5: U3.7, U4.7, U6.56
/MA6: U3.6, U4.6, U6.61
/MA7: U3.5, U4.5, U6.63
/MA8: U3.27, U4.27, U6.62
/MA9: U3.26, U4.26, U6.60
/MA10: U3.23, U4.23, U6.48
/MA11: U3.25, U4.25, U6.55
/MA12: U3.4, U4.4, U6.66
/MA13: U3.28, U4.28, U6.65
/MA14: U3.3, U4.3, U6.68
/MA15: U3.31, U4.31, U6.71
/MA16: U3.2, U4.2, U6.70
/MA17: U3.30, U4.30, U6.69
/MA18: U3.1, U4.1, U6.72
/MAGIC: J5.20, U6.6
/MD0: U3.13, U4.13, U6.41
/MD1: U3.14, U4.14, U6.39
/MD2: U3.15, U4.15, U6.37
/MD3: U3.17, U4.17, U6.36
/MD4: U3.18, U4.18, U6.38
/MD5: U3.19, U4.19, U6.40
/MD6: U3.20, U4.20, U6.42
/MD7: U3.21, U4.21, U6.44
/R0: R9.1, U6.27
/R1: R8.1, U6.25
/R2: R7.1, U6.23
/ROM_A14: U2.31, U6.131
/ROM_A15: U2.2, U6.122
/SPECIAL: J5.18, U6.7
/TCK: J7.1, R28.2, U6.89
/TDI: J7.9, R26.1, U6.4
/TDO: J7.3, U6.104
/TMS: J7.5, R27.1, U6.20
/TURBO: J5.19, U6.5
/~BUSACK: J4.13, U1.20, U6.80
/~BUSREQ: J4.14, RN3.2, U1.22, U6.84
/~BUS_IORQGE: J6.10, U6.133
/~BUS_ROMCS: J6.7, U6.136
/~HALT: J6.26, U1.14, U6.81
/~INT: J6.25, U1.12, U6.86
/~IORQ: J6.29, U1.16, U6.75
/~M1: J6.21, U1.24, U6.90
/~MCS0: U3.22, U6.35
/~MCS1: U4.22, U6.46
/~MRD: U3.24, U4.24, U6.53
/~MREQ: J6.27, U1.15, U6.79
/~MWR: U3.29, U4.29, U6.67
/~NMI: J6.28, RN3.4, SW2.1, SW2.2, U1.13, U6.83
/~RD: J6.30, U1.18, U6.74
/~RFSH: J4.11, U1.25, U6.92
/~ROMCS: U2.25, U6.132
/~WAIT: J6.23, RN3.3, U1.21, U6.82
/~WR: J6.24, U1.19, U6.78
GND: C2.1, C4.1, C8.1, C10.1, C11.1, C12.1, C13.1, C14.2, C15.1, C17.1, C18.1, C19.1, C20.1, C21.1, C22.1, C23.1, C24.1, C25.1, C26.1, C27.1, D1.2, J1.2, J1.3, J2.SLEE, J3.SHEL, J6.40, J7.2, J7.10, Q1.2, R16.2, R17.2, R18.2, R21.1, R28.1, SW1.3, SW1.4, SW2.3, SW2.4, U1.26, U2.16, U2.23, U3.16, U4.16, U5.7, U6.3, U6.13, U6.17, U6.26, U6.33, U6.52, U6.57, U6.59, U6.64, U6.77, U6.85, U6.94, U6.105, U6.114, U6.124, U6.129, U6.135, U9.1, U9.2, U9.12, U9.13, U13.1, Y3.1
unnamed: C1.1, R2.1, U5.1
unnamed: C1.2, R1.2, U5.12
unnamed: C2.2, R1.1, U5.13, Y1.1
unnamed: C3.1, R5.1, U5.11
unnamed: C3.2, R4.2, U5.6
unnamed: C4.2, R4.1, U5.5, Y2.1
unnamed: C5.1, U9.6
unnamed: C5.2, R7.2, R8.2, R9.2, R16.1
unnamed: C6.1, U9.7
unnamed: C6.2, R10.2, R11.2, R12.2, R17.1
unnamed: C7.1, U9.8
unnamed: C7.2, R13.2, R14.2, R15.2, R18.1
unnamed: C8.2, U9.3, Y3.2
unnamed: C9.1, U9.10
unnamed: C9.2, R19.1
unnamed: C15.2, D1.1, R22.2, R23.1
unnamed: C16.1, C17.2, R25.1
unnamed: C16.2, J2.RING
unnamed: J2.TIP, R21.2, R22.1
unnamed: J3.PIN, J3.SWIT, R19.2
unnamed: Q1.1, R23.2
unnamed: R2.2, U5.2, U5.3, Y1.2
unnamed: R5.2, U5.9, U5.10, Y2.2
TAPE_IN: Q1.3, R24.1, U6.10
TAPE_OUT: R25.2, U6.9
VCC: C10.2, C11.2, C12.2, C22.2, C23.2, C24.2, C25.2, C26.2, C27.2, J1.1, J6.39, R3.2, R6.2, R20.2, RN1.5, RN1.6, RN1.7, RN1.8, RN2.5, RN2.6, RN2.7, RN2.8, RN3.5, RN3.6, RN3.7, RN3.8, RN4.5, RN4.6, RN4.7, RN4.8, RN5.5, RN5.6, RN5.7, RN5.8, U1.6, U2.32, U3.32, U4.32, U5.14, U9.4, U9.5, U9.14, U9.15, U13.3
~RESET: C14.1, J4.16, J5.17, RN3.1, SW1.1, SW1.2, U1.23, U6.87

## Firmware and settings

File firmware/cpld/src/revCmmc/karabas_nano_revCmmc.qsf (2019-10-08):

# -------------------------------------------------------------------------- #
#
# Copyright (C) 1991-2013 Altera Corporation
# Your use of Altera Corporation's design tools, logic functions 
# and other software and tools, and its AMPP partner logic 
# functions, and any output files from any of the foregoing 
# (including device programming or simulation files), and any 
# associated documentation or information are expressly subject 
# to the terms and conditions of the Altera Program License 
# Subscription Agreement, Altera MegaCore Function License 
# Agreement, or other applicable license agreement, including, 
# without limitation, that your use is for the sole purpose of 
# programming logic devices manufactured by Altera and sold by 
# Altera or its authorized distributors.  Please refer to the 
# applicable agreement for further details.
#
# -------------------------------------------------------------------------- #
#
# Quartus II 32-bit
# Version 13.0.1 Build 232 06/12/2013 Service Pack 1 SJ Web Edition
# Date created = 11:31:59  September 25, 2017
#
# -------------------------------------------------------------------------- #
#
# Notes:
#
# 1) The default values for assignments are stored in the file:
#		karabas_128_revA_assignment_defaults.qdf
#    If this file doesn't exist, see file:
#		assignment_defaults.qdf
#
# 2) Altera recommends that you do not modify this file. This
#    file is updated automatically by the Quartus II software
#    and any changes you make may be lost or overwritten.
#
# -------------------------------------------------------------------------- #


set_global_assignment -name FAMILY MAX3000A
set_global_assignment -name DEVICE "EPM3256ATC144-10"
set_global_assignment -name TOP_LEVEL_ENTITY karabas_nano
set_global_assignment -name ORIGINAL_QUARTUS_VERSION "13.0 SP1"
set_global_assignment -name PROJECT_CREATION_TIME_DATE "01:55:00  JULY 10, 2019"
set_global_assignment -name LAST_QUARTUS_VERSION "13.0 SP1"
set_global_assignment -name DEVICE_FILTER_PIN_COUNT 144
set_global_assignment -name ERROR_CHECK_FREQUENCY_DIVISOR "-1"
set_global_assignment -name EDA_SIMULATION_TOOL "ModelSim-Altera (VHDL)"
set_global_assignment -name EDA_OUTPUT_DATA_FORMAT VHDL -section_id eda_simulation

set_global_assignment -name FMAX_REQUIREMENT "28 MHz"
set_global_assignment -name FMAX_REQUIREMENT "28 MHz" -section_id CLK28
set_global_assignment -name MAX7000_OPTIMIZATION_TECHNIQUE BALANCED
set_global_assignment -name AUTO_LCELL_INSERTION ON
set_global_assignment -name OPTIMIZE_HOLD_TIMING OFF
set_global_assignment -name AUTO_GLOBAL_CLOCK_MAX ON
set_global_assignment -name AUTO_GLOBAL_OE_MAX ON
set_global_assignment -name MAX_AUTO_GLOBAL_REGISTER_CONTROLS ON
set_instance_assignment -name CLOCK_SETTINGS CLK14 -to CLK14
set_global_assignment -name FIT_ONLY_ONE_ATTEMPT OFF
set_global_assignment -name SIMULATION_MODE FUNCTIONAL
set_global_assignment -name RESERVE_ALL_UNUSED_PINS_NO_OUTPUT_GND "AS INPUT TRI-STATED"
set_global_assignment -name OPTIMIZE_IOC_REGISTER_PLACEMENT_FOR_TIMING NORMAL
set_global_assignment -name AUTO_TURBO_BIT AUTO
set_global_assignment -name REMOVE_DUPLICATE_REGISTERS ON
set_global_assignment -name AUTO_RESOURCE_SHARING ON
set_global_assignment -name STRATIXII_OPTIMIZATION_TECHNIQUE AREA
set_global_assignment -name CYCLONE_OPTIMIZATION_TECHNIQUE AREA
set_global_assignment -name STRATIX_OPTIMIZATION_TECHNIQUE AREA
set_global_assignment -name MAXII_OPTIMIZATION_TECHNIQUE AREA
set_global_assignment -name APEX20K_OPTIMIZATION_TECHNIQUE AREA
set_global_assignment -name STATE_MACHINE_PROCESSING "MINIMAL BITS"
set_global_assignment -name MAX7000_FANIN_PER_CELL 100
set_global_assignment -name DO_MIN_ANALYSIS OFF
set_global_assignment -name CUT_OFF_PATHS_BETWEEN_CLOCK_DOMAINS ON
set_global_assignment -name CUT_OFF_READ_DURING_WRITE_PATHS ON
set_global_assignment -name CUT_OFF_IO_PIN_FEEDBACK ON
set_global_assignment -name BLOCK_DESIGN_NAMING MAXPLUSII
set_global_assignment -name MAX7000_PARALLEL_EXPANDER_CHAIN_LENGTH 2
set_global_assignment -name SUPPRESS_REG_MINIMIZATION_MSG ON
set_global_assignment -name ENABLE_DRC_SETTINGS ON


set_global_assignment -name SYNTH_TIMING_DRIVEN_SYNTHESIS OFF
set_global_assignment -name OPTIMIZE_MULTI_CORNER_TIMING ON
set_global_assignment -name FITTER_EFFORT "STANDARD FIT"
set_global_assignment -name ALM_REGISTER_PACKING_EFFORT MEDIUM
set_global_assignment -name ECO_OPTIMIZE_TIMING OFF
set_global_assignment -name ECO_REGENERATE_REPORT OFF
set_global_assignment -name SLOW_SLEW_RATE OFF
set_global_assignment -name FORCE_FITTER_TO_AVOID_PERIPHERY_PLACEMENT_WARNINGS OFF
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

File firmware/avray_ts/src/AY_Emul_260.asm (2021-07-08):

; AY-3-8912 IC emulator version 26.0 for ATMega8/48/88/168/328 16.04.2020
; modified by UzixLS 07.07.2020
;
; Sources for Atmel AVRStudio 5
;
; visit our site for more information
; These source codes are distributed under the GPL v3 license
; If you share these sources you should put the link to web site www.avray.ru
;
; ORIGIN: http://www.avray.ru

; CONFIGURATION VALUES ===================================================
#define CHANNELS 2 		; choose 2 or 3 channel version
#define SPEAKER 1		; use SPEAKER port input on PD1 (0 - no, 1 - yes)
#define VOLUME_TABLE 0	; 0 - AY, 1 - YM, 2 - ALTERNATE volume table
#define MCU_TYPE 2		; 0 - Atmega8, 1 - Atmega48, 2 - Atmega88/168/328
#define TURBOSOUND 1    ; 0 - disabled, 1 - first chip, 2 - second chip
; ========================================================================
; bit numbers:
.equ	b0	= 0x00
.equ	b1	= 0x01
.equ	b2	= 0x02
.equ	b3	= 0x03
.equ	b4	= 0x04
.equ	b5	= 0x05
.equ	b6	= 0x06
.equ	b7	= 0x07


; register variables:
.def	OutA		= r0
.def	OutC		= r1
.def	C1F			= r2
.def	CntN		= r3
.def	OutB		= r4
.def	BusOut1		= r5
.def	NoiseAddon	= r6
.def	C00			= r7
.def	CC0			= r8
.def	BusOut2		= r9
.def	C04			= r10
.def	TMP			= r11
.def	BusData		= r12
.def	SREGSave	= r13
.def	RNGL		= r14
.def	RNGH		= r15
.def	TabE		= r16
.def	EVal		= r17
.def	TabP		= r18
.def	TNLevel		= r19
.def	CntAL		= r20
.def	CntAH		= r21
.def	CntBL		= r22
.def	CntBH		= r23
.def	CntCL		= r24
.def	CntCH		= r25
.def	CntEL		= r26
.def	CntEH		= r27
.def	ADDR		= r30


	.cseg
;------------------------------------------------------
; INTERRUPT VECTORS TABLE
;------------------------------------------------------
	.org	0x0000
	rjmp	_RESET

	.org	INT0addr
	rjmp	_INT0_Handler

	.org	INT1addr
 	rjmp	_INT1_Handler

#if TURBOSOUND == 0
	.org	URXCaddr
	rjmp	_USART_RX_COMPLETE
#endif

;------------------------------------------------------

#if VOLUME_TABLE == 0
	Volumes: ; volume table for amplitude
		.db 0,1,1,1,2,2,3,5,6,9,13,17,22,29,36,45 // AY_TABLE
	EVolumes: ; volume table for envelopes
		.db 0,0,1,1,1,1,1,1,2,2,2,2,3,3,5,5,6,6,7,9,11,13,15,17,19,22,25,29,32,36,40,45 // AY_TABLE
#elif VOLUME_TABLE == 1
	Volumes: ; volume table for amplitude
		.db 0,1,1,1,2,2,3,4,5,7,10,13,18,24,34,45 // YM_TABLE
	EVolumes: ; volume table for envelopes
		.db 0,0,1,1,1,1,1,1,2,2,2,2,2,3,3,4,4,5,6,7,8,10,11,13,15,18,21,24,29,34,40,45 // YM_TABLE
#elif VOLUME_TABLE == 2
	Volumes: ; volume table for amplitude
		.db 0,1,2,3,4,5,6,7,9,11,13,16,22,31,42,58 // ALT_TABLE
	EVolumes: ; volume table for envelopes
		.db 0,1,1,2,3,4,5,6,7,8,9,10,11,12,13,14,15,16,17,18,20,22,24,26,28,30,33,36,40,45,51,58 // ALT_TABLE
#endif


; envelope codes, bit0 - attack, bit1 - invert on next cycle, bit2 - stop generator on next cycle
Envelopes:
	.db 7,7,7,7,4,4,4,4,1,7,3,5,0,6,2,4

; mask applied to registers values after receiving
RegsMask:
	.db 0xFF,0x0F,0xFF,0x0F,0xFF,0x0F,0x1F,0xFF,0x1F,0x1F,0x1F,0xFF,0xFF,0x0F,0xFF,0xFF


;==========================================================
_INT0_Handler:					; 4 cycle to enter interrupt
	sbic	PinD,b3				; check BDIR bit, skip next if clear // 1 cycle
	rjmp	LATCH_REG_ADDR0	// 2 cycle
	; [= READ MODE =] (BC1=1,BDIR=0) 350ns max to set data bus, 8 cycles to set
	; 8 * 37ns = 296ns for 27MHz O.K.
	; 8 * 40ns = 320ns for 25MHz O.K.
	; 8 * 42ns = 336ns for 24MHz O.K.
	; 8 * 50ns = 400ns for 20MHz !!!!
	; turn pins to output
	out		DDRD,BusOut2		// 1 cycle
	out		DDRC,BusOut1		// 1 cycle	
LOOP_NOT_INACTIVE:				// loop while BC1=1
	; 400ns max for release data bus, 9 cycles min
	; 9 * 50 = 450ns for 20MHz !!!!
	; 9 * 42 = 378ns for 24MHz O.K.
	; 9 * 40 = 360ns for 25MHz O.K.
	; 9 * 37 = 333ns for 27MHz O.K.
	sbic	PinD,b2	// 1 cycle
	rjmp	LOOP_NOT_INACTIVE	// 2 cycle
	; turn pins to input
	out		DDRC,C00			// 1 cycle
	out		DDRD,C00			// 1 cycle
	reti						; 4 cycle to leave interrupt

LATCH_REG_ADDR0:
	// LATCH ADDRESS MODE in INT 0 (BC1=1, BDIR=1) ====
#if TURBOSOUND == 0
	in	ADDR,PinC		; receive register number
#else
	in	BusData,PinC		; receive register number
	sbic	PIND, b7
	rjmp	loc_3C
	mov	ADDR, BusData
#endif
	ldd	BusOut1,Z+0x20		; load value from SRAM
	ldd	BusOut2,Z+0x30		; load value from SRAM
#if MCU_TYPE == 0
	out	GIFR,CC0		; reset ext. interrupt flags
#else
	out	EIFR,YH		; reset ext. interrupt flags
#endif
	reti

#if TURBOSOUND != 0
loc_3C:
	bst	BusData, 0
	bld	TNLevel, 6
#if MCU_TYPE == 0
	out	GIFR,CC0		; reset ext. interrupt flags
#else
	out	EIFR,YH		; reset ext. interrupt flags
#endif
	reti
#endif

;==========================================================
_INT1_Handler:	// 4 cycle to enter interrupt
	in		BusData,PinC
	sbic	PinD,b2			// 1 cycle
	rjmp	LATCH_REG_ADDR1	// 2 cycle
#if TURBOSOUND == 1
	sbrs	TNLevel, 6
	rjmp	INT1_RETI
#elif TURBOSOUND == 2
	sbrc	TNLevel, 6
	rjmp	INT1_RETI
#endif
	; [= WRITE REGISTER MODE =] (BC=0, BDIR=1) ============= // 33 cycles
	; 1950 ns min
	; 33 * 50 = 1650ns for 20MHz O.K.
	; 33 * 42 = 1386ns for 24MHz O.K.
	; 33 * 40 = 1320ns for 25MHz O.K.
	; 33 * 37 = 1221ns for 27MHz O.K.
	in		BusOut1,PinD		// 1 cycle
	in		SREGSave,SREG		; save SREG	// 1 cycle
	and		BusOut1,CC0			// 1 cycle
	or		BusData,BusOut1		; construct register value from 2 ports // 1 cycle
	mov		BusOut1,BusData		// 1 cycle
	com		BusOut1				; invert register value	// 1 cycle
	std		Z+0x20,BusOut1		; put inverted register value to SRAM for read mode // 2 cycle

	ld		BusOut2,Z         	; Load register mask from SRAM // 2 cycle
	and		BusData,BusOut2		; apply register mask // 1 cycle

	mov		BusOut2,BusOut1		// 1 cycle
	and		BusOut2,CC0			// 1 cycle
	std		Z+0x30,BusOut2		; put inverted register value to SRAM for read mode (2 high bits) // 2 cycle
	std		Z+0x10,BusData		; put register value to SRAM	// 2 cycle
	cpi		ADDR,0x0D			; check for register 13	// 1 cycle
	brne	NO_ENVELOPE_CHANGED_P	// 1 cycle
	ori		TNLevel,0x80		; set flag that register 13 changed // 1 cycle
NO_ENVELOPE_CHANGED_P:
	out		SREG,SREGSave		// 1 cycle
INT1_RETI:
	reti						; 4 cycle to leave interrupt

LATCH_REG_ADDR1:
	; [= LATCH ADDRESS MODE =] (BC1=1, BDIR=1) 350ns min, 16 cycles
	; 16 * 50 = 800ns for 20MHz mb O.K., but hz :)))
	; 16 * 42 = 672ns for 24MHz mb O.K.
	; 16 * 40 = 640ns for 25MHz mb O.K.
	; 16 * 37 = 592ns for 27MHz mb O.K.
#if TURBOSOUND == 1
	sbic	PIND, PIND7
	rjmp	loc_60
	sbrs	TNLevel, 6
	rjmp	LATCH_REG_ADDR1_RETI
#elif TURBOSOUND == 2
	sbic	PIND, PIND7
	rjmp	loc_60
	sbrc	TNLevel, 6
	rjmp	LATCH_REG_ADDR1_RETI
#endif
	mov		ADDR,BusData	; receive register number
	ldd		BusOut1,Z+0x20		; load value from SRAM	// 2 cycle
	ldd		BusOut2,Z+0x30		; load value from SRAM	// 2 cycle
LATCH_REG_ADDR1_RETI:
#if MCU_TYPE == 0
	out	GIFR,CC0		; reset ext. interrupt flags
#else
	out	EIFR,ZH		; reset ext. interrupt flags
#endif
	reti						; 4 cycle to leave interrupt

#if TURBOSOUND != 0
loc_60:
	bst	BusData, 0
	bld	TNLevel, 6
#if MCU_TYPE == 0
	out	GIFR,CC0		; reset ext. interrupt flags
#else
	out	EIFR,ZH		; reset ext. interrupt flags
#endif
	reti
#endif
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

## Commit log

2019-07-14 initial revision
    [karabas-nano-revA.kicad_pcb, karabas-nano-revA.sch, karabas-nano-revB.kicad_pcb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]
2019-07-14 revB cpld firmware prototype
2019-07-29 added DivMMC edition
    [ESXDOS.CFG, TRDOS.CFG]
2019-08-17 revC, initial revision
    [karabas-nano-revC.kicad_pcb, karabas-nano-revC.sch]
2019-08-18 final revision rev.C
    [karabas-nano-revC.kicad_pcb, karabas-nano-revC.sch]
2019-08-18 latest schematics
    [karabas-nano-revC.sch]
2019-08-18 gerbers revC
2019-09-10 Delete karabas-nano-gerbers-revC.zip
    Broken PLCC32 footprint
2019-09-10 Fixed PLCC32 footprint
    [karabas-nano-revC.kicad_pcb]
2019-10-26 pcb rev.D
    [karabas-nano-revD.kicad_pcb, karabas-nano-revD.sch]
2020-01-19 latest fixes
    [karabas-nano-revD.kicad_pcb]
2020-01-19 Universal (configurable) firmware for EPM7512 with DivMMC, UART, Timex video modes
2020-01-19 added src gitignore to filter pof binaries
2020-04-09 new release for EPM3256 with UART on AY port A
2020-04-09 Z-Controller release with UART on AY port A for EPM3256
2020-04-12 wifi addon PCB rev.A for karabas-nano
    [wifi_revA.kicad_pcb, wifi_revA.sch]
2020-04-12 Rev.E pcb with ESP-12 module
    [karabas-nano-revE.kicad_pcb, karabas-nano-revE.sch]
2020-05-25 Added gerbers rev.F
2020-05-25 rev.F - initial revision
    [karabas-nano-revF.kicad_pcb, karabas-nano-revF.sch]
2020-05-25 removed rev.E
    [karabas-nano-revE.kicad_pcb, karabas-nano-revE.sch]
2020-06-01 New PCB rev.G
    [karabas-nano-revG.kicad_pcb, karabas-nano-revG.sch]
2020-06-04 reverted rev.E materials
    [karabas-nano-revE.kicad_pcb, karabas-nano-revE.sch]
2020-06-28 Removed unused ZX UNO UART and timex modes
2020-06-28 fixed out of sync between schematics and pcb
    [karabas-nano-revE.kicad_pcb, karabas-nano-revE.sch]
2020-06-28 removed zx uno uart code
2021-02-28 revH. initial version
    [karabas-nano-revH.kicad_pcb, karabas-nano-revH.sch]
2021-03-01 Added 3.3/5v selectors for memory and generator
    [karabas-nano-revH.kicad_pcb, karabas-nano-revH.sch]
2021-03-01 small improvements
    [karabas-nano-revH.kicad_pcb]
2021-07-08 rev.I (#2)
    * added .gitattributes
    * updated .gitignore for kicad 6
    * added pcb rev.I (work in progress)
    * upload final pcb rev.I files
    * add avr turbosound firmware for rev.I
    [karabas-nano-revI.kicad_pcb, karabas-nano-revI.kicad_sch]
2021-07-08 update rev.I gerbers (#3)
    [karabas-nano-revI.kicad_pcb]
2021-07-09 Updated 3d models on revI board
    [karabas-nano-revI.kicad_pcb, karabas-nano-revI.kicad_sch]
2021-07-10 Small improvements: moved RN3 outside the plcc32 socket, rerouted vias under logo
    [karabas-nano-revI.kicad_pcb]
2021-07-26 Changed label due to PCBWay violations
    [karabas-nano-revI.kicad_pcb]
2021-11-15 Added pcb rev.J
    [karabas-nano-revJ.kicad_pcb, karabas-nano-revJ.kicad_sch]
2021-11-15 Added revJ schematics
    [karabas-nano-revJ.kicad_pcb]
2021-11-15 revJ gerbers
2022-06-02 Refactored roms
    [ESXDOS.CFG]
2022-06-03 updated esxdos to 0.8.9
    [ESXDOS.CFG]
2022-08-05 Added a photos of the assembled PCB Rev. H by Xoomoh

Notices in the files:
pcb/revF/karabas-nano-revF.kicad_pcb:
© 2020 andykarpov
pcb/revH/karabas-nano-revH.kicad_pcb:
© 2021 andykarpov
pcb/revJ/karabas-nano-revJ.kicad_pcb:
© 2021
